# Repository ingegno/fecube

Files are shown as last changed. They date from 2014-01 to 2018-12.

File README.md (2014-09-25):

Manual sketches
===============
You can find the sketches from the manual on the [sketches overview page.](manual/sketches.md)

Ingegno Fe Cube
===============

The Ingegno Fe Cube is a RGB LED cube consisting of 9 LEDS, so like the Iron metal a [Cubic crystal system](http://en.wikipedia.org/wiki/Cubic_crystal_system)

A Fe Led Cube is driven with an Arduino. It can be used as an educational package into Arduino and making skills like lasercutting and 3D printing. This repository contains 

1. Data for a Scribus manual in English and Dutch (Italian planned)
2. Accompaning Arduino sketches to learn how the Cube can be programmed
3. The final complete sketch to load on a Fe cube and interact with it

There are many LED cubes available, and many manuals to create one exist. Nevertheless, in our view there was still a gap to be filled. A LED cube is ideal to impress visitors with, but we want to make it clear that this is a project within the grasp of beginners. The construction is not hard, and the programming can be kept simple (at least the parts the user would like to change). Hence a manual to go from no knowledge to a working Fe LED Cube.

Specific in the Arduino implementation is that it is shot based, so not a pattern table as is common. A shot that can load a pattern is present though for simple use. Next there is an event system to interact with the environment. In the Basic version this is a push button. In the Interactive version a distance sensor is added.

Prototypes
==========

The cube is a work in progress. Current protypes:

Prototype 3: Basic version
--------------------------
A lasercut frame, with plexiglass top. 3D printed optional cover. A pushbutton to interact with the cube: switch on/off and selecting an effect

Third prototype: basic version
Third prototype: basic version - no cover
Third prototype: basic version - different effect

Prototype 02
------------
A soldering board used to hold the components. In the future this must be hidden at the backside, now visible.

Second prototype

Prototype 01
------------
Based on conductive ink. Working, but pins come loose too easily

Firstprototype

The Manual
==========
The manual is aimed for use in Arduino courses. It starts with the basis: 

1. How to make a LED function with Arduino
2. Extend to handle a RGB LED
3. Create effects with the LED in a frame based manner
4. Extend to a FE Cube on a breadboard
5. Construct the FE Cube
6. Extend the code to generate effects on the FE Cube

Cool stuff the Cube can do
==========================
Some of the cool stuff you can do with the cube

1. The obvious use: use it as a light in the dark!
2. Double click to use it as dice roll. Currently 3 D6 dices are rolled
3. Show the theory of color mixing: two or more colors are blinked faster and faster. What color will result?
4. More to come ....

This course was created for use in an [Ingegno](http://ingegno.be) workshop. If you use it, send us a thumbs up if you liked it!

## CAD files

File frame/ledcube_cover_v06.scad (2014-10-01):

// Licence: Creative Commons, Attribution
// Created: 04-2014 by bmcage http://www.thingiverse.com/bmcage

// An LED lamp holder for easter

//diameter of the horizontal circle in mm
diameter = 100;  //[10:100]
//vertical scale factor to make it an egge (choose number from 1 to 2)
eggscale = 1.2;
//single shell thickness, take your nozzle diameter as minimum
th_shell = 0.4;
//base cylinder diameter in mm.
base_diam = 90; //[5:50]
//base extra height under egg
base_extra_height=2; // [0:20]
//The part to generate. Print both for rigidity, or increase shell thickness if only one!
part="both"; // [inner,outer,both]
//pattern to imprint on the egg
pattern = "circle"; //[triangle,circle,custom]
//size of the pattern as a scale, use something from 0.1 to 10
patternscale = 30; //
//if custom as pattern, the polygon to use as pattern (default here is simple square)
custom_polygon = [[[-1,1],[1,1],[1,-1],[-1,-1]],[[0,1,2,3]] ]; //[draw_polygon:100x100]
//how to put the pattern on the egg: random, a cylinder at the equator, a spiral from bottom to top, a double spiral, or onlyt at the top of the egg
repeattype = "topproject"; //[random, cylinder,spiral,doublespiral,topproject]
patternrepeat = 45;  //[1:100]
//random seed used to generate the pattern
random_seed = 10;  //[0:3200]
//rotate pattern itself around or not
rotate_pattern="true";  //[true,false]
//spiral complete circles from bottom to top
spiral_circles = 4; //[1:10]
//double helix extra offset
dh_angle=45; //[0:180]
//cuttoff below this height
h_cuttoff = 20; //[0:50]
//text to write on equator
text = "My LED Cube";
//fraction of the circumference to use for the text (value between 0.1 and 0.9)
textcircum = 0.9;
//show dxf
showdxf = "False";  //[True,False]
//scale the pattern
dxfscale  =0.06;
//dxf file to load
dxf_file= "/home/benny/Documents/kinderen/saya/toothless_v4.dxf";
dxfrepeattype = "cylinder"; //[cylinder,topproject]
dxfpatternrepeat = 6;  //[0:100]
//extra angle over the equator
dxfcilangle = 38; //[-90:90]


use <utils/build_plate.scad>;
use <MCAD/fonts.scad>;

//for display only, doesn't contribute to final object
build_plate_selector = 0; //[0:Replicator 2,1: Replicator,2:Thingomatic,3:Manual]

//when Build Plate Selector is set to "manual" this controls the build plate x dimension
build_plate_manual_x = 100; //[100:400]

//when Build Plate Selector is set to "manual" this controls the build plate y dimension
build_plate_manual_y = 100; //[100:400]

build_plate(build_plate_selector,build_plate_manual_x,build_plate_manual_y); 

//code begins, dummy module to indicate this
module test(){
  echo("test");
}

// sin(alpha) = R_C/R_S, cos(alpha) = sqrt(1- (R_C/R_S)**2)
// cutoff sphere is R_S*(1-cos(alpha)
sinalpha = base_diam/2 / (diameter/2);
cosalpha = sqrt(1-pow(sinalpha,2));
rcuttoff = diameter/2*(1-cosalpha);

module easterlamp(diam, transdist)
{
translate([0,0,transdist]) 
 	{
	 difference() 
		{
 		 scale([1,1,eggscale]) sphere(r = diam/2, $fn=60);
	 	 union(){
 		 scale([1,1,eggscale]) sphere(r = diam/2-th_shell*eggscale, $fn=60);
    	 translate([0,0,-eggscale*diam]) cylinder(r=base_diam/2, h=eggscale*diam);
		 }
		}
	}
}

module filledfoot()
{
cylinder(r=base_diam/2, h=base_extra_height+eggscale*rcuttoff+2, $fn=40);
}

module foot()
{
difference()
	{
 	 filledfoot();
 	 translate([0,0,-0.05])cylinder(r=base_diam/2-2*th_shell*eggscale, h=base_extra_height+eggscale*rcuttoff+2.1, $fn=40);
	}
}


module singlepattern()
{
//translate([0,0,eggscale*diameter/2+base_extra_height-0.1])
	{scale([patternscale,patternscale,1])
		{
		 if (pattern == "triangle")
		 { translate([0,0,1*eggscale*diameter/4]) linear_extrude(height = eggscale*diameter/4, convexity = 10)
           polygon(points=[[-1,0],[0,1],[1,0]]);
		 }
		 if (pattern == "circle")
		 { translate([0,0,1*eggscale*diameter/4]) cylinder(r=1, h=eggscale*diameter/4, $fn=10);
		 }
		 if (pattern =="custom")
		 {translate([0,0,1*eggscale*diameter/4]) linear_extrude(height = eggscale*diameter/4, convexity = 10)
			 polygon(points = custom_polygon[0], paths = custom_polygon[1]);
		 }
	   }
	}
}

module dxfpattern()
{
rotate([0,0,90])
scale([dxfscale,dxfscale,1])
translate([0,0,1*eggscale*diameter/4])
linear_extrude(height = eggscale*diameter/4)
   import (file = dxf_file);
}

module rotsinglepattern(rotangle)
{
 if (rotate_pattern=="true")
	{rotate([0,0,rotangle]) singlepattern();
	} else {
	 singlepattern();
	}
}

module manydxfpatterns()
{

if (showdxf == "True")
{
union()
 {
 if (dxfrepeattype == "cylinder")
  {
  for (i=[1:dxfpatternrepeat])
	{
	 translate([0,0,eggscale*diameter/2+base_extra_height-0.1])
		rotate([0,90-dxfcilangle,i*360/dxfpatternrepeat]) 
		{
		 dxfpattern();
	 	}
	}
  }
 if (dxfrepeattype == "topproject")
  {
	{
	 translate([0,0,eggscale*diameter/2+base_extra_height-0.1])
		{
		 dxfpattern();
	 	}
	}
  }
 }
}
}

module manypatterns()
{
random_numbers=rands(0,360,2*patternrepeat,random_seed);
union(){
 if (repeattype == "random")
  {
  for (i=[1:patternrepeat])
	{
	 translate([0,0,eggscale*diameter/2+base_extra_height-0.1])
		rotate([0,10+random_numbers[i-1]/360*160,random_numbers[i]]) 
		{
		 rotsinglepattern(random_numbers[i]);
	 	}
	}
  }
 if (repeattype == "cylinder")
  {
  for (i=[1:patternrepeat])
	{
	 translate([0,0,eggscale*diameter/2+base_extra_height-0.1])
		rotate([0,90,i*360/patternrepeat]) 
		{
		 rotsinglepattern(random_numbers[i]);
	 	}
	}
  }
 if (repeattype == "topproject")
  {
  //for (i=[1:patternrepeat])
	{
	 translate([0,0,eggscale*diameter/2+base_extra_height-0.1])
		//rotate([0,10+random_numbers[i-1]/360*160,random_numbers[i]]) 
		{
		 rotsinglepattern(random_numbers[0]);
	 	}
	}
  }
 if (repeattype == "spiral" || repeattype == "doublespiral")
  {
  for (i=[1:patternrepeat])
	{
	 translate([0,0,eggscale*diameter/2+base_extra_height-0.1])
		rotate([0,10+i*160/patternrepeat, i*360/patternrepeat*spiral_circles]) 
		{
		 rotsinglepattern(random_numbers[i]);
	 	}
	}
  if (repeattype == "doublespiral")
   {
   for (i=[1:patternrepeat])
	 {translate([0,0,eggscale*diameter/2+base_extra_height-0.1]) 
	  //difference()
     { 
		 rotate([0,10+i*160/patternrepeat, -i*360/patternrepeat*spiral_circles+dh_angle]) 
		 {
		  rotsinglepattern(random_numbers[i]);
	 	 }
	  //cube([diameter/2,diameter/2,diameter/2], center=true);
     }
	 }
   }
  }
 }
}


//process the text, we have beta_1 for the symbol, use beta_2 for border!
thisFont=8bit_polyfont();
x_shift=thisFont[0][0];
y_shift=thisFont[0][1];
theseIndicies=search(text,thisFont[2],1,1);
wordlength = (len(theseIndicies));

factorygap = 3;
scale_x = PI * diameter * textcircum/wordlength / x_shift;
scale_y = (diameter*eggscale/5) / y_shift;
//thicknessword = text_thickness * nozzlediam;

// Create the Text
module alltext() {
    for( j=[0:(len(theseIndicies)-1)] ) 
        {
			translate([0,0,eggscale*diameter/2+base_extra_height-0.1])
			rotate([90,0,j*360 * textcircum/wordlength])
        	translate([0,0,2.8*eggscale*diameter/8]) scale([scale_x,scale_y,1]){
          linear_extrude(height=1.2*eggscale*diameter/8) 
            polygon(points=thisFont[2][theseIndicies[j]][6][0],paths=thisFont[2][theseIndicies[j]][6][1]);
        }
      }
}

centeregg = eggscale*diameter/2+base_extra_height-0.1;

module fullobject()
{
if (showdxf == "True")
{
  dxfpattern();
}
if (part =="both")
	{
	 easterlamp(diameter-2*th_shell*eggscale+0.05, centeregg);
	}

if (part =="inner")
	{difference() {
   	 easterlamp(diameter-2*th_shell*eggscale-0.05, centeregg);
		 foot();
	 }
	}

if (part == "outer" || part == "both")
	{
 	 foot();
	 difference()
	 {
		color("Blue",0.5) easterlamp(diameter, centeregg);
		manypatterns();
		manydxfpatterns();
      alltext();
	 }
	}
}


//module easterlamp()
//{
if (h_cuttoff>0)
{
translate([0,0,-h_cuttoff+0.01])
 difference()
	{
	 fullobject();
	 translate([-diameter/2,-diameter/2,-0.01]) cube([diameter, diameter,h_cuttoff]);
	}
} else {
 fullobject();
}
//}
//alltext();
//easterlamp();
//manypatterns();

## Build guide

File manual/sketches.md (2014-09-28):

Arduino Sketches Manual
=======================

The basic sketches

1.  [RGB LED](../sketches/n01_RGB/n01_RGB.ino)

2.  [Mixing colors with RGB LED](../sketches/n02_RGB_mixing/n02_RGB_mixing.ino)

3.  [Multiplexing with 2 RGB LED](../sketches/n03_RGB_multiplex/n03_RGB_multiplex.ino)

4.  Extra: [Procedural effect on 2 RGB LED](../sketches/n04_RGB_procedural/n04_RGB_procedural.ino)

5.  [Pushbutton and RGB LED](../sketches/n05_RGB_pushbtn/n05_RGB_pushbtn.ino)

The Fe Cube sketches

1.  [Basic effect on the Fe Cube](../sketches/n10_cube_test/n10_cube_test.ino)
2.  [Pushbutton and Fe Cube](../sketches/n11_cube_pushbtn_test/n11_cube_pushbtn_test.ino)
3.  [Fe Cube with th fecube library](../sketches/n12_cube_library_test/n12_cube_library_test.ino)
4.  [Fe Cube final showtime sketch](../sketches/n13_cube_showtime/n13_cube_showtime.ino)

The fecube library: [fecube.h](../sketches/n12_cube_library_test/fecube.h)

List of effects for use with the library: [sketches](../effects)

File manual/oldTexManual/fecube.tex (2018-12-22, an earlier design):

\section{\engt{Introduction} \nedt{Introductie}}
\eng{In this booklet we will show how to create the Fe Cube. You will learn about LEDs, the Arduino, multiplexing, soldering, color theory, and more! You can buy a kit from Ingegno.be, or buy your components somewhere else.

The code of this manual can be found on \href{https://github.com/ingegno/linefollower1}{the Ingegno github page}.
}

\ned{In dit boekje zullen we je leren hoe je de Fe Cube kunt maken. Je zal leren over LEDs, de Arduino, multiplexing, solderen, kleurentheorie, en meer! Je kan een kit kopen met alle onderdelen van Ingegno.be, of je kan je eigen stukken gebruiken.

De code van deze handleiding kan gevonden worden op \href{https://github.com/ingegno/linefollower1}{de Ingegno github pagina}.
}

\subsection{\engt{The components} \nedt{De componenten}}
\eng{We will need the following components: 
\begin{enumerate}
 \item A breadboard
 \item 9 RGB-LED + 3 extra (we assume common cathode for the cube)
 \item 1 big RGB-LED (we assume common anode)
 \item 3 NPN + 1 extra (2N3904 normally)
 \item 1 pushbutton
 \item 9 220 $\Omega$ resistors + 3 extra
 \item 1 10k-20k $\Omega$, so 10000-20000$\Omega$, resistor
 \item many wires
 \item lasercut base for the cube
 \item iron wire pillars for the cube
 \item soldering plate for fixed components + connecter parts
\end{enumerate}
You will also need a soldering iron, and optionally you can make a cover for the cube, eg using 3D printing.

For an overview of meaning of the components, see the cheat sheet distributed seperately.
}

\ned{We zullen volgende componenten gebruiken: 
\begin{enumerate}
 \item Een schakelbord (Breadboard)
 \item 9 RGB-LED + 3 extra (we veronderstellen gemeenschappelijke kathode voor de kubus)
 \item 1 grote RGB-LED (we veronderstellen gemeenschappelijke anode)
 \item 3 NPN + 1 extra (2N3904 of gelijkaardig)
 \item 1 drukknop
 \item 9 220 $\Omega$ weerstanden + 3 extra
 \item 1 10k-20k$\Omega$ oftewel 10000-20000$\Omega$ weerstand
 \item veel draden
 \item lasercut basis voor de kubus
 \item ijzerdraad pilaren voor de kubus
 \item soldering plaat voor vaste componenten + connectiestukken
\end{enumerate}
Je zal ook een soldeerijzer nodig hebben, en optioneel kun je een afdekking maken voor de kubus, bv via 3D printen of in plexi met de lasercutter.

Voor een overzicht van de betekenis van de componenten, zie het overzicht die je apart gekregen hebt.
}

\subsection{Arduino}
\eng{We will make intensive use of Arduino, so you need to install the \href{http://Arduino.cc}{Arduino software}. Once installed, you can connect the Arduino board to your PC via de \textsc{usb} port.  In the programming environment you installed you can write programs, and load those on the Arduino board. They will be executed there as long as the Arduino has power.

}
\ned{We zullen intensief gebruik maken van Arduino, dus moet je de \href{http://Arduino.cc}{Arduino software} installeren op je laptop.
Eenmaal geinstalleerd kun je nu je Arduino bord koppelen aan je computer via de \textsc{usb} poort. In de programmeeromgeving van Arduino kun je programma's schrijven en die opladen naar de Arduino, waar ze dan uitgevoerd worden zolang er stroom is.
}

\subsection{\engt{Programming with Arduino} \nedt{Programmeren met Arduino}}
\eng{A programming language needs to be understood by a computer. Unfortunately computers are still a little bit dumb, so you are not allowed to make errors! It's like a writing contest in which you need to obtain a 10/10 every time. So take time to learn the form of the language. See the specific sheet 'Programming with Arduino' distributed with this manual.}

\ned{Een programmeertaal moet verstaan worden door een computer. Spijtig genoeg zijn computers nog altijd een beetje dom, dus mag je geen enkele fout maken! Het is zoals een dictee waar je altijd 10/10 moet halen. Neem dus de tijd om de structuur en taal van de Arduino te leren. Zie de blaadjes 'Programmeren met Arduino' die je bij deze gids kan downloaden.}

\section{\engt{Lesson 1: One LED Circuit} \nedt{Les 1: \'E\'en LED circuit}}
\eng{We will make a circuit with one LED, which we will program to blink. The Arduino outputs 5 Volt, while the LED is designed for 3 Volt. Hence we will use a resistor to reduce the voltage over the LED. You can calculate the resistor you need with \url{http://led.linear1.org/1led.wiz}.}

\ned{We maken een circuit met \'{e}\'{e}n enkele LED, welke we zullen programmeren om te pinken. De Arduino levert 5 Volt, terwijl de LED gemaakt is voor 3 Volt. We moeten dus een weerstand gebruiken om het voltage over de LED te verminderen.  Je kan de weerstand die je nodig hebt berekenen met  \url{http://led.linear1.org/1led.wiz}.}

\subsection{\engt{One pin} \nedt{\'E\'en pin}}
\eng{Make the circuit as indicated in Fig.~\ref{f:lesson1_onepin}. Use your breadboard and wires to make the connections. A wire from pin 2 to row 10 on the breadboard. Then the resistor of R=330 $\Omega$ from row 10 to row 6, the LED anode from row 6 to row 5, and finally a wire from row 5 to the GND pin on the Arduino. You can see }

\ned{Maak het circuit zoals gegeven in Fig.~\ref{f:lesson1_onepin}. Gebruik je schakelbord en draden om de connecties te maken. Dus hier, een draad van pin 2 naar rij 10 op je schakelbord. Dan de resistor met weerstand R=330 $\Omega$  van rij 10 naar rij 6, de LED anode van rij 6 naar rij 5, en uiteindelijk een draad van rij 5 naar de GND pin op de Arduino.}

\begin{figure}
  \centering
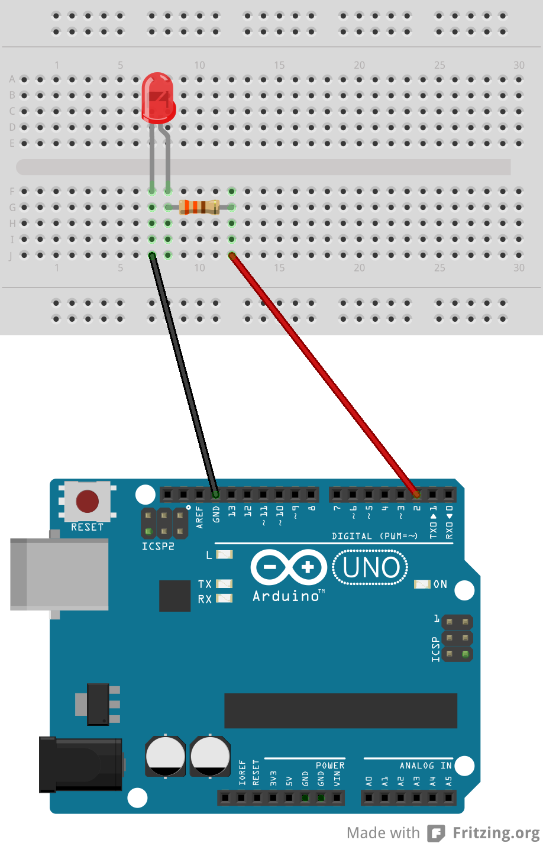
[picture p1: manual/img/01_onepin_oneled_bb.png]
  \ \ 
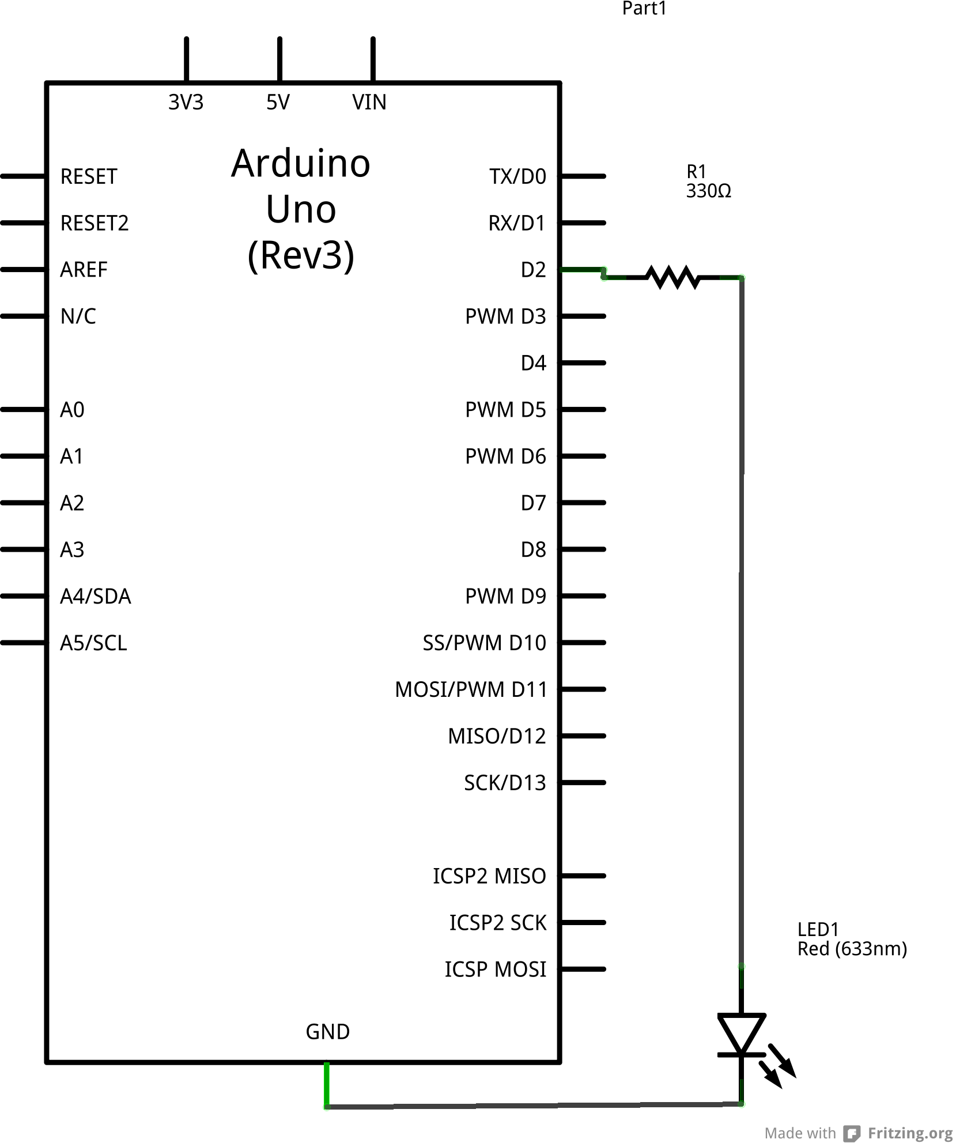
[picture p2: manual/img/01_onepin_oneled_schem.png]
    
\caption{\engt{Using one pin and the ground, we can make a LED burn. Left with breadboard, right as a schematic}
\nedt{Met een pin en de grond kunnen we een LED doen branden. Links met breadboard, rechts als schema.}}
\label{f:lesson1_onepin}       % Give a unique label
\end{figure}

\eng{We now need to write a program that sets the power to pin 2 on and off every second, so that the LED blinks. You see the code in Code \ref{c:l1_a}.}
\ned{Nu moeten we een programma schrijven dat de stroom naar pin 2 aan en af zet elke seconde, zodat de LED pinkt. Je vindt de code in Code \ref{c:l1_a}.}

\begin{code}\label{c:l1_a}
 \ \newline
\inputardfull{\string"../../sketches/old_versions/v01/Fe_cube_01_led_one_pin/Fe_cube_01_led_one_pin.ino\string"}
\end{code}
\eng{Congratulations, you made your first programmable LED.}
\engo{\begin{doE}
       Change the program so that the LED blinks every 3 seconds, with 1 second off. Next, what does it happen if you blink every 40 milliseconds and every 10 milliseconds?
     \end{doE}
}
\ned{ Proficiat, je hebt je eerste programmeerbare LED gemaakt.}
\nedo{\begin{doN}\begin{enumerate}
                  \item  Verander nu je programma (Code 1) zodat de LED elke 3 seconden pinkt, met 1 seconde af. \\
                  Vervolgens, wat gebeurt er als je elke 40 milliseconden pinkt en als het elke 10 milliseconden pinkt? 
                  \item Wat moet je doen als je twee LED's wilt doen pinken? of afwisselend pinken? 
                  Probeer het eens.
                 \end{enumerate}

          \end{doN}
}
\eng{How does it work? Well, the pins from 1 to 13 can have a HIGH state or a LOW state. HIGH means the pin has 5V of power, while LOW means the pin is in the ground state GND. We say that current flows from the positive voltage of 5V (the + side) to the GND (the - side). This is somewhat annoying as the actual quantum particles used here, called electrons, actually go the other way. So, they flow from the minus to the plus. This because they have themself a negative charge, so they are repelled by the negative GND. Theoretically you could use other quantum particles however! Anyway, the direction of the current, from + to - is just an agreement between scientists. 

The power source here is 5V, which is an indication of how much work you can do. A lot of power means you can do a lot of work! To burn a LED we don't need a lot of power however, so we reduce the power used to burn the LED by adding a resistor. This increases the lifetime of the LED.

The resistor is just that, it resists the flow of the current, and hence the quantum particles loose some of their power going through the resistor. Not only will the particles have less power however, there will also be less particles that can pass the resistor every second, or in other words, the current is also lower. So a resistor will decrease the current, and after passing it there is also less power left to do the rest of the circuit. 

Next comes the LED for the current. All the remaining power will be used to go through the LED and generate light. A LED only produces light if the anode (long leg, +) is connected to the voltage (positive side), and the cathode (short leg) towards the GND side. If you put the LED around (try it!) there will be no light. There will also be very little current going through the LED in this way because not only does it produce no light, it will also resist the current a lot if the anode is connected to the GND. An exploded view of a LED is shown in Figure \ref{f:LED}.}

\ned{Hoe werkt ons circuit? Wel, de pinnen van 1 tot 13 kunnen een HIGH staat en een LOW staat hebben. HIGH betekent dat de pin 5V krachtbron heeft, terwijl LOW betekent dat de pin zich in de grond staat bevindt. We zeggen dat stroom sroomt van de positieve voltage van 5V (de + zijde) naar de GND (de - zijde). dat is een beetje vervelend gezien de echte kwantumdeeltjes die hier gebruikt worden, electronen genoemd, eigenlijk de andere kant op stromen, dus van de min naar de plus. Dit omdat elektronen zelf negatief zijn, en dus afgestoten worden door de negatieve lading van de GND. Theoretisch zou je evenwel andere kwantumdeeltjes kunnen gebruiken! Hoe dan ook, de richting van de stroom, van + naar -, is gewoon een afspraak tussen wetenschappers om geen verwarring te doen ontstaan. 

De krachtbron is hier 5 Volt (5V), wat een indicatie is van hoeveel werk je kan doen. Veel kracht betekent dat je veel werk kan doen! Om een LED te doen branden hebben we evenwel niet veel kracht nodig, dus beperken we die door een resistor toe te voegen die de kracht over de LED zal beperken. Dit verhoogt de levensduur van de LED.

De resistor of weerstand doet wat de naam zegt: het resisteert of weerstaat de stroom. Bijgevolg verliezen de kwantumdeeltjes een deel van hun kracht als ze door een weerstand stromen. Niet alleen zullen de deeltjes minder kracht hebben erna, er zullen ook minder deeltjes passeren elke seconde. De stroom is dus verminderd. Een weerstand of resistor zal dus de stroom verminderen en na het passeren zal er ook nog eens minder kracht over zijn om door de rest van het circuit te stromen.

Daarna komt de LED voor de stroom. Alle overblijvende kracht zal gebruikt worden om door de LED te gaan en licht te genereren. Een LED maakt alleen licht als de anode (lange been, +) is geconnecteerd naar het voltage (de positieve zijde), en de kathode (korte been, -) naar de GND zijde.
Als je de LED ronddraait (probeer het!) zal er geen licht schijnen. Er zal ook maar heel weinig stroom vloeien dan, gezien de LED niet enkel geen licht maakt dan maar ook de stroom sterk zal weerstaan. Een LED in het groot zie je in Figuur \ref{f:LED}.
} 

\begin{figure}
  \centering
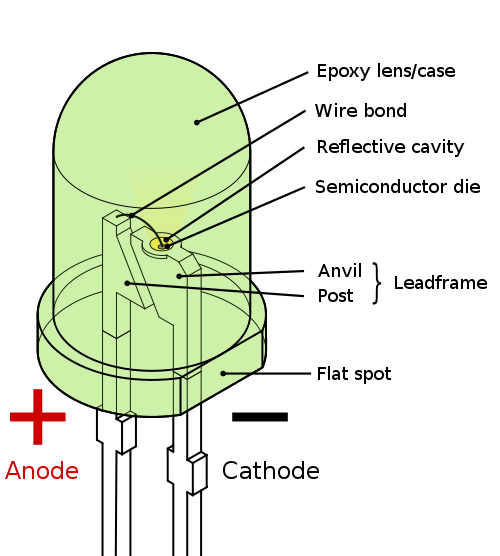
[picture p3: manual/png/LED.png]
  
\caption{\engt{Blow up view of a LED}
\nedt{Een LED in het groot}}
\label{f:LED}       % Give a unique label
\end{figure}

\engo{\begin{doE}
      Study the schematic to the right of Figure \ref{f:lesson1_onepin}. A schematic is often more clear to work with than the wires drawn to the left. Every component has its own symbol. For example, the LED is a triangle ending on a short vertical line, and two small arrows indicating the light that is emitted. The triangle in this symbol can be interpreted as an arrow indicating the direction of the current: from + to -. The light leaves the LED in the same direction.
     \end{doE}
}
\nedo{\begin{doN}
      Bestudeer het schema aan de rechterkant van Figuur  \ref{f:lesson1_onepin}. Een schema is vaak duidelijker om mee te werken dan de draden die je aan de linkerkant ziet. Elke component heeft zijn eigen symbool. Een LED is een driehoek die eindigt op een korte vertikale lijn, en twee kleine pijlen die het licht voorstellen die de LED uitzendt. De driehoek in dit symbool kun je interpreteren als een grote pijl die de richting van de stroom aanduidt: van + naar -. Het licht verlaat de LED in dezelfde richting in het symbool.
     \end{doN}
}

\eng{Do you want to know how the LED produces light? Well, that is quantum physics, something most people never learn. Let's explain a bit. To understand quantum physics, you need to work with the quantum particles, which here are electrons. Remember, the electrons go from GND to the pin 2, so from the cathode (-) to the anode (+) of the LED. 

At the cathode side, the LED has what is called an n-type material. This is a material that has an excess in negative electrons, hence n. At the anode side there is a p-type material. This material has a shortage of electrons, which we call holes: it is the absense of an electron within the material. The p-type material passes current by moving holes around. The n-type material by moving electrons around. 

So, if electrons arrive at the cathode, they create a surplus of electrons, and the electrons are pushed towards the p-type material. There, they fall into a hole, and this is a quantum effect that creates a small quantum of energy, which is a photon, and which we see here as the light of the LED. This effect is called \textit{Electroluminescence}, and only happens from an n-type material to a p-type material. Between other materials that transport electrons, the electrons can loose energy gradually, instead of in quanta. 

Now, after this drop, there are less holes in the p-type material in the direction of the n-type material, so the holes in the p-type material move towards this place so as to rebalance the amount of holes. The resulting shortage of holes at the cathode side then causes an electron to leave the p-type material entirely (the material likes it's amount of holes and wants to keep it like that), creating a new hole there.

If you plug out the LED, rotate it, and plug the LED back in the breadbroard, you connect the n-type material to the positive voltage. The electrons of the n-type material then just flow towards this voltage creating too little electrons in the material. This can only be corrected by an electron leaving the p-type material and like that creating a new hole there and a new electron in the n-type material. However, this clearly does not produce light (as the electron does not fall into a hole), but the electrons also resist a lot against moving from the p-type material to the n-type material (they are comfortable where they are and resist jumping, or seen differently, the material likes it's amount of holes and tries to keep it like that.). 
}
\ned{Je wilt weten hoe de LED licht produceert? Wel, dat is kwantumfysica, en de meeste mensen leren daar nooit over. Laat ons het een beetje uitleggen. Om kwantumfysica te verstaan moet je met kwantumdeeltjes werken, dus hier de elektronen. Weet je nog dat de elektronen stromen van de GND naar de pin 2, dus van de kathode (-) naar de anode (+) van de LED? 

Aan de kathode zijde zit wat we een n-type materiaal noemen. Dit is een ma\-te\-riaal die een overschot aan negatieve electronen heeft, daarom n. Aan de anode zijde zit een p-type materiaal. Dat is een materiaal die een tekort aan elektronen heeft, wat we gaten noemen: het is de afwezigheid van een elektron in het materiaal. Het p-type materiaal laat stroom door door gaten rond te bewegen. Het n-type materiaal laat stroom door elektronen rond te bewegen.

Dus, als elektronen toekomen aan de kathode cre\"eren ze daar een surplus aan elektronen, en de elektronen worden geduwd in de richting van het p-materiaal. Daar aangekomen vallen ze in een van de gaten, en het is dit kwantumeffect dat een klein kwantum aan energie cre\"eert, welke een foton is wat we waarnemen als het licht van de LED. Dit effect noemen we  \textit{Electroluminescentie}, en het gebeurt enkel bij overgang van een elekrton van een  n-type materiaal naar een p-type materiaal. Tussen andere materialen die elektronen doorlaten kunnen de elektronen altijd gradueel hun energie verliezen, in plaats van via een kwantum. 

Nu, na het vallen in het gat zijn er minder gaten in het p-type materiaal aan de kant van het n-type materiaal, dus zullen de gaten bewegen in die richting om terug een gelijke balans in het materiaal te hebben. Hierdoor eindigen we met een tekort aan gaten aan de kathode zijde, welke op zijn beurt ervoor zal zorgen dat een elektron het materiaal zal verlaten (het materiaal houdt van zijn aantal gaten en wil het zo houden), waardoor een nieuw gat ontstaat daar.

Als je de LED omdraait, connecteer je het n-type materiaal aan de positieve krachtbron. De elektronen van het n-type materiaal stromen dan gewoon naar deze krachtbron, zo een tekort aan elektronen veroorzakend daar. Dit kan enkel gecorrigeerd worden door een elektron dat het p-type materiaal verlaat, en zo een nieuw gat cre\"eert, en een nieuw elektron in het n-type materiaal. Dit evenwel zal duidelijk geen licht produceren (gezien het elektron niet in een gat valt), maar de elektronen bieden ook heel veel weerstand in het bewegen van het p-type materiaal naar het n-type materiaal (ze zijn bij wijze van spreken comfortabel waar ze zijn, het materiaal houdt van zijn aantal gaten en wil het zo houden).
}
\begin{figure}
  \centering
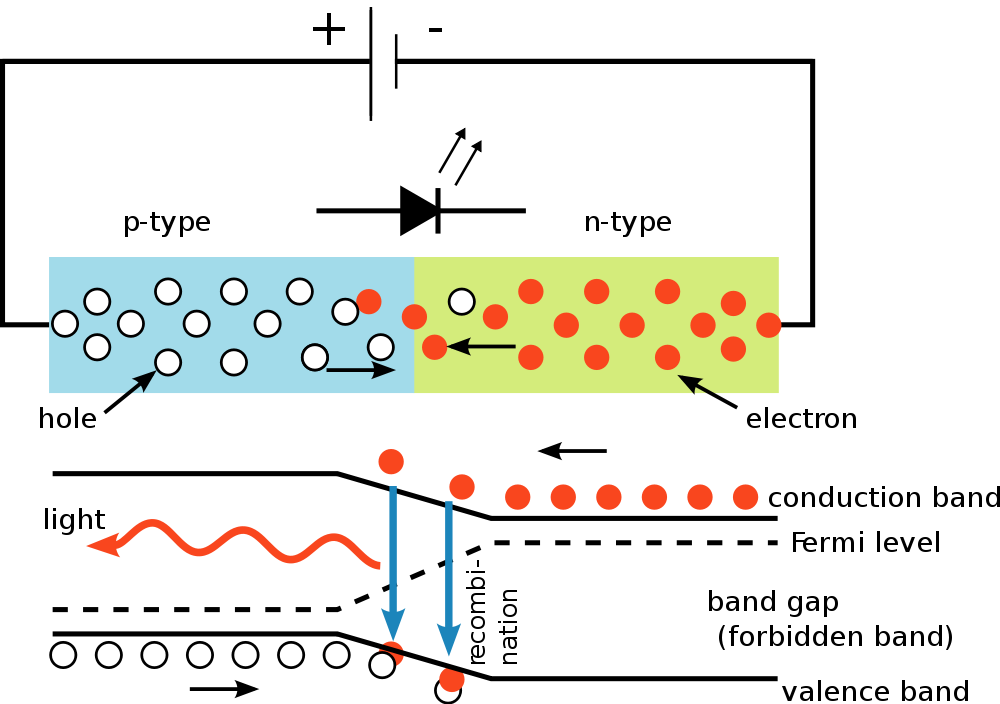
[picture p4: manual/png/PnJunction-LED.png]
  
\caption{\engt{A PN junction as used in a LED}
\nedt{Een PN overgang zoals gebruikt in een LED} (\textcopyright Wikimedia Commons S-kei)}
\label{f:NPJunction}       % Give a unique label
\end{figure}

\subsection{\engt{LED with NPN, two pins} \nedt{LED met NPN, twee pinnen}}
\eng{Controlling the LED worked great, but we will later need the ability to cut off the power on the Cathode (-) side too, so towards the ground (GND). In this section we will learn how to do that. One possibility is to use a switch: a component that is on and off depending on a signal. Just like the light switches you use every day and where the input is the pressure of your hand touching it. We will use the smallest switch possible: an NPN gate. This piece is the half cilindrical black piece with 3 legs in your box, see Fig.~\ref{f:Tr_Pinouts}. 
}

\ned{De LED controleren werkte perfect, maar later zullen we de mogelijkheid willen om de stroom af te sluiten aan de Kathode zijde (-), dus aan de grond (GND). In deze sectie zullen we dat leren. Een mogelijkheid is om een schakelaar te gebruiken: een component die aan of af is afhankelijk van een signaal. Net zoals de lichtschakelaars die je dagelijks gebruikt, en waar de input de druk van je hand is. We zullen de kleinst mogelijke schakelaar gebruiken: een NPN brug. Dit componentje is de halve zwarte cilinder met 3 poten in je doos, zie Fig.~\ref{f:Tr_Pinouts}. 
}

\begin{figure}
  \centering
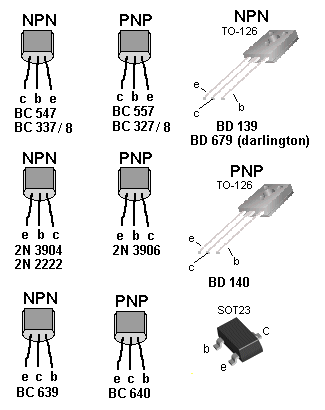
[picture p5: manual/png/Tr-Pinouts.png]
   
\caption{\engt{Different NPN and PNP transistors. There is no standard for the pinouts, so use a datasheet, or try it with a LED like we do. If it does not work, use other legs as in this Picture!}
\nedt{Verschillende NPN en PNP transistoren. Er is geen standaard voor de beentjes, refereer naar een datasheet, of probeer het met een LED zoals wij hier doen. Als het niet werkt, gebruik andere beentjes zoals in deze Figuur!}}
\label{f:Tr_Pinouts}       % Give a unique label
\end{figure}

\eng{As you can see in that figure, there is no standard for identifying the legs of the transistor. Normally, the one you have will have, looking at the flat side of NPN, the left leg as the in-side for the current (C, from collector), the right leg is the out-side (E, from extruder/emitter) that goes to the GND, and the middle leg is the P or positive control (B, from the word base). If there is positive power on the P, the NPN gate is open and current can flow to the ground state. If there is no power on the P, the NPN gate is closed. Our complete circuit is then given in Fig.~\ref{f:lesson1_twopin}}

\ned{Zoals je in die figuur ziet is er geen standaard om de beentjes van een transistor te identifici\"eren. Normaal zal het als volgt zijn voor degene die jij zult gebruiken: hou je het rechtop en kijk je naar het vlakke stuk van de NPN, dan is de linkerpoot de in-zijde voor de stroom (C, van collector, waar er gecollecteerd wordt), de rechterpoot de uitgangzijde (E, van emittor of extruder) die naar de GND gaat, en het middelste been is de P of positieve controle (B, van basis). Als er een positieve stroom is op P, laat de NPN brug stroom door. Is er geen stroom op de P, dan kan er geen stroom door en is het circuit dus onderbroken. Het complete circuit is gegeven in Fig.~\ref{f:lesson1_twopin}.
}

\begin{figure}
  \centering
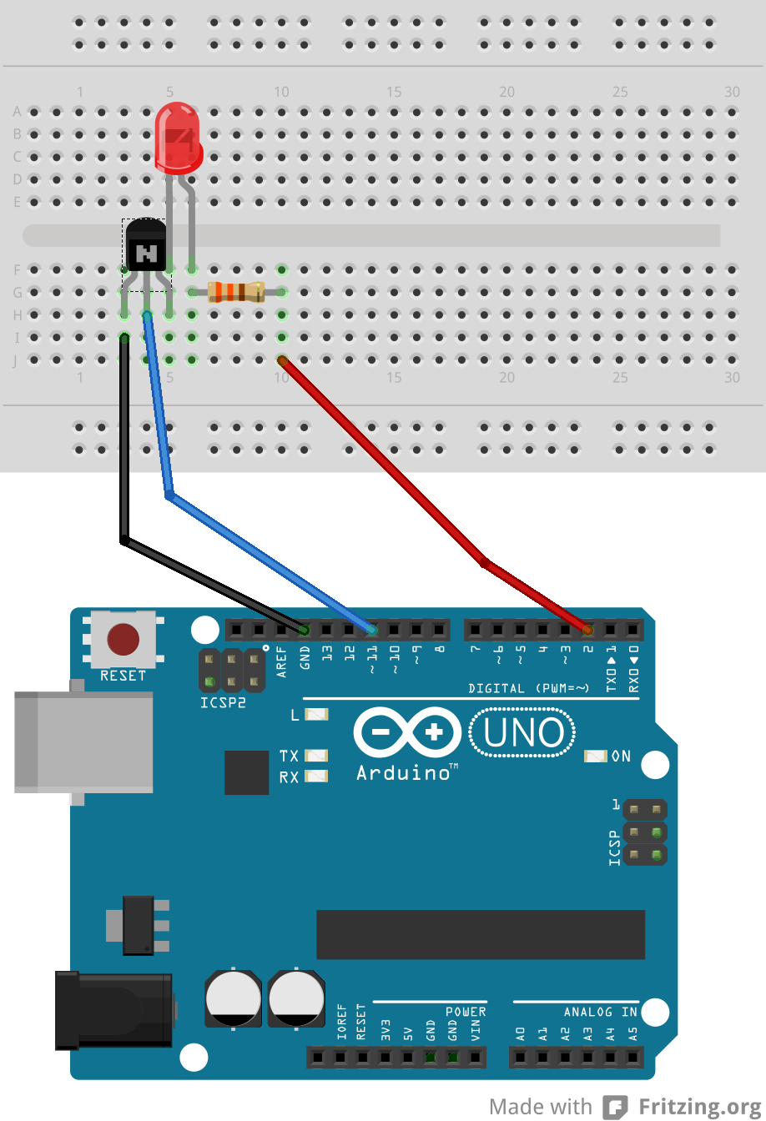
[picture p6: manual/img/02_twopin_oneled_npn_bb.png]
   \ \ 
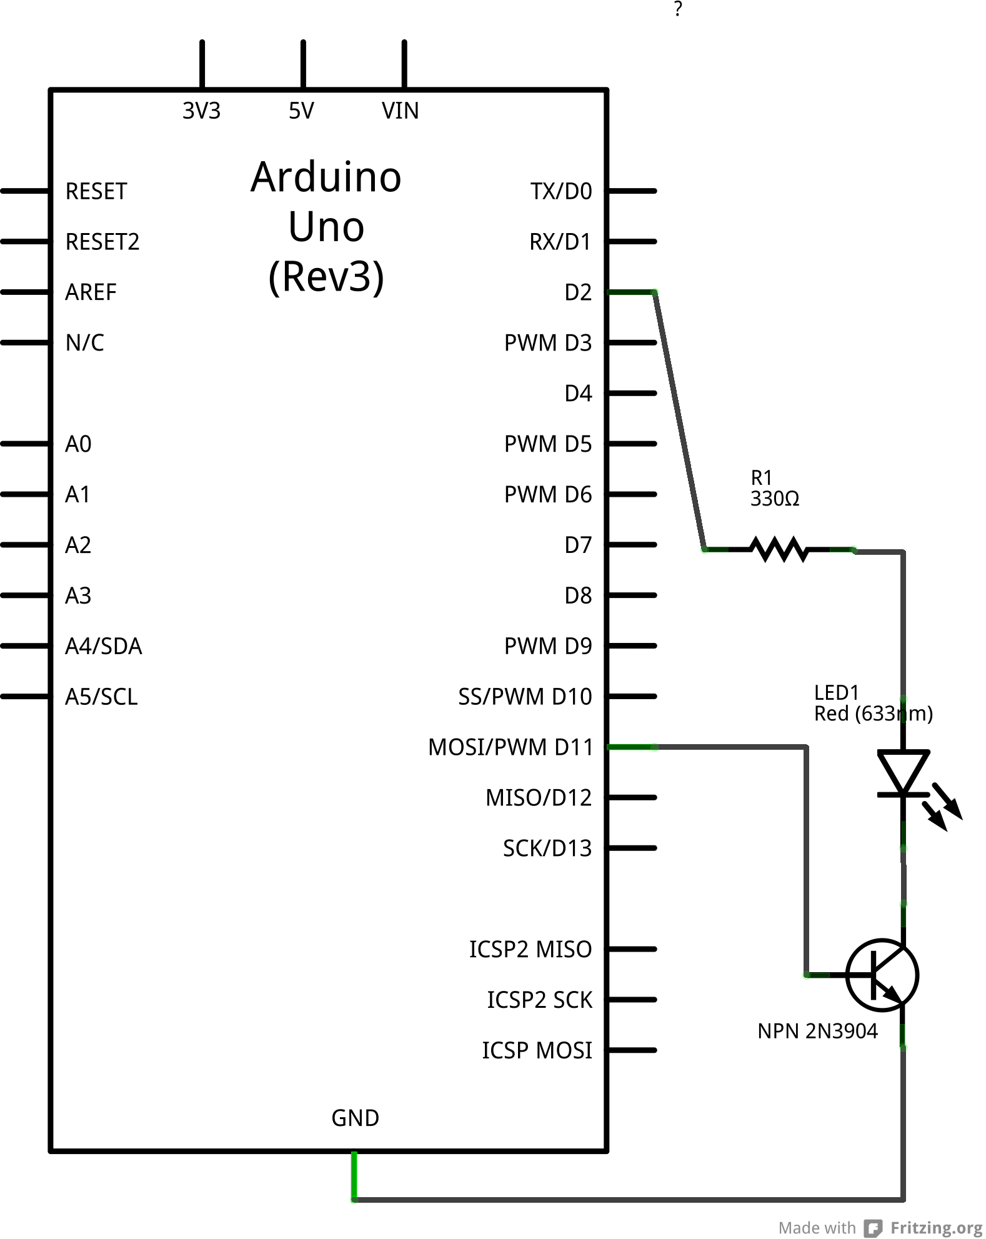
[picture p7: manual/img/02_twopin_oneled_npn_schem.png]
  
\caption{\engt{Using two pins and an NPN gate, we can switch off the LED on both sides}
\nedt{Met twee pinnen en een NPN brug kunnen we de LED afzetten aan beide kanten.}}
\label{f:lesson1_twopin}       % Give a unique label
\end{figure}

\eng{We now adapt our program so that the pin to the NPN is used to control the LED and make it blink. To see that the NPN works as expected, we cycle the LED through three states each for a second: 
\begin{enumerate}
 \item Both Arduino pins on;
 \item Only anode pin on
 \item only pin to NPN on. 
\end{enumerate}
Correct behavior means this will result in a LED on for a second, and off for two seconds.}

\ned{Nu moeten we ons programma aanpassen zodat ook de pin naar de NPN gebruikt wordt om de LED te doen blinken. Om vast te stellen dat de NPN werkt zoals verwacht laten we de LED door drie standen gaan, elk voor een seconde:
\begin{enumerate}
 \item Beide Arduino pinnen aan
 \item Enkel de anode pin aan
 \item Enkel de pin naar de NPN aan.
\end{enumerate}
Correct gedrag zou dan moeten zijn dat de LED aan is voor een seconde en uit voor twee seconden.}

\begin{code}\label{c:l1_b}
 \ \newline
\inputardfull{\string"../../sketches/old_versions/v01/Fe_cube_01_led_npn/Fe_cube_01_led_npn.ino\string"}
\end{code}

\eng{You would like to know how the NPN works? Well, this is a transistor, we refer to it as a bipolar junction transistor. The LED we explained before is a PN junction. Our NPN indeed consists now of 3 materials that have been connected: A n-type material, a p-type material, and then again an n-type material. This time, the p-type material has only little holes. If we connect it to GND (-), there will even be less holes. As we explained before, a p-type material conducts current with holes, so no current can flow then, and the junction is closed.

If we put a voltage over the p-type material, the material loses its electrons, and obtains more holes. This means we can have now current from the p-material which is the base, to the emitter n-material, which is just the same as in our PN junction in the LED. So, the emitter 'emits' our electrons into the base.

So, how do we obtain current from the n-type material, to the n-type material? This should not be possible! The trick is that the p-type material when connected to voltage (+) obtains extra holes, and it can form a line of holes from the emitter n-type material to the collector n-type material. Now something extraordinary happens: the electrons can jump from hole to hole via this line from the emittor to the collector. Moreover, they can do that much, much faster than the holes themself move. In other words, we have an amplification of the current at the base, see Fig.~\ref{f:NPNactive}. If we increase the current in the base, more holes flow in the p-type material, and hence more lines start to connect the emittor with the collector. We can hence convert a small signal at the base into a large signal over the NPN.

Note that we put in our test circuit a 5V signal over the base, which in itself is sufficient to power the LED. Because of this, our base current is actually sufficient to power the LED. This is not a problem, just something to be aware of.
}

\ned{Je zou graag weten hoe de NPN werkt? Wel, dit is een transistor, specifiek een Bipolaire transistor. De LED die we hiervoor gezien hebben is een PN overgang. Onze NPN nu is inderdaad een combinatie van 3 materialen die geconnecteerd worden: een n-type materiaal, een p-type materiaal, en dan opnieuw een n-type materiaal. Deze keer heeft het p-type materiaal maar weinig gaten. Als we het verbinden met de GND (-) zullen er nog minder gaten zijn. Zoals we uitgelegd hebben, een p-type materiaal geleidt stroom via de gaten, dus kan er geen stroom vloeien, en is de overgang gesloten.

Als we een voltage over het p-type ma\-te\-riaal plaatsen, verliest het materiaal zijn elektronen, en krijgt dus meer gaten. Dit betekent dat we nu stroom kunnen hebben van het p-materiaal welke we de basis noemen, naar de emitter, welke een van de twee n-materialen is. Dit is hetzelfde als de PN overgang in de LED. De emitter zendt elektronen in de basis (\textit{emit} is Engels voor uitzenden).

Goed, hoe krijgen we dan stroom van het n-type materiaal naar het andere n-type materiaal? Dat zou niet mogelijk mogen zijn! De truck is dat het p-type materiaal eenmaal verbonden met een voltage (+) extra gaten krijgt, en het kan een lijn van gaten vormen van het emittor n-type materiaal naar het collector n-type materiaal. Nu gebeurt iets speciaals: de elektronen kunnen springen van gat naar gat via deze lijn van de emittor naar de collector. En wat meer is, ze kunnen dat veel, veel, vlugger doen dan dat de gaten zelf kunnen bewegen. In andere woorden, we krijgen een versterking van de stroom aan de basis, zie Fig.~\ref{f:NPNactive}. Als we de stroom aan de basis verhogen, stromen er nog meer gaten in het p-type materiaal, en kunnen er meer 'verbindingslijnen' tussen emittor en collector. We kunnen dus een klein signaal aan de basis omvormen tot een groot signaal over de NPN.

Merk op dat we in ons circuit een 5V signaal over de basis plaatsen, welke op zijn eentje al genoeg is om de LED te doen branden. Hierdoor is onze stroom aan de basis al genoeg om de LED aan te sturen. Dit is geen probleem, gewoon iets waar je je bewust van moet zijn.
}

\begin{figure}
  \centering
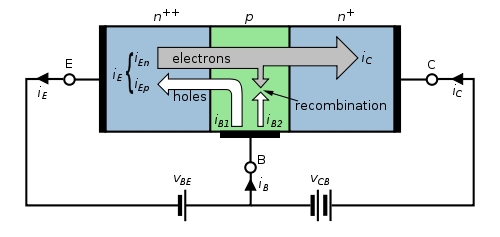
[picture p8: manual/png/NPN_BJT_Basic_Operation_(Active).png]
   
\caption{\engt{An NPN transistor when the junction is active}
\nedt{Een NPN transistor als de overgang open staat.}}
\label{f:NPNactive}       % Give a unique label
\end{figure}

\engo{\begin{doE}
      We can switch on and off a LED using a NPN transistor. We should be able to reduce the current over the Base of the NPN and still obtain a functioning circuit. So, add a resistor between pin 11 and the base of the NPN. How high can you go with the resistor? Could this be a way to test the strength of the resistor?
     \end{doE}
}
\nedo{\begin{doN}
      We kunnen een LED aan en af schakelen met een NPN transisor. We zouden in staat moeten zijn om de stroom over de Basis van de NPN te verminderen en toch een werkend circuit overhouden. Probeer dit, voeg een weerstand toe tussen pin 11 en de basis van de NPN. Hoe hoog kan je gaan met de resistor? Zou dit een manier kunnen zijn om de sterkte van de resistor te testen?
     \end{doN}
}

\subsection{\engt{Fade: Analog pulse width modulation} \nedt{Fade: Analoog puls breedte moduleren}}
\eng{If you did the Task in the first section, you know that by blinking fast you can create the impression of a LED that is always on. However, as the LED was not on all the time, the LED was less bright! So, we can influence how bright a LED will be by not having it switched on all the time. The trick is to avoid seeing the LED blinking. Fortunately, humans have \href{http://en.wikipedia.org/wiki/Persistence_of_vision}{Persistence of vision}. Persistence of vision is the phenomenon where an image that is seen for only a fraction of a second will continue to be "seen" by your brain even after the original image has vanished or moved. This is the same principle behind film and television, where a rapidly changing image tricks your brain into seeing continuous motion. By turning our LED on and off rapidly, we can trick the brain into seeing an "average" value of brightness. Humans see 24 images per second, so if we switch on and off in roughly 40 milliseconds, we will not discern that the LED is blinking, but will instead see it less bright! 

We can use the \ardo{delay} function of Arduino to achieve this: blinking the LED for the required amount of time. Fortunately, there is an easier way: Pulse Width Modulation (PWM). In this, a block wave is generated over a digital pin of the Arduino. A block wave is a wave between 0 (off) and 1 (on). In Arduino, you use the \ardo{analogWrite} function on a digital pin to achieve this. See it schematically in Fig.~\ref{f:PWM}. Note that older Arduinos only allow this on pin 9, 10 and 11! So check where your version of Arduino allows this function, You recognize these pins on the board with the sign \~.

The function is called \ardo{analogWrite} because it is a wave over a digital pin. Analog always refers to waves, whereas digital refers to 0s and 1s. So if you make a wave with 0 and 1 (see the figure to see it is a wave), we call it again analog. The function analogWrite allows a value from 0 (=always off) to 255 (=always on). 
}

\ned{Als je de opdracht uit de eerste sectie gedaan hebt, weet je dat door vlug te blinken, je de illusie kunt cre\"eren dat de LED altijd aan is. Evenwel, de LED is niet de hele tijd aan, bijgevolg was de LED wel minder helder! Dus, we kunnen be\"{\i}nvloeden hoe helder een LED is door deze te doen blinken. De truck is te verhinderen dat de mensen hem effectief zien blinken. Gelukkig hebben mensen persistentie van beelden, denk aan de \href{http://nl.wikipedia.org/wiki/Phenakistiscoop}{Phenakistiscoop}, uitgevonden door de Belg Plateau in Gent. Persistentie van beelden is het fenomeen waarbij een beeld dat maar een fractie van een seconde gezien is, door je brein zal blijven gezien worden, zelfs nadat het originele beeld verdwenen is of bewogen heeft. Dit is het principie achter film en televisie. Door de LED vlug aan en uit te schakelen, kunnen we onze brein bedotten in het zien van een ``gemiddelde'' waarde van helderheid. Mensen zien 24 beelden per seconde, als we dus aan en uit schakelen in ongeveer 40 milliseconden, zullen we niet in staat zijn te zien dat de LED aan het blinken is, maar zullen we in plaats daarvan een gedimd licht zien!

We zouden de \ardo{delay} functie van Arduino kunnen gebruiken om dit te programmeren: de LED aan en uit zetten voor een bepaalde tijd. Maar het kan eenvoudiger: Puls Breedte modulatie (PWM). In deze wordt een blokgolf gegenereerd over een digitale pin van de Arduino. Een blokgolf is een golf tussen 0 (uit) en 1 (aan). In Arduino doe je dit met de \ardo{analogWrite} functie op een digitale pin. Zie het schematisch in Fig.~\ref{f:PWM}. Merk op dat oudere Arduino's dit enkel toelaten op pin 9,10, en 11! Controleer waar jouw versie van Arduino dit toelaat, je herkent de pins op het bord met het teken \~.

De functie wordt analogWrite genoemd omdat het een golf is over een digitale pin. Analoog refereeert altijd aan golven, terwijl digitaal refereert naar nullen en eenen. Als je dus een golf maakt met 0 en 1 (zie de figuur dat het inderdaad op een golf lijkt), noemen we het opnieuw analoog. De functie analogWrite laat waarden toe van 0 (=altijd af) tot 255 (=altijd aan).
}

\begin{figure}
  \centering
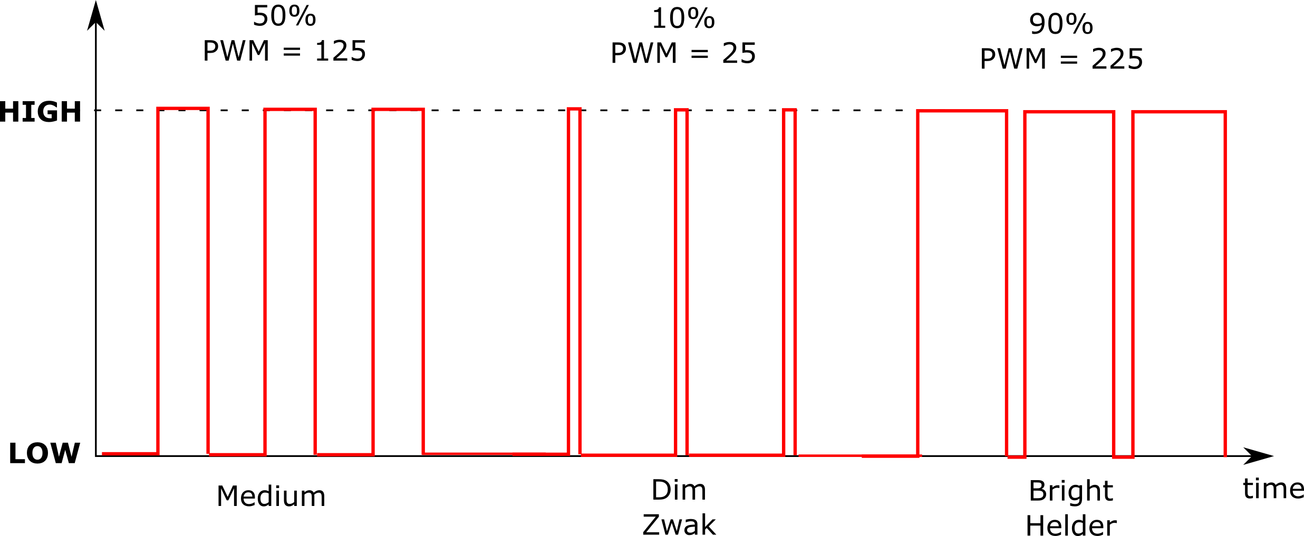
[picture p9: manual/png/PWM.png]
   
\caption{\engt{How PWM works in practice: over the pin a block wave is generated.} \nedt{Hoe PWM in de praktijk werkt: over de pin wordt een blokgolf gegenereerd.}}
\label{f:PWM}
\end{figure}

\begin{figure}
  \centering
   \ \ 
  
\caption{\engt{The circuit to use PWM to change the brightness. Yes, it is identical to the previous one, all changes are in code}
\nedt{Het circuit om PWM te gebruiken om de helderheid te wijzigen. Ja, het is identiek aan het eerdere circuit, alle wijzigingen zijn in software.}}
\label{f:lesson1_twopin_PWM}       % Give a unique label
\end{figure}

\eng{The next question is then where to apply the \ardo{analogWrite}, to the NPN pin or to the LED anode pin? As we learned in the previous part, it does not matter, both will interrupt the light!. We will apply it to the NPN because that is what we will use in the Fe cube. The circuit is given in Fig.~\ref{f:lesson1_twopin_PWM}. If you compare with Fig.~\ref{f:lesson1_twopin}, you see the circuit is the same. To find out how to use PWM (\ardo{analogWrite}), see the code below.

In this code we do one more trick. We use a random number to decide how bright the LED should be, and change this brightness every second. For this we introduce 2 new concepts:
\newline
 \textbullet\ \ardo{randomSeed(analogRead(0));} A random number is only really fully random if we cannot guess where it starts. For this we need to ``seed'' the random number generator. We do this here by reading the value on the not used analog pin 0. As analog pin is connected to nothing, there will be random noise which we cannot guess, allowing us to set our random seed to an unknown beginning. Like this we are sure the sequence of brightness we see is every time different when we switch on the Arduino.
\newline
  \textbullet\ \ardo{random} This function of Arduino returns a random number; \ardo{random(256)} returns a random number between 0 and 255, see {\url{http://Arduino.cc/en/Reference/random}}.
}

\ned{De volgende vraag is op welke pin we de \ardo{analogWrite} moeten toepassen. Zoals we geleerd hebben in het vorige stuk: het doet er niet toe, beide pin 2 en pin 11 zullen de LED onderbreken. Wij zullen het toepassen op de NPN pin, gezien dat degene is die we bij de Fe cube zullen gebruiken. Het circuit is gegeven in Fig.~\ref{f:lesson1_twopin_PWM}. Als je vergelijkt met Fig.~\ref{f:lesson1_twopin}, zie je dat het circuit hetzelfde is. Zie dan de code hieronder om te zien hoe PWM gebruikt wordt .

Merk op dat we in de code enkele nieuwe trucks gebruiken. We gebruiken een willekeurig (=random) getal om te bepalen hoe helder de LED moet zijn, en we wijzigen de helderheid elke seconde. Hiertoe hebben we 2 nieuwe begrippen nodig:
\newline
 \textbullet\ \ardo{randomSeed(analogRead(0))}. Een random getal is enkel volledige willekeurig indien we niet kunnen raden waar het start. Hiertoe moeten we de random getallen generator zaai\-en (seed in het Engels) met een begingetal. We doen dit hier door het lezen van de waarde op de niet gebruikte analoge pin 0. Gezien deze analoge pin bij ons met niets geconnecteerd is, zal er enkel willekeurige storing erop zitten, welke we niet vooraf kunnen raden. Dit zal ons ongekend begin zijn, zodat we zeker zijn dat de serie helderheid die we zien telkens anders is als we de Arduino heropstarten.
\newline
 \textbullet\ \ardo{random}. Deze Arduino functie genereert een willekeurig getal. Door te schrijven  \ardo{ramdom(256)} bekomen we een willekeurig getal tussen 0 en 255, zie \url{http://Arduino.cc/en/Reference/random}.
\
}

\begin{code}\label{c:l1_c}
 \ \newline
\inputardfull{\string"../../sketches/old_versions/v01/Fe_cube_01_led_npn_pwm/Fe_cube_01_led_npn_pwm.ino\string"}
\end{code}

\subsection{\engt{Turn it around!} \nedt{Draai het om! Hoe een digitale pin gebruiken als grond.}}
\eng{We have used a digital pin for the plus, and the ground for the minus. In fact the pin was on 5 Volt above the ground, so we can interpret is as the ground being 0 Volt. You might think that this means pins are always positive, but that is not true. Pins can be sinks (provide negative current) or sources (provide positive current), depending on their place in the circuit. It is however important to keep in mind they can only carry a limited amount of current: 40 mA (milliamps) can be delivered to other devices/circuits. This is enough current to brightly light up a LED (don't forget the series resistor), or run many sensors, but not enough current to run most relays, solenoids, or motors. Drawing more current through a pin will destroy the pin, and possibly even the entire Arduino board! So be careful in how to use them. 

If you need more current, use provided voltages on the board. You see a 3.3V (max 50 mA power draw) and a 5V (draw depending on how the Arduino is powered, USB or battery) pin. Test this. Make the circuit, and load the code from Code \ref{c:l1_b}. Instead of connecting the positive side to pin 1, connect it to 3.3V, and then to 5V. You will see the LED works without problems, however, you can no longer interrupt the LED by sending signals to pin 1.

The lesson to remember is that for big projects you should use the voltage pins on the Arduino: 3.3V, 5V and GND to deliver the current, while you use the numbered pins for small things: a sensor, a LED, or an NPN gate to block current. 

To experiment with the possibilities, let's completely reverse the example, and remove the ground from the circuit, using a digital pin to provide the ground. Your circuit should look like the left one in Fig~\ref{f:lesson1_twopin_PWM_reversed}. The important change is that we must set the pin 1 on 0V. This is done with a 
\ardo{digitalWrite(1, LOW);}. That is the only change in the code, but the circuit has been completely reversed.

As this is a LED, we use less than 40mA of current, so we can remove also the input voltage and only use pins, as in the right part of Fig~\ref{f:lesson1_twopin_PWM_reversed}.

It should be clear we can use the digital pins in different ways. Nevertheless, be well aware of the limitation to only draw 40mA from a digital pin! If you need more, use the voltage pins and the GND pin.
}

\ned{We hebben een digitale pin gebruikt voor de plus, en de grond voor de min. In realiteit was de pin op 5 Volt boven de grond. De grond kunnen we dus interpreteren als 0 Volt. Je zou kunnen denken dat dit betekent dat de pinnen altijd positief moeten zijn, maar dat is niet waar. Een pin kan zowel positieve stroom leveren als negatieve stroom, afhankelijk van de plaats in het circuit. Het is evenwel belangrijk om er rekening mee te houden dat een digitale pin maar een beperkte hoeveelheid stroom kan leveren: 40 mA (milliamps) is beschikbaar voor gebruik in het circuit. Dit is genoeg stroom om een LED helder te doen oplichten (vergeet evenwel geen weerstand in serie te plaatsen), of om verschillende sensoren aan te drijven, maar niet genoeg om een relay of motor aan te drijven. Meer stroom trekken uit een digitale pin zal de pin kapot maken, en misschien wel je volledige Arduino bord! Wees dus voorzichtig in hoe je ze gebruikt.

Als je meer stroom nodig hebt, gebruik de beschikbare volt pinnen op het bord. Je ziet een 3.3V (tot 50mA stroom beschikbaar) en 5V pin (stroom afhankelijk van hoe je Arduino stroom krijgt, via USB of batterij). \\
{\textbf{Test dit.}} 
\begin{enumerate}
 \item Maak het circuit en laad de code van Code \ref{c:l1_b}. In plaats van de positieve zijde te verbinden met pin 2, connecteer ze met 3.3V en dan met 5V. Je zal zien dat de LED zonder probleem werkt, maar je kan natuurlijk niet langer de LED afzetten door signalen te sturen naar pin 2.

Wat je moet onthouden is dat je voor grote projecten de voltage pinnen op de Arduino moet gebruiken om stroom te leveren: 3.3V, 5V en GND; terwijl je de genummerde pinnen gebruikt voor kleine dingen: een sensor, een LED, of een NPN transistor om stroom te onderbreken.
\item Om te experimenteren met de mogelijkheden, laat ons het vorige voorbeeld helemaal omdraaien, en de grond verwijderen uit het circuit door een digitale pin te gebruiken als grond. Jou circuit zou eruit moeten zien als de linkse uit Fig~\ref{f:lesson1_twopin_PWM_reversed}. Belangrijk hier is dat we pin 2 moeten plaatsen op 0V. Dit doen we met
\ardo{digitalWrite(2, LOW);}.  Dat is de enige wijziging in de code, maar het circuit is wel omgedraaid!
\item Gezien dit een LED is gebruiken we minder dan 40mA stroom, en kunnen we dus ook het input voltage vervangen door een pin, zoals gedaan in de rechterfiguur van Fig~\ref{f:lesson1_twopin_PWM_reversed}.
\end{enumerate}

Het zou duidelijk moeten zijn dat we de digitale pinnen op verschillende manieren kunnen gebruiken. Wees je evenwel goed bewust van de limitatie van de pinnen: je kan enkel 40mA uit een digitale pin krijgen. Als je meer nodig hebt, gebruik de voltage pinnen en de GND pin.
}

\begin{figure}
  \centering
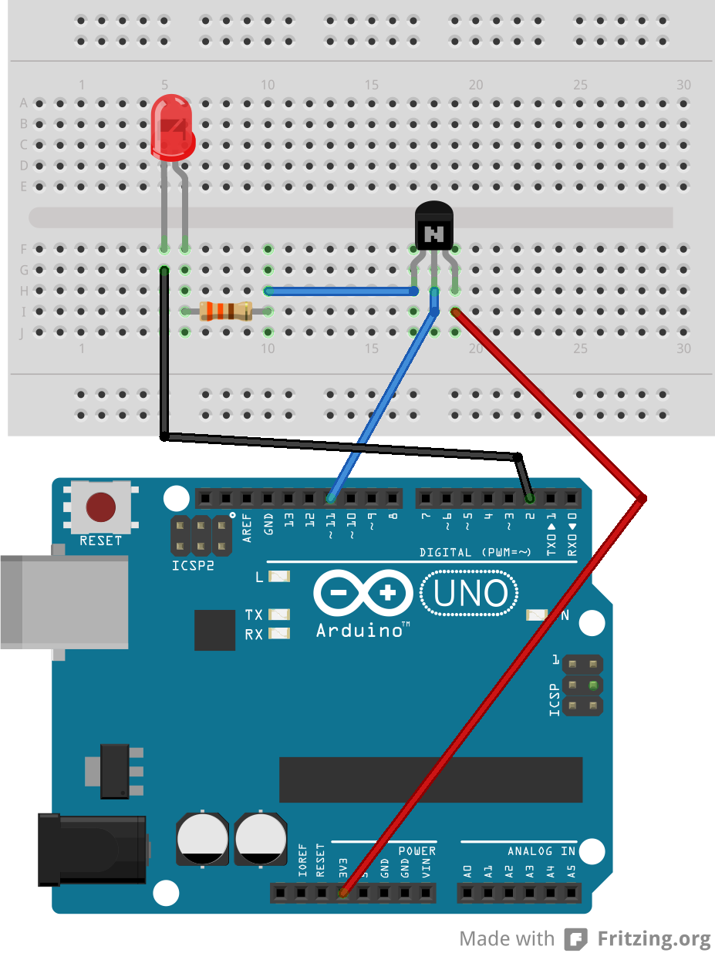
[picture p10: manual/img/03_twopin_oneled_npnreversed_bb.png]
  
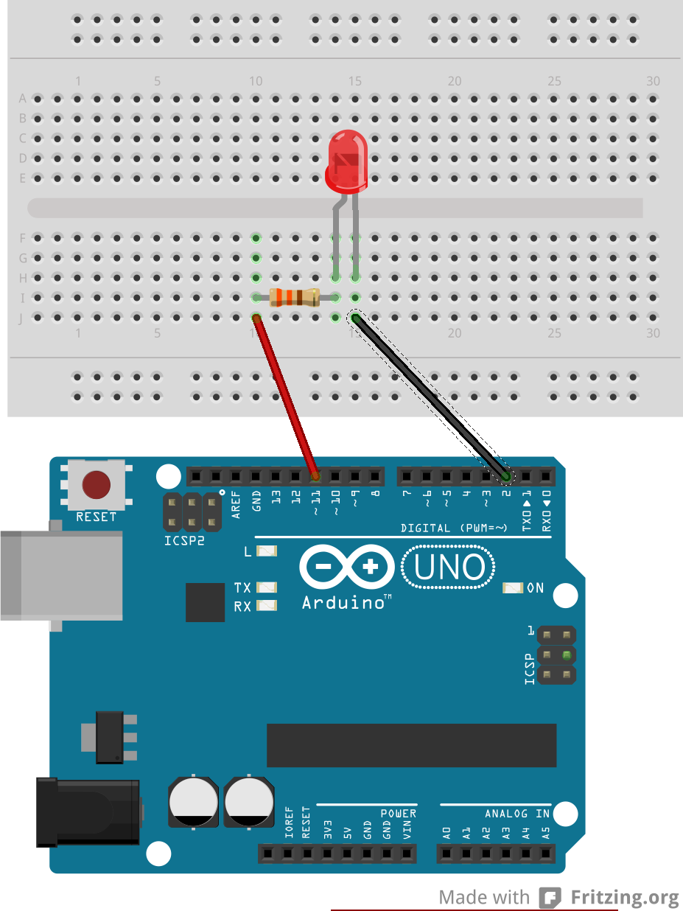
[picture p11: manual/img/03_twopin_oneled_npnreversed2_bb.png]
  
\caption{\engt{Using two pins and an NPN gate, we can switch off the LED on both sides. Now we use pin 2 to allow a sink at the pin. Right: Removing the NPN makes for a simpler circuit}
\nedt{Met twee pinnen en een NPN brug kunnen we de LED afzetten aan beide kanten. We gebruiken nu pin 2 zodat we de pin als grond kunnen gebruiken. Rechts: De NPN verwijderen zorgt voor een eenvoudiger circuit.}}
\label{f:lesson1_twopin_PWM_reversed}
\end{figure}

\eng{Note following thing in the code: As pin 2 needs to act as ground, we need to do \ardo{digitalWrite(LOW)} on this pin. }
\ned{Merk het volgende op in Code \ref{c:l1_d}: gezien pin 2 zich als grond moet gedragen dienen we \ardo{digitalWrite(2, LOW)} op de pin uitvoeren.}

\begin{code}\label{c:l1_d}
 \ \newline
\inputardfull{\string"../../sketches/old_versions/v01/Fe_cube_01_led_npn_pwm_reverse/Fe_cube_01_led_npn_pwm_reverse.ino\string"}
\end{code}

\section{\engt{Lesson 2: A RGB LED Circuit} \nedt{Les 2: Een RGB LED circuit}}

\subsection{\engt{The RGB circuit} \nedt{Het RGB circuit}}
\begin{figure}[ht]
  \centering
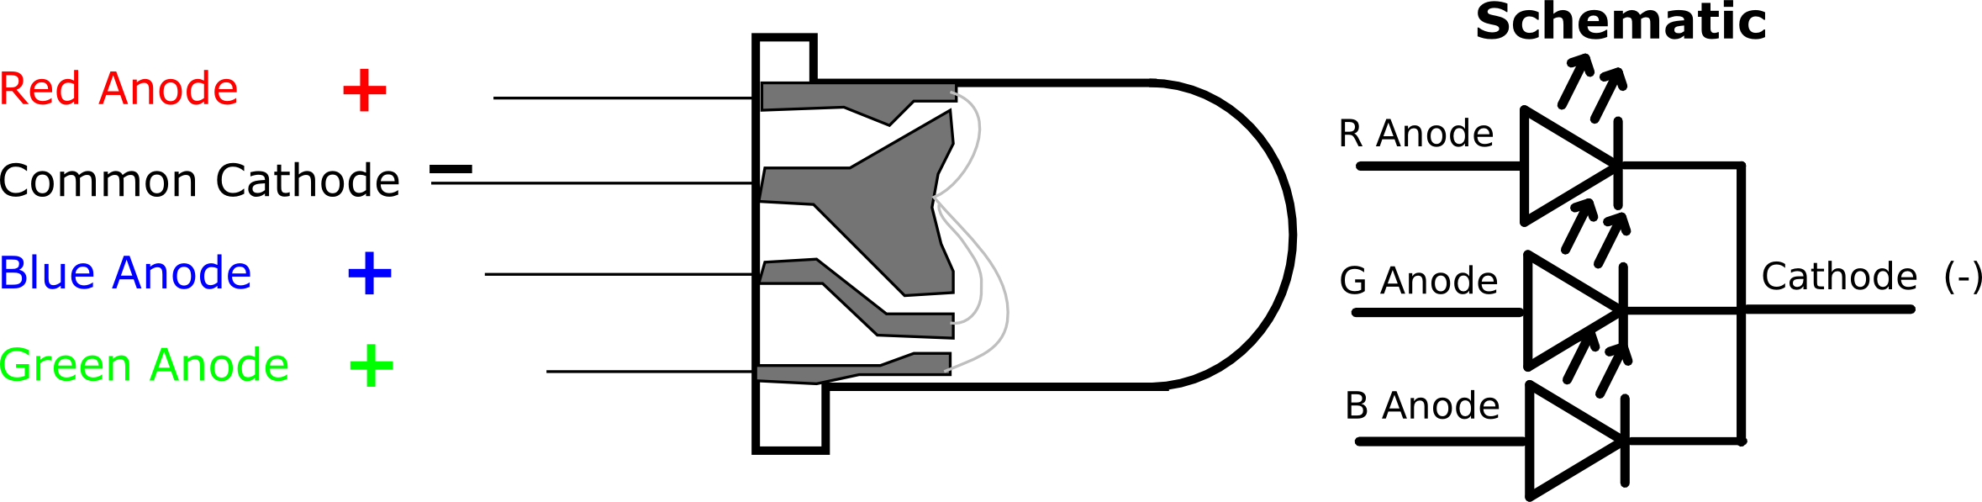
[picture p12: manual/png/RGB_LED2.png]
  
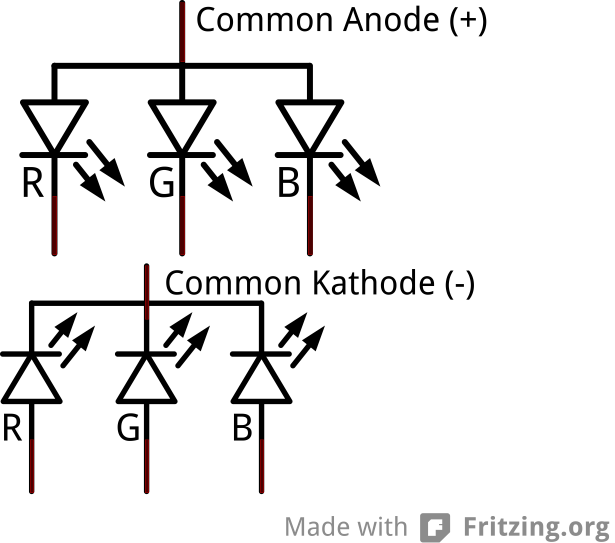
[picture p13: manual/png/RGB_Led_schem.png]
   
\caption{\engt{Left an exploded view of an RGB LED with common anode, Right a schematic version used in circuits} \nedt{Links een vergroting van een RGB LED met gedeelde anode, Rechts een schema zoals je in circuits kan vinden.}}
\label{f:RGB_LED}
\end{figure}

\eng{LED exist in different colors. Some LEDs can produce a color range. These are RGB LEDs, see a depiction in Fig.~\ref{f:RGB_LED}. They are essentially a red, green and blue LED rolled in a single package, and with a common anode or a common cathode. To drive this LED, we extend the single LED circuit with NPN. We assume you have an RGB LED with 3 cathodes and one anode, so we need 3 NPN gates, but only one resistor. 

\textbf{Note:} If you use a LED with a common cathode, you will need to reverse the circuit as given in the previous lesson. See the cube later on where this is the case.
}

\ned{LED bestaan in verschillende kleuren. Sommige LED kunnen een kleurenbereik produceren. Dit zijn RGB LEDs, zie een afbeelding in Fig.~\ref{f:RGB_LED}. Ze zijn in essentie een rode, groene en blauwe LED in een enkel pakket, met een gedeelde anode of een gedeelde ka\-thode. Om deze LED aan te drijven breiden we ons 1 LED met NPN circuit (Code 2) uit. We veronderstellen dat je een RGB LED hebt met 3 kathoden en 1 anode, dus zullen we 3 NPN bruggen nodig hebben, en 1 resistor. 

{\textbf{Merk Op:}} Indien je een LED gebruikt met een gedeelde kathode dien je het circuit te inverteren zoals gezien in de vorige les. Zie ook de kubus later waar dit het geval is.
}

\engo{\begin{doE}
      \textbf{Test your RGB LED}. So, there are 4 legs to the RGB LED. The longest one is or the common cathode (-, connect to GND) or the common anode (+, connect to a voltage). You will need to test your LED to know which is the case, and you will need to test what leg is which color. Do this now: put the RGB LED on your breadboard, connect a 330$\Omega$ resistor from the row with the longest leg to another row on the breadboard. Now take two wires, and plug one in the GND, and the other in the 3.3V output. Your Arduino should be powered, so connect it via \textsc{usb} to your PC. Assume first it is a common cathode LED, so connect the GND to the resistor. With the 3.3V wire, test the legs of the LED. Not working? Remove the wires from the breadboard and test if it is a common anode LED. So connect 3.3V wire now to the resitor, and test the other legs with the GND wire.
      
      Tip: Make a scetch of your LED, writing down what is Red, Green, Blue and the cathode/anode!
     \end{doE}
}
\nedo{\begin{doN}
      \textbf{Test je RGB LED}. Er zijn dus 4 beentjes aan de RGB LED. Het langste been is normaal de gemeenschappelijke kathode (-, verbindt met GND) of de gemeenschappelijke anode (+, verbindt met een voltage). Je zal je LED moeten testen om te weten wat wat is. Doe dit nu: plaats de RGB LED op je breadboard, connecteer een 330$\Omega$ weerstand van de rij met het langste been naar een andere vrije rij op je bord. Neem nu twee draden, en plaats een in de GND, en de andere in de 3.3V output. Je Arduino zet je aan, verbindt dus de \textsc{usb} kabel met je PC. Onderstel eerst dat het een gemeenschappelijke kathode LED is, dus verbindt de GND draad met de weerstand. Met de 3.3V draad test je de beentjes van de LED. Het werkt niet? Verwijder de draden van het schakelbord en test of het een gemeenschappelijke anode LED is. Dus, verbindt de 3.3V draad met de weerstand, en test de andere LED beentjes met de GND draad.
      
      Tip: Maak een schets op papier van je LED, waarbij je noteert welk been Rood, Groen en Blauw is, alsook de kathode/anode.
     \end{doN}
}

\begin{figure}
  \centering
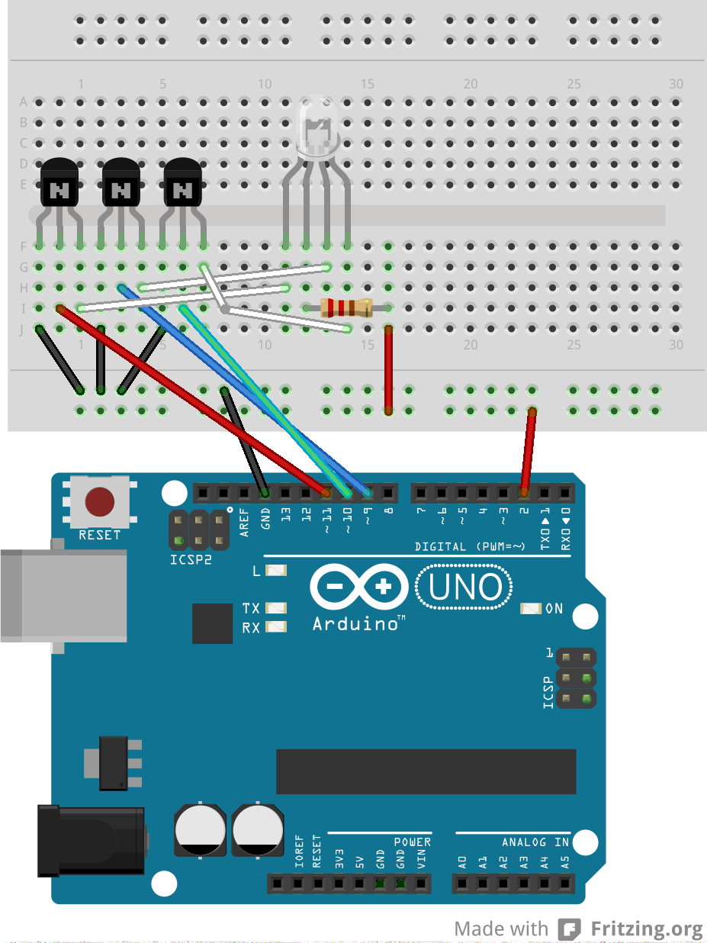
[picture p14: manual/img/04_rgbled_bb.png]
   \ \ 
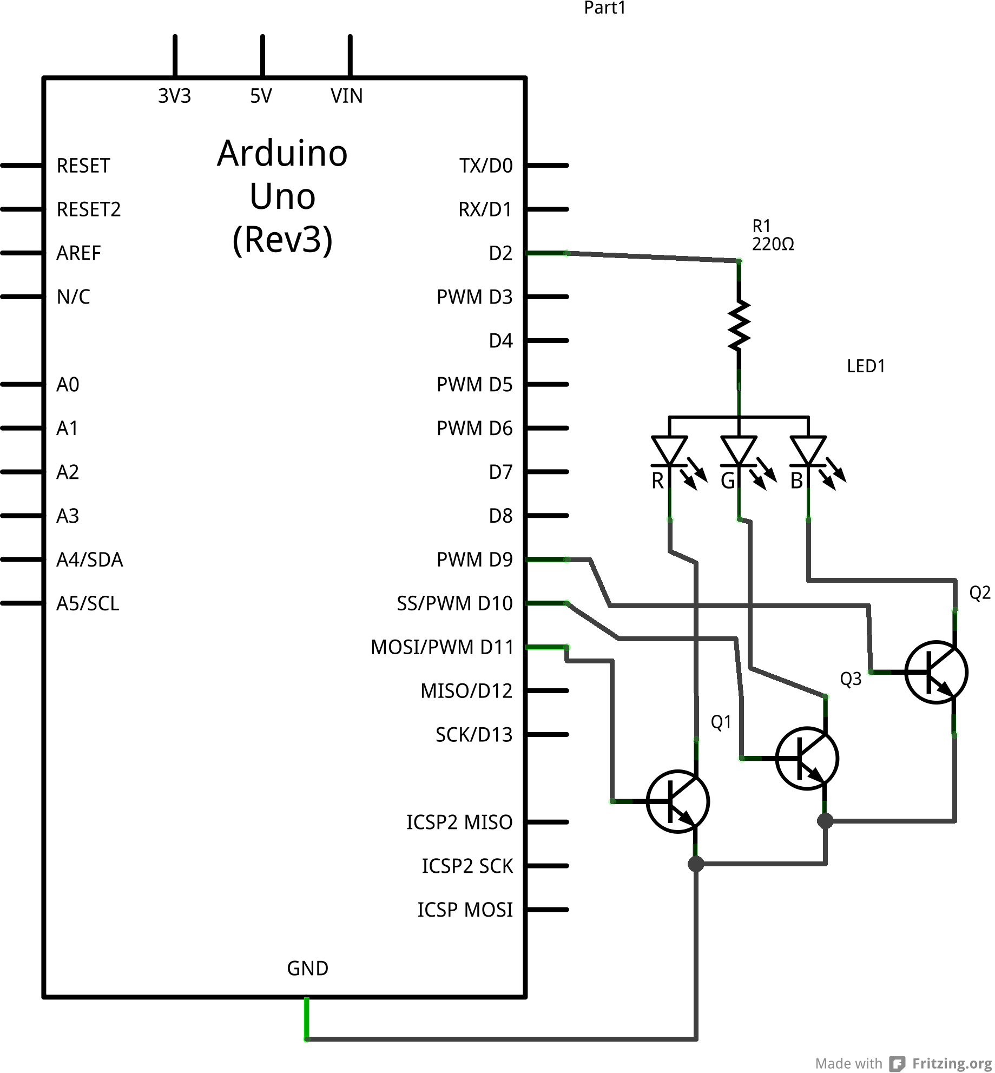
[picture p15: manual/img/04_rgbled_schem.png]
  
\caption{\engt{Circuit for a common anode RGB LED} \nedt{Circuit voor een gedeelde anode RGB LED.}}
\label{f:lesson2_RGB}
\end{figure}

\eng{The circuit is given in Fig.~\ref{f:lesson2_RGB}. Some things to note: all the NPN outputs (E) are connected to the ground, so connect them to a single row on your breadboard. For the other connections, different wires are needed: 4 control pins and the ground, so 5 wires. 

Once you have the circuit made, the rest of the lesson will be programming the LED. Start with a simple program to have the LED cycle through Red, Green and Blue. When finished, make sure this is indeed the order, if not, you made an error wiring the cathodes. If you power two cathodes at the same time, you will obtain sometimes a nice mixed color, and sometimes not. This is because the resistance for one color is not equal to another, so the current can have a preferential path. So, cheap RGB LED are not good to combine colors by powering two or more cathodes at the same time. We will need to use tricks to nicely mix colors. That is for the next section, for this section our first Arduino sketch was:}

\ned{Het circuit is gegeven in Fig.~\ref{f:lesson2_RGB}. Enkele dingen om rekening mee te houden: De NPN uit (E) gaan allemaal naar de grond (GND), plaats ze dus op een enkele rij op je schakelbord. Voor de andere connecties heb je verschillende draden nodig: 4 controle pinnen en de grond, dus 5 draden.

Eenmaal je circuit gemaakt is, is het vervolg van deze les het programmeren van de LED. Start met een simpel programma om de LED te laten lopen door Rood, Groen en Blauw. Als je klaar bent, verifieer dat je inderdaad deze orde ziet, indien niet heb je een fout gemaakt met het bedraden van de kathoden. Als je twee kathoden terzelfdertijd onder stroom plaats, zul je soms een mooie gemengde kleur krijgen, en soms niet. Dit is omdat de weerstand via een kleur niet identiek is aan die van een andere kleur, waardoor de stroom via een preferentieel pad zal lopen. Goedkope RGB LED zijn niet zo goed om kleuren correct te mengen door twee of meer kathoden terzelfdertijd aan te sturen. We zullen later enkele trukjes moeten gebruiken om kleuren mooi te mengen. Hier onze Arduino sketch voor RGB:}

\begin{code}\label{c:l2_a}
 \ \newline
\inputardfull{\string"../../sketches/old_versions/v01/Fe_cube_02_RGB_npn/Fe_cube_02_RGB_npn.ino\string"}
\end{code}

\subsection{\engt{Mixing colors} \nedt{Kleuren mengen}}
\eng{In Code \ref{c:l1_c} we have shown how a LED light can be dimmed. We are going to use this now to mix colors. If we succeed in showing first red, then green, and then blue, with the colors correctly dimmed, we can mix colors. For example, if we turn off blue, we will obtain red+green=yellow. The trick will again be to do this all so fast that due to persistence of vision we trick the eye into seeing a non-blinking mixed color.

So, create an Arduino sketch to show a random mixed color for a second, then switch to a next random color. To dim a color we use \ardo{analogWrite}. We have seen that \ardo{analogWrite} creates a block wave, and that we can create 256 different block waves. The number 256 is not arbitrary. We have that 256=2*2*2*2*2*2*2*2, so 2 is multipled 8 times with itself. This is the largest number you can create with a single byte in the Arduino memory. The so called 8 bit byte is the unit used in the first computers to store information. 

Fortunately, 256 is also the range used in analogWrite, as the original computer \href{http://en.wikipedia.org/wiki/RGB_color_model\#Numeric_representations}{RGB color model} is based on this number. The colors we will make with our multicolor LED should hence corresponds to those of the RGB color model, see Fig.~\ref{f:RGB_color}. 
}

\ned{In Code \ref{c:l1_c} hebben we getoond hoe we een LED licht kunnen dimmen. We gebruiken dit nu om kleuren te mengen. Als we erin slagen om eerst rood, dan groen, en dan blauw te tonen, met de kleuren correct gedimd, dan kunnen we kleuren mengen. Bevoorbeeld, als we blauw afzetten zullen we rood+groen=geel krijgen. De truck om dit te doen werken zal weer zijn dat we dit allemaal zo snel moeten doen dat door persistentie van visie we ons ook kunnen doen geloven dat we op een niet pinkende manier kleuren mengen

Maak dus een Arduino sketch om een willekeurige gemengde kleur te tonen voor een enkele seconde, om daarna een andere willekeurige kleur te tonen. Om een kleur te dimmen gebruiken we weer \ardo{analogWrite.} We hebben gezien dat \ardo{analogWrite} een blokgolf maakt en dat we 256 verschillende blokgolven kunnen verkrijgen, van 0 tot 255. Het nummer 256 komt niet zomaar uit de lucht vallen. We hebben dat 256==2*2*2*2*2*2*2*2, het is dus 2 die 8 keer met zichzelf vermenigvuldigd wordt. Dat is het grootste nummer die je kunt maken met een enkele byte (=8 bits) van het Arduino geheugen. De zo genaamde 8 bit byte is de eenheid gebruikt in de allereerste computers om informatie mee op te slaan.

Het is erg handig dat 256 het verloop is dat gebruikt wordt in \ardo{analogWrite}, gezien het originele \href{http://en.wikipedia.org/wiki/RGB_color_model\#Numeric_representations}{RGB kleurenmodel} gebasseerd is op dit getal. De kleuren die wij zullen maken met onze RGB LED zullen dus overeenkomen met die van het RGB kleurenmodel, zie Fig.~\ref{f:RGB_color}. 
}

\begin{figure}
  \centering
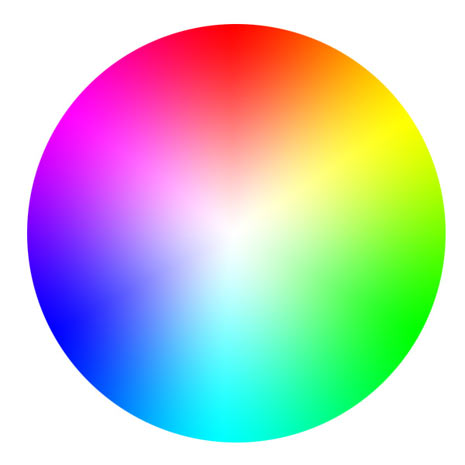
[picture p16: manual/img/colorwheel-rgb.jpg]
  
\caption{\engt{Part of the RGB colors possible} \nedt{Een deel van de mogelijke kleuren met RGB LEDs}}
\label{f:RGB_color}
\end{figure}

\eng{The actual code is given in Code \ref{c:l2_b}. Several new concepts are present.
\newline 
\textbullet\ \ardo{Serial.begin} and debugging: \ardo{Serial} allows to inspect your Arduino from your PC. It opens a slow connection to which you can print. We do this with a flag: \ardo{bool test} is a variable we call a flag: it can have two values: true or false. If the variable is true, we print on the serial connection the values of the randomly determined Red, Green and Blue value.  We do this with the command \ardo{Serial.print}. To make sure the next value of RGB is printed on a new line, we finish with \ardo{Serial.println}
\newline
\textbullet\ \ardo{millis()}: this is a function that returns the number of milliseconds since the Arduino was switched on. You can find functions in the \href{http://Arduino.cc/en/Reference/millis}{Reference guide}. The maximum amount will correspond to 50 days. After that it restarts from 0.
\newline
\textbullet\ An \ardo{if} test. This is a condition, if the part after the \ardo{if} in normal brackets is true, we will execute the part following in curly brackets, otherwise not. The syntax is:\newline
 \ardo{if (condition)\{ ... commands ...\}}
\newline
so 'commands' are only executed if the condition is true.
\newline 
\textbullet\ A \ardo{while} loop: This is a repetition based on a condition. As long as the condition in normal brackets is true the piece following in curly brackets will be executed. The syntax is:\newline
 \ardo{while (condition)\{ ... commands ...\}}
\newline
so 'commands' will be executed as long as condition is true. Be careful here, it's easy to create while loops that never end. It's important that the condition is something that is updated regularly. In our code, the condition is:\newline
\ardo{currentTime - prevTime < 1000} \newline
so as soon as this is 1000 milliseconds the loop will stop. This will happen because in the curly brackets with the commands you see as last command:\newline
\ardo{currentTime = millis();}
\newline
so the variable currentTime is ever increasing, and the while loop will indeed stop. 
}

\ned{De gebruikte code vind je in Code \ref{c:l2_b}. Verschillende nieuwe concepten zijn aanwezig.
\newline 
\textbullet\ \ardo{Serial.begin} and \ardo{print}: \ardo{Serial} laat toe om je Arduino te observeren vanuit je PC. Het opent een trage connectie naar waar je prints kunt sturen. In de sketch doen we dat via een vlag: \ardo{bool test}, dit is een variabele die we een vlag noemen: het kan twee waarden hebben: waar of vals, welke in het Engels zijn \textit{true} of \textit{false}. Als de variabele true is, dan printen we op de seri\"ele connectie de waarden van de willekeurig bepaalde Rood, Groen, en Blauw. We doen dit met het commando \ardo{Serial.print}. Om ervoor te zorgen dat de volgende waarde van RGB op een nieuwe lijn komt, eindigen we met \ardo{Serial.println}, die laaste \textit{ln} staat voor 'lijn'
\newline
\textbullet\ \ardo{millis()}: Dit is een fuctie die het aantal milliseconden sinds de opstart van de Arduino teruggeeft. Je kan functies opzoeken in de \href{http://Arduino.cc/en/Reference/millis}{Reference guide}. Het maximum getal die je kunt terugkrijgen komt overeen met 50 dagen. Daarna herstart het van 0.
\newline
\textbullet\ Een \ardo{if} test. Dit is een conditie. Als het stuk achter de \ardo{if} in normale haakjes waar (true) is, dan wordt het stuk in gekrulde haakjes uitgevoerd, anders niet. De syntax is:\newline
 \ardo{if (conditie)\{ ... commando's ...\}}
\newline
dus 'commando's' worden enkel uitgevoerd als conditie waar is.
\newline 
\textbullet\ Een \ardo{while} lus: Dit is een repetitie gebaseerd op een conditie. Zolang de conditie waar is zal het stuk in de gekrulde haakjes uitgevoerd worden. De syntax is:\newline
 \ardo{while (conditie)\{ ... commando's ...\}}
\newline
dus 'commando's' zullen uitgevoerd worden zolang conditie waar is. Opgelet hier, het is gemakkelijk om een while loop te maken die nooit stopt. Het is belangrijk dat de conditie iets is dat regelmatig aangepast wordt. In onze code is de conditie:\newline
\ardo{currentTime - prevTime < 1000} \newline
dus zolang de huidige tijd (\textit{currentTime}) min the vorige tijd (\textit{prevTime}) minder dan een seconde is, herhalen we de commando's. Er zal een moment komen waarop de conditie vals is en de lus stopt. Dit omdat je als laatste lijn in de gekrulde haken van de while ziet:\newline
\ardo{currentTime = millis();}
\newline
dus de variabele currentTime neemt constant toe, en de while loop zal inderdaad stoppen. 
}

\begin{code}\label{c:l2_b}
 \ \newline
\inputardfull{\string"../../sketches/old_versions/v01/Fe_cube_02_RGB_npn_random_color_PWM/Fe_cube_02_RGB_npn_random_color_PWM.ino\string"}
\end{code}

\eng{
The LED should burn nicely, switching colors every second. However, if you play around with the \ardo{delayDuration} variable, you should quickly see that for several values the LED starts to flicker, which is highly annoying.

So, to test the colors are a little bit accurate, do the following:
\begin{enumerate}
 \item change the time of a single color to 60 seconds, so 60000 milliseconds
 \item verify you have in the sketch: \ardo{bool test=true;}
 \item upload the sketch, a color will now last one minute
 \item Open the serial monitor, this is the icon with the lens in the top
right of the Arduino Editor. Every minute you will see the color values that are shown on the LED.
 \item To see if this is somewhat correct, use a color picker tool. For example \href{http://www.colorpicker.com/}{www.colorpicker.com} has fields for R, G and B to see what color corresponds with those values.
 \item Don't expect too much accuracy in these colors! First, if you don't use a dark room, the LED will always have color, so blacks are not possible. If you do use a black room, the red, green and blue are generated in different regions of the LED, so when they all burn, the mixing is not perfect. Next, the pure red, green and blue do not exactly match those of the RGB color model, so mixing is different. Lastly, the LED produces little light, the LED actually contains or lens to focus the light in only one direction, or a dimmed packaging to diffuse the light in all directions. In both cases this creates artifacts.
\end{enumerate}
}

\ned{De LED zou moeten mooi branden, en van kleur wisselen elke seconde. Als je speelt met de variabele \ardo{delayDuration}, zul je evenwel opmerken dat de LED gemakkelijk begint te flikkeren als je niet vlug kleur wisselt.

Om te testen hoe accuraat de kleuren zijn, doe het volgende:
\begin{enumerate}
 \item wijzig de tijd van een enkele kleur in 60 seconden, dus 60000 milliseconden
 \item verifieer dat je hebt in je sketch: \ardo{bool test=true;}
 \item upload de sketch, een kleur zal nu een minuut duren
 \item Open de seri\"ele monitor, dit is het icoon met het vergrootglas in de rechterbovenhoek van de Arduino Editor. Een nieuw venster gaat open. Elke minuut zul je de kleur waarden zien verschijnen van de kleur die getoond wordt.
 \item Om te zien dat dit plus-minus correct is kun je een kleurenkiezer programma gebruiken. Bijvoorbeeld \href{http://www.colorpicker.com/}{www.colorpicker.com} heeft velden voor  R, G and B die je kunt ingeven om te zien welke kleur ermee overeenkomt.
 \item Verwacht niet teveel accuraatheid in de kleuren! Vooreerst, als je geen donkere kamer gebruikt zal de LED altijd zijn eigen kleur hebben. Zwarte kleuren zijn dan niet mogelijk, gezien donker gewoon afwezigheid van licht is. Verder worden rood, groen en blauw in verschillende regio's van de LED opgewekt waardoor het mixen niet perfect kan zijn. Dan komen ook het pure rood, groen en blauw niet precies overeen met die van het RGB kleurenmodel, dus is mixen wat anders. Als laatste, de LED maakt maar weinig licht. De LED bevat of een lense om het licht te focussen in \'e\'en richting, of een wazige rand om het licht diffuus te verspreiden. In beide gevallen krijg je artefacten bij het mengen.
\end{enumerate}
}

\engo{\begin{doE}
       Reverse the test. Select a color via the color picker. Edit the sketch so as to only show this color!
      \end{doE}
}
\nedo{\begin{doN}
       Draai de test rond. Selecteer een kleur via de kleuren kiezer. Wijzig de sketch zodat je de kleur krijgt die je gekozen hebt.
      \end{doN}
}

\subsection{\engt{Advanced: Mixing colors the hard way} \nedt{Moeilijk: Kleuren mengen op de expliciete manier}}

\eng{For the cube we will have 9 LEDs with 3 colors. If we want to use PWM, we would need 9x3=21 analog pins to give the 9 LEDs each a different color. This is not possible with the Arduino, there are not that many pins! We could make the cube behave as one single lamp showing always the same color. Then we need only 3 pins with PWM. 

Next, by showing one LED after the other, we can then still do all the LEDs in a different color! It would take a long time though between one burn and the next. Suppose we show 0.5 milliseconds a color of one LED with PWM. Then one LED needs 1.5 ms. Then we can do the next LED. So 13 ms are needed before the first LED can start again. In other words, a color is shown 0.5 ms of 13.5 ms or only 5/135=1/27 of the time a color of a LED is shown. It would be best if we can achieve instead 1/3 of the time a color, as that will result in a 9 times brighter image. 
This is the reason we will mix colors the hard way: without PWM.

Before we do that, we need to design a way to show animations, so as to have a robust base for the effects you might want to implement.}

\ned{Voor onze kubus zullen we 9 LEDs hebben met 3 kleuren. Als we PWM willen gebruiken, zouden we 9x3=21 analogen pinnen nodig hebben om de 9 LEDs elk een andere kleur te geven. Dit is niet mogelijk met de Arduino, er zijn niet zoveel pinnen. We zouden in plaats daarvan de kubus kunnen zien als een enkele lamp die altijd dezelfde kleur zal tonen. Dan hebben we maar 3 pinnen met PWM nodig.

Vervolgens, door een LED na de andere aan te schakelen, zouden we toch nog in staat zijn om elke LED een andere kleur te geven! Het zou evenwel lang duren tussen branden voor een LED. Veronderstel dat we 0.5 milliseconden een kleur van een LED tonen via PWM. Een enkele LED heeft dan 1.5 ms nodig voor een kleur. Daarna pas kan de volgende LED. Dus zijn er 13 ms nodig voor de eerste LED opnieuw kan branden. In andere woorden, een kleur wordt 0.5 ms van een cyclus van 13.5 ms getoond, of 5/135=1/27 van de tijd. Het zou beter zijn als we 1/3 van de tijd kunnen gebruiken, gezien onze kubus dan 9 keer helderder zal zijn. Dat is de reden dat we kleuren zullen mengen op een moeilijke manier: zonder PWM.

Voor we hieraan beginnen, moeten we begrijpen hoe we animaties zullen tonen, zodat we een robuuste basis hebben voor de effecten die je wilt tonen.
}

\eng{We consider again our single RGB-LED. What effects can we show with one RGB? Some examples:
\begin{itemize}
 \item Cycle red, green, blue, always faster up to the point we see white
 \item Go from one color to another in smooth gradual way
 \item Do morse code of a sentence.
 \item ....
\end{itemize}
So, how to program this? We will do like in the movies: a specific effect consists of different shots or actions. An action has a certain duration: $t_a$. The action is divided in frames $F$, which is a single image, like a picture taken at a specific instance, see Figure  \ref{f:horse_movie}. So, an action is a function, which for a specific time needs to tell us what frame to show: $F=\mbox{action(t)}$

To trigger persistence of vision, a frame is shown 40 ms, then the next frame is shown. For a single LED, a frame will be a single color to show. To show this color, we need to cycle over the 3 base colors: red, green, blue. Therefore, we will divide a frame $F$ into subframes $S$. A subframe is an image the LED can produce, so a brightness in red, or a brightness in green, or a brightness in blue. So, a frame will be some subframes shown in serial:
$$F=S_B \circ S_G \circ S_R.$$
We need a final trick to make it work. If we would divide a frame in 3 pieces, then a subframe would be $40/3\approx 13.3$ms. That is not optimal, as it can already be perceived as flicker, certainly if only a single base color like red needs to be shown. Instead, we will consider an optimal time to show a subframe. Then, for as long as the frame must be shown, we repeat the cycle of subframe, so: 
$$F=S_B \circ S_G \circ S_R \circ \ldots \circ S_B \circ S_G \circ S_R \circ S_B \circ S_G \circ S_R.$$

What is the best duration of a subframe? For a single LED, a third of a millisecond is not bad. We express this as microseconds ($\mu$s). A $\mu$s is a one thousanth of a millisecond, while a ms is a one thousanth of a second. 
}

\ned{We beschouwen opnieuw onze RGB-LED. Welke effecten kunnen we tonen met \'e\'en enkele RGB? Enkele voorbeelden:
\begin{itemize}
 \item Cycle: rood, groen, blauw altijd sneller tot op het punt dat we wit zien.
 \item Ga van een kleur naar een andere kleur op een mooie gladde manier.
 \item Doe morse code van een zin
 \item ....
\end{itemize}
Dus, hoe zullen we dat programmeren? We zullen doen zoals in de filmen: een specifiek effect bestaat uit verschillende shots of acties. Een actie heeft een zekere duur: $t_a$. De actie verdelen we in frames $F$, welke een enkel beeld zijn, zoals een foto genomen op een specifiek moment, zie Figuur \ref{f:horse_movie}. Een actie is dus een functie, welke voor een specifieke tijd ons dient te vertellen welk frame te tonen: $F=\mbox{actie(t)}$

Om persistentie van beeld te krijgen, tonen we een frame 40 ms, waarna de volgende frame getoond wordt. Voor een enkele LED zal een frame een specifieke kleur zijn. Om deze kleur te tonen, dienen we te itereren over de 3 basiskleuren: rood, groen, blauw. Bijgevolg zullen we een frame $F$ onderverdelen in subframes $S$. Een subframe is een beeld die onze LED echt kan maken, dus een helderheid in rood, een helderheid in groen, of een helderheid in blauw. Dus, een frame is dan een aantal subframes die we in serie tonen:
$$F=S_B \circ S_G \circ S_R.$$
We hebben nog een laatste truck nodig. Als we een frame in 3 ge\-lij\-ke subframes zouden delen , dan duren die elk $40/3\approx 13.3$ms. Dat is niet optimaal, gezien het vlug kan overkomen als geflikker, zeker als we maar een enkele basis kleur, bv rood, moeten tonen. Daarom zullen we een optimale tijd opnemen om een subframe te tonen. Dan, voor zo lang als een frame moet getoond worden, herhalen we de cyclus van subframes, we krijgen dus:
$$F=S_B \circ S_G \circ S_R \circ \ldots \circ S_B \circ S_G \circ S_R \circ S_B \circ S_G \circ S_R.$$

Wat is de beste duur van een subframe? Voor een enkele LED zal een derde van een ms niet slecht zijn. We drukken dit uit in microseconden ($\mu$s). A $\mu$s is een duizendste van een milliseconde, terwijl een ms een duizendste van een seconde is.
}

\begin{figure}
  \centering
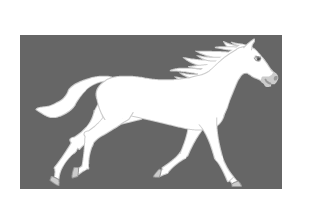
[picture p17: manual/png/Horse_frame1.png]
  
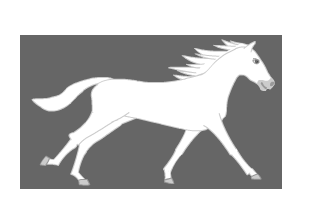
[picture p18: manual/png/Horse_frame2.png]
  
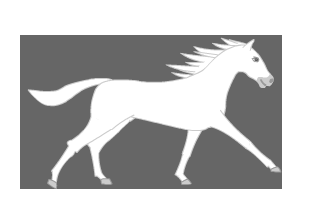
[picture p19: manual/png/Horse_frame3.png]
  
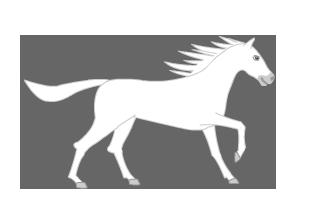
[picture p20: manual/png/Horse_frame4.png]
  
\caption{\engt{4 frames to make a moving horse. The full animation: \href{http://en.wikipedia.org/wiki/File:Horse\_gif.gif}{Wikipedia Horse\_gif}} \nedt{4 frames om een bewegend paard te maken. De volledige animatie: \href{http://en.wikipedia.org/wiki/File:Horse\_gif.gif}{Wikipedia Horse\_gif}}}
\label{f:horse_movie}
\end{figure}

\eng{Let's put our idea in practice for the same effect we did with PWM: show a random color for a single second. As our LED cannot show as many colors as the full RGB range, we will limit the range from 256 gradations to 256/4=64 gradations. We express the scene in the Red, Green, Blue component in 64 gradations, and a duration to show a color:\newline
\textbf{scene = (red base 64, green base 64, blue base 64, duration)}.\newline
The action of this scene is to show a single red, green, blue color, so 
every frame is identical:
$$F= (\mbox{red, green, blue})$$
A subframe consists in showing this red, green or blue. Let's take red. If we show red, we will have a number from 0 to 64 to show. Let's call the number $R$, for example $R=35$. We said a subframe should be around 333$\mu$s. Let's take 64*5 = 320 $\mu$s. 

If the value of red is 64, we show red for 320$\mu$s, if the value is 0 we show red  0 $\mu$s in this subframe. So, for $R=35$, we show it 35*5=175$\mu$s.

The code to implement this is in Code \ref{c:l2_c}.
}

\ned{Laat ons dit in de praktijk brengen met hetzelfde effect dat we eerder via PWM deden: toon een willekeurige kleur voor een seconde. Gezien de LED niet evenveel kleuren kan tonen als het volledige RGB spectrum, limiteren we de 256 gradaties in 256/4=64 gradaties. We drukken de scene uit in de Rood, Groen en Blauw component in 64 gradaties, en een duur om de kleur te tonen:\newline
\textbf{scene = (red base 64, green base 64, blue base 64, duration)}.\newline
De actie van deze scene is het tonen van een enkele rood, groen, blauw kleur, dus elke frame is identiek:
$$F= (\mbox{rood, groen, blauw}).$$
Een subframe bestaat in het tonen van rood, groen, of blauw. Laat ons rood nemen. We zullen een number van 0 tot 64 hebben voor rood. Laat ons dit nummer $R$ noemen, bevoorbeeld $R=35$. We hebben reeds gezegd dat de duur van het subframe rond de 333$\mu$s moet zijn. Laat ons 64*5=320 nemen als duur van het subframe. 

Als de waarde van rood 64 is, tonen we rood voor 320$\mu$s, als de waarde 0 is tonen we rood 0$\mu$s in dit subframe. Dus, voor $R=35$, tonen we het 35*5=175$\mu$s.

The code om dit te implementeren is in Code \ref{c:l2_c}.
}

\begin{code}\label{c:l2_c}
 \ \newline
\inputardfull{\string"../../sketches/old_versions/v01/Fe_cube_02_RGB_frames/Fe_cube_02_RGB_frames.ino\string"}
\end{code}

\eng{The code seems quite complex, but is actually divided in two parts: shots or actions you create, and a generic part that decides when a new frame is needed, requests the new frame from the shot, and then starts up subframe cycles to show this specific frame for 40 ms. This last part will remain the same, if you feel up to it, you can try to understand it, but if not, no problem, it suffices to be able to write new shots.

So, let's go over the code. As always, we define first the pins we will use. Then the \ardo{setup()} function comes, that prepares the Arduino. Nothing new there. 

Next, we have a function for our shot: a random color. This function has a specific signature that all our shots need to have:\newline
\textbf{ void random\_color(unsigned long framenr, int frame{$\lbrack$}3{$\rbrack$})}.\newline
So, a shot returns nothing. That is indicated with \ardo{void}. It needs two parameters:
the framenr of the shot, and a list of 3 integers: {int frame{$\lbrack$}3{$\rbrack$}}. The function will fill up this list with the frame to show. That is it! As our colors are values from 0 to 64, we use \ardo{random(65)}. To test you can indeed show all colors, instead of using random, change the code to see red, green, or blue. 

The following function defines our movie. The movie function definition seems very complicated. In reality it just indicates the movie function will return a shot function, like our random\_color above. Apart from this, the movie function is passed a variable \ardo{shotduration}, which must be set with how many milliseconds the shot must take. Internally, every time a shot is finished, this function \ardo{movie} will be called to obtain the next shot.

Below those two functions comes the internal loop to show a shot. This loop will call \ardo{movie} to obtain new shots, and will call the shot to obtain the frame to show. It will then take care of showing this frame for the frame duration (40ms). That's it.
}

\ned{De code ziet er complex uit, maar is eigenlijk verdeelt in twee delen: shots of acties die jij maakt, en een algemeen deel welke beslist wanneer een nieuw frame nodig is, dit frame opvraagt de shot, en dan subframe cyclussen start om dit specifieke frame 40ms te tonen. Dit laatste deel zal niet meer wijzigen, als je wil kun je proberen het te verstaan, als niet, geen probleem, het volstaat in staat te zijn je eigen shots te schrijven.

Laat ons over de code gaan. Zoals steeds beginnen we met de pinnen aanduiden die we zullen gebruiken. Dan komt de  \ardo{setup()} functie, welke de Arduino klaarmaakt. Niets nieuws dus.
\\
We bekijken hier hoe een shot gemaakt wordt. Hiervoor hebben we een functie nodig: bv. een willekeurige kleur. Deze functie heeft een specifiek functievoorschrift die al onze shots zullen moeten hebben:\newline
\textbf{ void random\_color(unsigned long framenr, int frame{$\lbrack$}3{$\rbrack$})}.\newline
Dus, een shot geeft geen waarde terug. Dit duiden we aan met  \ardo{void}. Het heeft wel twee parameters nodig:
het framenummer van het shot, en een lijst van 3 gehele getallen: {int frame{[}3{]}}. De functie dient deze lijst op te vullen met het frame dat getoond moet worden. Dat is het! Gezien onze kleuren lopen van 0 tot 64, gebruiken we \ardo{random(65)}. 

De volgende functie beschrijft onze film (\textit{movie} in het Engels). De functie definitie ziet er heel complex uit. In werkelijkheid duidt deze gewoon aan dat de \ardo{movie} functie een shot functie teruggeeft als waarde, zoals bevoorbeeld onze \ardo{random_color} functie van hierboven. Daarnaast krijgt de functie een variabele mee, \ardo{shotduration}, welke moet opgevuld worden met het aantal milliseconden van de duurtijd van je shot. De code zal dan telkens als een shot gedaan is, deze functie \ardo{movie} opnieuw oproepen om een volgend shot te bekomen en te tonen.

Onder deze twee functies komt dan de interne Arduino \ardo{loop} om een shot te tonen. Deze loop zal dus  \ardo{movie} oproepen om nieuwe shots te bekomen, en zal dan de shot oproepen om een frame nummer te bekomen. Het zal er dan voor zorgen dat deze frame getoond wordt voor de duur van een frame (40ms).
}

\engo{\begin{doE}
      \textbf{Preprogrammed colors}. To test that you can show all possible colors, change the random call in the function \ardo{random\_color} into the fixed value for only red, green or blue. 
     \end{doE}
}
\nedo{\begin{doN}
      \textbf{Voorgeprogrammeerde kleuren: een vaste kleur tonen}. 
Om te testen dat je alle kleuren kunt tonen, wijzig Code 7 zodat je een vaste kleur toont i.p.v. een random color, bv. altijd rood. \\
Om dit te doen moet je  de functie \ardo{random\_color} aanpassen zodat je een functie \ardo{fixed\_color} hebt. Test het dan met bv. enkel rood, enkel groen, of enkel blauw. 
     \end{doN}
}
\nedo{\begin{doN}
      \textbf{Twee shots tonen}. 
Pas nu Code 7 aan zodat je 1 seconde een vaste kleur toont en 2 sec een random kleur.   
     \end{doN}
}
\subsection{\engt{Smooth transitions} \nedt{Gladde overhangen}}

\eng{We now extend the previous code, and create a new shot, as an example of how to add shots. This shot is a smooth transition from a first color to a next color.

The code for the shot, and the \ardo{movie} function can be found in Code \ref{c:l2_d}.
So this replaces the shot and the movie part of the previous section. 

Some remarks on the code. We divide the entire duration in frames, and calculate which one is needed. When we do the transition, we use blending of the two colors: this is a number between 0 and 1, call it $b$. We then mix begin and end color as: 
$$(1-b)\times \mbox{begincolor} + b \times \mbox{endcolor}.$$
So, if we start with $b=0$, we have the begincolor, and at $b=1$ we have the endcolor. 

When you divide two integers, the result is an integer, so we use the \ardo{float} function to change an integer into a float. Like this we find the blend between 0 and 1 for a specific frame number. Finally, our frame consists of colors which we denote as an integer between 0 and 64, so we apply the \ardo{round} function to convert the float to the nearest integer. For example \ardo{round(1.3)=1} and \ardo{round(1.6)=2}.
}

\ned{We breiden nu de vorige code uit. We maken een nieuw shot en we zien zo hoe we shots kunnen toevoegen. Dit shot is een gladde overgang van een eerste kleur naar een andere kleur.

De code voor dit shot, en de \ardo{movie} functie die ze roept kun je vinden in  Code \ref{c:l2_d}. Dit vervangt het shot en movie deel van de vorige sectie.

Enkele opmerkingen. We verdelen de volledige duur in frames, en berekenen welke we nodig hebben. Als we een transitie doen blenden we de twee kleuren: dat is een nummer tussen 0 en 1, noem het $b$. We mixen dan begin en eindkleur als:
$$(1-b)\times \mbox{beginkleur} + b \times \mbox{eindkleur}.$$
Als we dus starten met $b=0$, hebben we de beginkleur, en voor $b=1$ de eindkleur.

Als je twee gehele getallen deelt, is het resultaat opnieuw een geheel getal. Daarom gebruiken we de \ardo{float} functie om een geheel getal (integer) in een re\"eel getal (float) te veranderen. Zo vinden we de blend tussen 0 en 1 voor een specifieke frame. Maar, ons frame bestaat wel uit kleuren die we aanduiden met een getal tussen 0 en 64, daarom passen we de functie \ardo{round} toe om de float te veranderen in de dichstbijgelegen integer. Bijvoorbeeld:  \ardo{round(1.3)=1} en \ardo{round(1.6)=2}.
}

\begin{code}\label{c:l2_d}
 \ \newline
\inputard{\string"../../sketches/old_versions/v01/Fe_cube_02_RGB_smooth_trans/Fe_cube_02_RGB_smooth_trans.ino\string"}{47}{112}
\end{code}

\engo{\begin{doE}
      \textbf{Your shot!}. Make your own shot now. For example, blink the LED always faster and faster.
      
      Tip: For example, if the shot is 60 seconds, and you start with a 2 second interval, you want to end with a 0.001 second interval. So, your interval could decrease linearly:
      $$y=2+\frac{0.001-2}{60} \mbox{time}$$

      Nicer: mix, this is blinking sequentially two different colors always faster. You should see them mix in front of you. Still nicer: mix red, green and blue amounts.
     \end{doE}
}
\nedo{\begin{doN}
      \textbf{Jouw shot}. Maak je eigen shot. Bevoorbeeld, knipper de LED altijd maar sneller en sneller.
      
      Tip: Bevoorbeeld, als je shot 60 seconden is, en je start van een 2 seconden interval, en je wil eindigen met een 0.001 seconden interval, dan moeten je intervallen lineair afnemen:
      $$y=2+\frac{0.001-2}{60} \mbox{tijd}$$

      Mooier: mengen, dit is twee kleuren afwisselend knipperen, en dit versnellen. Je zou de kleuren moeten zien vermengen. Nog mooier: rood, groen en blauw hoeveelheden mengen
     \end{doN}
}

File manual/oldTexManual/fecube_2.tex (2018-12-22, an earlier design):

\section{\engt{Lesson 3: LED Cube Construction} \nedt{Les 3: LED Cube constructie}}

\subsection{\engt{Layout breadboard}  \nedt{Opstelling schakelbord}}

\eng{We have all the necessary basis to start with making our Fe Cube. We start with putting all components on the breadboard. Then we test it with a program which is our previous RGB LED sketch adapted to the cube. Only when we have verified all works will we start the actual construction.

So, put following components in front of you:
\begin{enumerate}
 \item Your breadboard
 \item 9 RGB-LED (we assume common cathode in the following)
 \item 3 NPN (2N3904 normally)
 \item 9 220 $\Omega$ resistors
 \item many wires.
\end{enumerate}
First, put the RGB-LED on the board, connect the color pins with each other via wires, and connect the common cathode via a resistor to another line, see Fig.~\ref{f:lesson3_bb1}.

Connect then the resistors to pins 1 to 9. These are the pins that will feed the LED. So for a common cathode, these pins on \ardo{HIGH} will make the LED burn. Put the 3 NPN on the board. The color wire goes to the Emitter side (-) of the NPN for common cathode LED. The Colector side (+) goes to the Volt line of your breadboard. The Volt line of the breadboard goes to a 5V pin on the Arduino.

The Base leg of the NPN will control if the NPN junction is open or not. We will use pins 10, 11, 12 to control this. Your entire wiring should look like Fig.~\ref{f:lesson3_bb2}.
}

\ned{We hebben alles gezien om aan onze Fe Kubus te beginnen. We starten met alle componenten op het schakelbord te zetten. Dan testen we de schakeling met een programma die onze vorige RGB LED schets aanpast voor de kubus. Alleen als we zeker zijn dat alles werkt zullen we de effectieve constructie doen.

Plaats dus de volgende componenten voor jou:
\begin{enumerate}
 \item Jouw schakelbord
 \item 9 RGB-LED (we veronderstellen gemeenschappelijke kathode in wat volgt)
 \item 3 NPN (2N3904 normaal)
 \item 9 220 $\Omega$ weerstanden
 \item veel draden.
\end{enumerate}
Begin met de RGB-LED op je bord te zetten, verbindt de kleurpinnen met elkaar via draden, en connecteer de gemeenschappelijke kathode via een weerstand naar een andere lijn op je bord, zie Fig.~\ref{f:lesson3_bb1}.

Verbind nu de weerstanden met pinnen 1 tot 9. Deze pinnen zullen de LED van stroom voorzien. Dus, voor een gemeenschappelijke kathode zullen we deze pinnen op \ardo{HIGH} zetten om de LED te doen branden. Plaats dan de 3 NPN op het bord. De draden van een kleur gaan naar de Emitter zijde (-) van de NPN voor gemeenschappelijke kathode LEDs. De Collector zijde (+) gaat naar de Voltage lijn op je schakelbord. Deze Voltage lijn gaat dan naar een 5V pin op de Arduino.

Het Basis been van de NPN zal bepalen of de NPN junctie open is of niet. We zullen pinnen 10, 11, 12 gebruiken voor dit been. Je volledige schakeling zou er moeten uitzien als Fig.~\ref{f:lesson3_bb2}.
}

\begin{figure}
  \centering
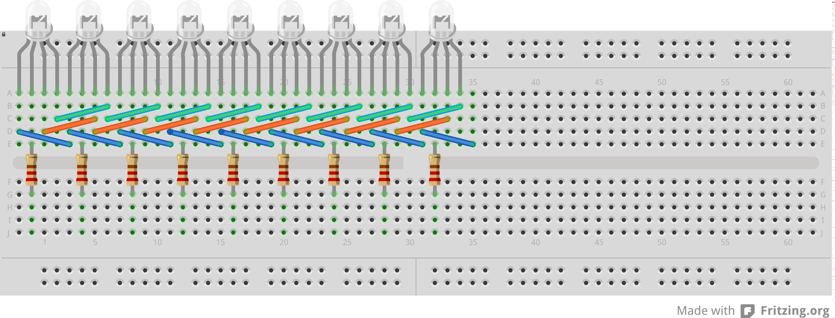
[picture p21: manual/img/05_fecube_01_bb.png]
   
\caption{\engt{Put the 9 LED on the board. Connect all equal colors to each other. The common cathode or anode goes with a 220 $\Omega$ resistor to a new line} \nedt{Plaats de 9 LED op het bord. Connecteer alle gelijke kleuren met elkaar. De gemeenschappelijke kathode of anode gaat met een 220 $\Omega$ weerstand naar een nieuwe lijn.}}
\label{f:lesson3_bb1}.
\end{figure}
%
\begin{figure}
  \centering
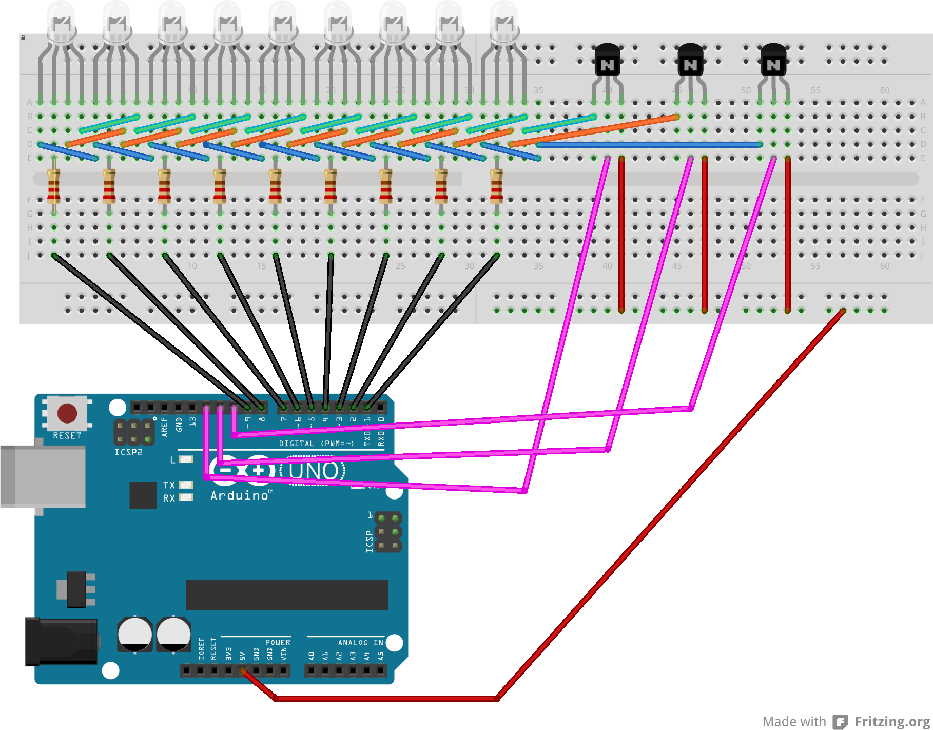
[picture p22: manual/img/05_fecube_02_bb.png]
   
\caption{\engt{Connect the resistors to pins 1 to 9. The colors go via an npn to the GND (cathode) or 5V (anode). Pins 10, 11, 12 go to the NPN to control the colors.} \nedt{Verbind de weerstanden met pinnen 1 tot 9. De kleuren gaan via een npn naar de GND (kathode) of 5V (anode). Pinnen 10, 11, 12 gaan naar de NPN om de kleuren te schakelen.}}
\label{f:lesson3_bb2}
\end{figure}

\subsection{\engt{Testing breadboard Fe Cube}  \nedt{Schakelbord Fe Cube uittesten}}

\eng{We will only verify we can make the breadboard Fe Cube work. For this we adapt our RGB sketches. We will make a movie showing  4 seconds red, then 4 seconds green, then 4 seconds blue, then 1 minute a random color, then smooth transitions for 1 minute.

This means we need all the shots we created for the RGB LED in the previous lesson, and need to create an adapted \ardo{movie} function to connect the shots as we want. We also need to change the start so that instead of only one led pin, we start up 9 led pins. 

In our previous script, we had ledR, ledG, ledB, which are easy to understand names. The LED was called led1, so we could use led1 to led9. This is not very helpfull if you want to program certain light effects. So, let's give them better names. We have a top layer (T), and a bottom (B) layer, and a single LED in the middle. Then we can divide the cube in a left (L) and right (R), and in a front (F) and an aft (A). So, let's call the LEDs:
\begin{enumerate}
\item ledTLF
\item ledTLA
\item ledTRF
\item ledTRA
\item ledBLF
\item ledBLA
\item ledBRF
\item ledBRA
\item ledMID
\end{enumerate}
Open Code \ref{c:l2_d}, and save it under a new name. The changes needed are first defining all the pins:
}

\ned{We zullen enkel controleren dat we deze schakelbord variant van de Fe kubus kunnen doen werken. Hiertoe passen we onze RGB schets aan. We zullen een film maken die eerst 4 seconden rood toont, dan 4s groen, dan 4s blauw, dan 1 minuut een willekeurige kleur, en uiteindelijk gladde overgangen voor een minuut.

Dit betekent dat we al de shots die we gemaakt hebben voor de RGB LED in de vorige lessen zullen gebruiken en aanpassen. De \ardo{movie} functie zullen we zo maken dat al deze shots elkaar opvolgen. In plaats van \'e\'en RGB led hebben we er nu 9, dus dienen we deze 9 nu samen aan of af schakelen. 

In de vorige schetsen hadden we ledR, ledG en ledB, welke gemakkelijk te verstaan zijn. De LED noemden we led1. We zouden nu led1 tot led9 kunnen gebruiken, maar dat is niet handig als we later lichteffecten maken. Laat ons ze dus betere namen geven. We hebben een top (T) en een bodem (B) laag, en een enkele LED in het midden. Dan kunnen we de kubus opdelen in een links (L) en een rechts (R), en in een frontaal (F) en een achter (A). Daarom noemen we de LEDs:\begin{enumerate}
\item ledTLF
\item ledTLA
\item ledTRF
\item ledTRA
\item ledBLF
\item ledBLA
\item ledBRF
\item ledBRA
\item ledMID
\end{enumerate}
Open Code \ref{c:l2_d}, en sla het op onder een andere naam. De eerste wijziging is alle pinnen defini\"eren:
}

\inputard{\string"../../sketches/old_versions/v01/Fe_cube_03_cube_test1/Fe_cube_03_cube_test1.ino\string"}{5}{11}

\eng{Next we need to define in \ardo{setup} that these are digital output pins, so:}

\ned{Vervolgens dienen we in \ardo{setup} deze pinnen als digitale output pinnen te initializeren:}

\inputard{\string"../../sketches/old_versions/v01/Fe_cube_03_cube_test1/Fe_cube_03_cube_test1.ino\string"}{15}{24}

\eng{We test the cube as a single LED, so all LED are on, or all LED are off. Hence, instead of setting only led1 on, we write a function to put all LED on, and put that in \ardo{show\_subframe\_color}}

\ned{We testen de kubus als een enkele LED, dus alle LED zijn aan, of allemaal af. Bijgevolg zullen we led1 aanzetten vervangen door een functie die alle LED aan zet, welke we plaatsen in de functie \ardo{show\_subframe\_color}
}

\inputard{\string"../../sketches/old_versions/v01/Fe_cube_03_cube_test1/Fe_cube_03_cube_test1.ino\string"}{217}{221}

\eng{This new function for setting the pins \textbf{on} sends a \ardo{LOW} signal to the pins, as we are connected to the LED cathode (-)}

\ned{Deze nieuwe functie om de pinnen \textbf{aan} te zetten stuurt \ardo{LOW} signalen naar de pinnen, gezien ze verbonden zijn aan de LED kathode (-)}

\inputard{\string"../../sketches/old_versions/v01/Fe_cube_03_cube_test1/Fe_cube_03_cube_test1.ino\string"}{245}{251}

\eng{Finally, we need to update the \ardo{movie} function so that it would do what we want. So this function needs to be}
\ned{Als laatste dienen we de \ardo{movie} functie aan te passen zodat het zou doen wat we willen. Deze functie dient te zijn}

\inputard{\string"../../sketches/old_versions/v01/Fe_cube_03_cube_test1/Fe_cube_03_cube_test1.ino\string"}{109}{148}

\eng{
In the function \ardo{movie} you see the appearance of the \ardo{switch} structure. This is a programming structure that works like a switch based on a variable. The syntax is:
}

\ned{In de functie \ardo{movie} zie je een \ardo{switch} structuur. Dit is een programmeerstructuur die werkt als een test van een variabele. De syntax is:
}

NIET BESCHIKBAAR 
%\inputard{\string"codefrag/switch.ino\string"}{1}{10}

\eng{In this switch structure, the commands for which the var is equal to one of the labels are executed from that point onwards, up to a \ardo{break;} command. It is nicer to read than a big \ardo{if} structure to test on a variable, but otherwise works just like an if structure.
}

\ned{In deze switch structuur worden de commando's voor dewelke de variabele gelijk is aan een label uitgevoerd vanaf dat label, en dit tot op het \ardo{break;} commando. Het is mooier om te lezen in code dan een grote \ardo{if} structuur om te testen op een variabele, maar werkt anders precies als een if structuur.
}

\engo{\begin{doE}
      \textbf{One LED}. To test that a single LED does indeed not shine brighter when it is alone, change the \ardo{all\_led\_on} code so that only one LED has power.
     \end{doE}
}
\nedo{\begin{doN}
      \textbf{\'E\'en LED}. Om te testen dat een LED alleen inderdaad niet helderder brandt, wijzig de \ardo{all\_led\_on} functie zodat maar \'e\'en LED aan is.
     \end{doN}
}

\subsection{\engt{Construction}  \nedt{Constructie}}
\eng{We verified all is working, time to construct the cube. For this we will take components of our breadboard, and solder the connections in a FE Cube form.
We call our cube the Fe Cube because it is organized as the Iron (Fe) metal lattice. Solid iron has a specific structure which is depicted in the \href{http://en.wikipedia.org/wiki/Atomium}{Atomium building} in Brussels, see Figure \ref{f:atomium}. 

We call this structure a \href{http://en.wikipedia.org/wiki/Cubic_crystal_system}{Body-centered cubic crystal system}, short \textbf{bcc}.  This is a cube with an extra node in the center. 
}

\ned{De schakeling werkt, tijd om de kubus te construeren. Om dit te doen zullen we de componenten van ons schakelbord een voor een nemen en solderen in de vorm van een Fe Cubus. 

We noemen onze kubus een Fe Cubus omdat het georganizeerd is zoals het Ijzer (Fe) metaal kristalrooster. Ijzermetaal heeft een specifieke structuur welke uitgebeeld wordt in het  \href{http://nl.wikipedia.org/wiki/Atomium}{Atomium gebouw} in Brussel, zie Figuur \ref{f:atomium}.

We noemen deze structuur een \href{http://en.wikipedia.org/wiki/Cubic_crystal_system}{Lichaams-gecentreerd kubisch kristalrooster}, in het kort \textbf{bcc}. 
}

\begin{figure}
  \centering
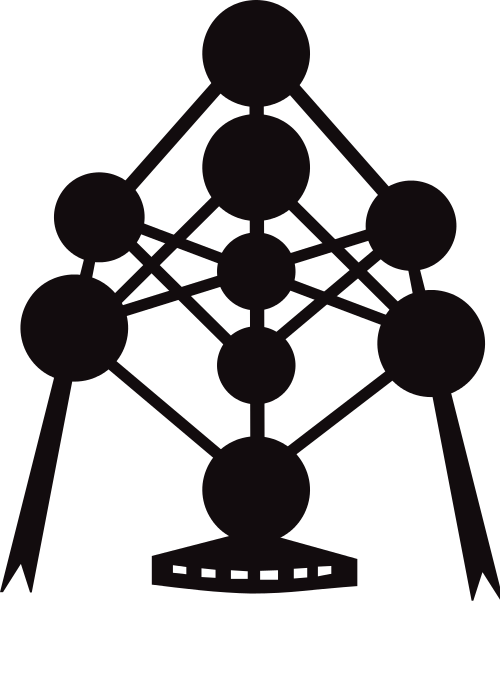
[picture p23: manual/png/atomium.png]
  
\caption{\engt{Road sign depicting the Atomium building} \nedt{Wegmarkering in Brussel voor het atomium gebouw.}}
\label{f:atomium}
\end{figure}

\section{\engt{Lesson 4: Fire up the LED Cube} \nedt{Les 4: De LED Cube gebruiken}}

\subsection{\engt{Testing the Fe Cube} \nedt{De Fe Cube testen}}
\eng{You finished now constructing the cube. We need to test if all lights are working. Start with the same sketch you used for the breadboard cube. If you connect everything correctly, it should just work. 

If things are not working, you have some extra soldering to do: replace a blown out LED, make connections stronger, ... . Don't give up now. These are the last construction problems of your LED cube.}

\ned{De constructie is af. We dienen nu te teseten of alle lichten correct werken. Start met dezelfde schets die je gebruikte voor de schakelbord kubus. Als je alles correct verbindt zou het moeten werken!

Als er dingen niet werken heb je extra soldeerwerk voor de boeg: vervang een gesprongen LED, maak verbindingen sterker, ... . Nu niet opgeven! Dit zijn de laatste constructieproblemen voor je LED kubus.}

\subsection{\engt{Generic patterns ... and a snake} \nedt{Algemene patronen ... en een slang}}

\eng{
We have a working cube now, but we can only show single colors with our current code. Let's change that. We want to be able to write some light effects, and show that on our cube. So let us create a \ardo{movie} function that can load patterns we create. Like that we can write down a pattern, and pass it to this function. The first pattern we want to make is the snake pattern: a single light that jumps from LED to LED in the three base colors.

We need to define the data structure of a pattern. What needs to be in a pattern?
\begin{enumerate}
 \item We need for 9 LED what color they must have. A color is a RGB value like (13,50,2), assuming we still use values between 0 and 64. That is, we need $3\times 9 = 27$ numbers to form a frame now.
 \item We need to know how long to hold a frame before moving to the next frame. So, we need an extra number for the milliseconds, for a total of 28 numbers.
\end{enumerate}
Therefore, a pattern will look like a list of numbers which indicate the different frames and how long they take. For a single frame this will be:\newline
$\{$R1,G1,B1, R2,G2,B2, R3,G3,B3, R4,G4,B4, R5,G5,B5, R6,G6,B6, R7,G7,B7, R8,G8,B8, R9,G9,B9, duration$\}$\newline

The order of the LEDS in the frame will be ledTLF, ledTLA, ledTRF, ledTRA, ledBLF, ledBLA, ledBRF, ledBRA, ledMID. If a shot consists of pattern with 20 fixed frames, we create a single large array with all the frames, one after the other. As Arduino code is not that clever, we need to know somehow what the last pattern is. We could count and pass this number of patterns, but that will quickly lead to an error. Easier is to finish the list with a fake pattern with duration 0. If we read this 0, we know the pattern is finished. 

In our code, our \ardo{movie} function will use a \ardo{moviepattern} function that will handle a pattern you give it. The function will divide the pattern in shots: one shot per fixed frame. The shot will take as long as the duration you have passed in the pattern. This shot is the analogue of the \ardo{fixed\_color} for the single RGB LED: \ardo{fixed\_pattern}, which is a shot that produces a single fixed image on the cube.

There is an extra complication though. The Arduino does not have a lot of memory to work with. There is the SRAM memory with which the Arduino works, and there is Flash memory where your program will be stored. All general variables in your code need to be available at all times, so they need to be stored in SRAM memory. Our patterns can be large though, and the memory would fill up, causing the Arduino to just not produce anything anymore. To avoid this, we will store the patterns in flash memory, and only obtain the frame of the pattern we need. Because of this, you will find in the code:}
\ned{We hebben een werkende LED kubus, maar we kunnen enkel maar vaste kleuren tonen met de huidige code. Laten we dat veranderen. We willen lichteffecten kunnen programmeren. Laat ons dus een \ardo{movie} functie maken die patronen kan laden. Op deze manier kunnen we een lichtpatroon opschrijven en dat door deze functie laten laden op de kubus. Het eerste patroon die we willen maken is een slangenparoon: een enkel lichtje dat springt van LED naar LED in de 3 basiskleuren.

We moeten een data structuur maken voor het patroon. Waaruit moet een patroon bestaan?
\begin{enumerate}
 \item We dienen voor de 9 LED te weten welke kleur ze moeten hebben. Een kleur is een RGB waarde zoals  (13,50,2), ervanuit gaande dat we nog steeds waarden tussen 0 en 64 gebruiken. We hebben nu dus $3\times 9 = 27$ nummers nodig om een frame van een shot te maken.
 \item We moeten dan ook nog weten hoe lang we een enkel frame moeten aanhouden vooraleer naar het volgende frame in het patroon te schakelen. We hebben dus nog een extra nummer nodig voor het aantal milliseconden dat een frame moet getoond worden, voo een totaal van 28 nummers.
\end{enumerate}
Een patroon zal dus lijken op een lijst van nummers welke aanduiden welk frame te tonen en voor hoe lang. Voor een enkele frame zal dit zijn:\newline
$\{$R1,G1,B1, R2,G2,B2, R3,G3,B3, R4,G4,B4, R5,G5,B5, R6,G6,B6, R7,G7,B7, R8,G8,B8, R9,G9,B9, duurtijd$\}$\newline

De orde van de LEDs in het frame zal ledTLF, ledTLA, ledTRF, ledTRA, ledBLF, ledBLA, ledBRF, ledBRA, ledMID zijn. Als een shot bestaat uit een patroon met 20 vaste frames, dan zullen we een enkele grote lijst maken met alle frames, de ene na de andere. Gezien Arduino code niet zo slim is moeten we op een of andere manier doorgeven welke het laatste frame is. We zouden dit zelf kunnen tellen en doorgeven, maar dat leidt vlug tot fouten. Gemakkelijker is om te eindigen met een vals patroon met duurtijd 0. Als we deze 0 lezen weten we dat het patroon gedaan is.

In onze code zal de  \ardo{movie} functie nu een \ardo{moviepattern} functie oproepen. Deze zal het patroon afspelen die je doorgeeft. De functie zal het patroon intern verdelen in een shot per gegeven frame. Dit shot zal dan zo lang duren als de duurtijd die je opgegeven hebt in het patroon. Dit shot is de tegenhanger van de functie \ardo{fixed\_color} bij de enkele RGB LED: \ardo{fixed\_pattern}, welke een shot is dat een enkel vast beeld op de kubus toont.

Er is evenwel nog een complicatie. De Arduino heeft niet veel geheugen om mee te werken. Er is SRAM geheugen welke de Arduino mee werkt, en Flash geheugen waar het programma opgeslagen wordt. Alle globale variabelen moeten altijd beschikbaar zijn en bevinden zich dus in SRAM. Onze patronen kunnen evenwel groot zijn, en het geheugen zal dat vol geraken, waarna de Arduino stopt met werken. Om dit te vermijden zullen we de patronen opslaan in flash geheugen, en enkel het frame dat we nodig hebben laden in SRAM geheugen. Daarom zul je het volgende terugvinden in de code:
}

NIET BESCHIKBAAR
%\inputard{\string"codefrag/defavr.ino\string"}{1}{3}

\eng{
This will define the functions we need to move data from flash memory to SRAM.
The \ardo{PROGMEM} part replaces a normal \ardo{array} construction and defines an array of integers. It indicates we want an array of integers, but we want it in \ardo{PROGMEM}, so in the memory that stores our program, the flash memory.

You call in the \ardo{movie} function the new \ardo{moviepattern} function if you want to send a pattern to the LED cube. We cannot pass a variable with the moviepattern we want to use because this is now in \ardo{PROGMEM}. You will need to edit \ardo{moviepattern} to load the correct pattern.

In the function \ardo{moviepattern} you see twice the appearance of the \ardo{switch} structure. 

In the first switch structure you need to add the start conditions of the patterns you want to show. In the second switch structure you need to copy the pattern you want into the \ardo{shotpattern} variable, as well set the \ardo{nextduration} variable to the duration of the \textit{next} shot. The function \ardo{pgm_read_word_near} is the function that will copy from the program memory (flash) to SRAM. The only thing needed to change there is the name of the pattern, or add a case with your pattern.

The start conditions for a pattern are:
\begin{enumerate}
 \item \textbf{patternscale\_start}: with what time scaling to start? This is multiplied with the duration of a frame.
 \item \textbf{patternscale\_speedup}: a value larger than 0 and less than 1. Every time the pattern is finished, you can make it go faster. This speedup is multiplied with the duration of the frames
 \item \textbf{patternscale\_min}: it has no use to go always faster, you need to stop some time. This indicates the minimum scale, after which we assume the pattern can be completely stopped.
 \item \textbf{patternrepeatmin}: as the fastest presentation at patternscale\_min will be so fast you can hardly see it, you can set with this variable how many times to repeat this fastest pattern before we really consider the pattern as finished. When the pattern is finished in this way, the label of the switch command, NRPATTERN in the sketch, is increased by one, causing a next pattern to be loaded if that is present.
 \item \textbf{totalpatterns}: we use the switch command to select the pattern. Give with this variable how many patterns in total you use. 
\end{enumerate}
To show the influence of changing these parameters, the code has an extra pattern called PatternCircle, which uses different starting values.

The rest of the extra code is to compute the correct speedup of the shots in the pattern, and to determine correctly when a pattern is finished and the next pattern can begin.
}

\ned{Dit definieert de functies die we nodig hebben om data te verplaatsen van flash naar SRAM.  Het  \ardo{PROGMEM} gedeelte vervangt een gewone lijst (\ardo{array}) constructie en maakt voor ons een lijst van integers (gehele getallen, ons patroon dus). Het duidt aan dat we een lijst integers willen, maar dat we die in \ardo{PROGMEM} willen, dus in flash.

In de functie \ardo{moviepattern} zie je twee keer een \ardo{switch} structuur. 

In de eerste switch structuur dien je de startcondities van je patroon te schrijven. In de tweede switch structuur dien je je patroon te copi\"eren in de \ardo{shotpattern} variabele, alsook de \ardo{nextduration} variabele opvullen met de duur van het \textit{volgende} shot. De functie \ardo{pgm_read_word_near}  is de functie die zal copi\"eren van programma geheugen (flash) naar SRAM. Het enige dat je hier normaal moet wijzigen is de naam van je patroon, of het toevoegen van een switch case voor jouw patroon.

De startcondities van een patroon zijn:
\begin{enumerate}
 \item \textbf{patternscale\_start}: met welke tijdsschaling wil je beginnen. deze schaal wordt vermenigvuldigd met de duur van een frame.
 \item \textbf{patternscale\_speedup}: een waarde tussen 0 en 1. Elke keer een patroon gedaan is kun je het hiermee vlugger doen gaan. Deze speeup wordt ook vermenigvuldigd met de duur van een frame.
 \item \textbf{patternscale\_min}: je kan niet altijd maar sneller gaan, je moet ook eens stoppen. Deze parameter bepaald de minimum tijdsschaling, na dewelke het patroon volledig kan stoppen.
 \item \textbf{patternrepeatmin}: gezien de snelste weergave met patternscale\_min vaak zo vlug gaat dat je het niet kunt zien, kun je hier opgeven hoe vaak deze snelste weergave moet herhaald worden. Daarna zullen we het patroon defenitief als gedaan beschouwen, en wordt NRPATTERN met 1 verhoogd. NRPATTERN is de variabele die in de switch structuren gebruikt wordt. Het verhogen met een zal dus zorgen dat een volgend patroon uitgevoerd wordt.
 \item \textbf{totalpatterns}: gebruik deze variabele om aan te duiden hoeveel patronen er in totaal zijn. 
\end{enumerate}
Om te tonen wat de invloed van deze parameters is bevat de code een extra patroon: PatternCircle. Deze heeft andere startwaarden en gedraagd zich dus anders.

De rest van de extra code is dan om de correcte versnelling van de shots in een patroon te berekenen, en om te bepalen of een patroon gedaan is en een nieuwe kan beginnen.
}

\eng{
The entire code is given in Code \url{https://github.com/ingegno/fecube/blob/master/sketches/old_versions/v01/Fe_cube_03_cube_pattern/Fe_cube_03_cube_pattern.ino} %\ref{c:ledcube_snake}.
}

\ned{
De vollige code kun je vinden op \url{https://github.com/ingegno/fecube/blob/master/sketches/old_versions/v01/Fe_cube_03_cube_pattern/Fe_cube_03_cube_pattern.ino} %\ref{c:ledcube_snake}.
}

% \begin{code}\label{c:ledcube_snake}
%  \ \newline
% \inputardfull{\string"../../sketches/old_versions/v01/Fe_cube_03_cube_pattern/Fe_cube_03_cube_pattern.ino\string"}
% \end{code}

\engo{\begin{doE}
      \textbf{Your pattern}. Time to make your own pattern. How about a rotating emergency vehicle light? Or christmass twinkle? Or ....
     \end{doE}
}
\nedo{\begin{doN}
      \textbf{Jouw patroon}. Tijd om je eigen patroon te maken. Wat denk je van een zwaailicht? Of kerstboom flikkering? Of ...
     \end{doN}
}

\subsection{\engt{Intelligent patterns ... and a beating heart} \nedt{Intelligente patronen ... en een kloppend hart}}

\eng{We can do patterns, which is nice, but patterns are a lot of work to create. This is no different in animation movies or with special effects. They take a lot of time to make. So, people use programming instead to do as much of the work as possible. 

For example, if you look at our snake pattern, we essentially repeat 3 times the same pattern but for a different color. It would be easier to write the pattern once, and then in the code shift the pattern one color. As another example, consider writing a pattern for a beating heart. We would go from no light, to always more red. When all if fully red, we would invert it. In essence, we would need to repeat the pattern in reverse order. Again, with software this would be easier and avoid us writing a long pattern. 

Before writing more software, it is important to design it somewhat. We now end a pattern with a dummy line which has duration 0. As a duration smaller than zero makes no sense, we can use a negative duration to indicate performing a specific operation on the pattern, for example reverse it as in the beating heart, or shift the colors as in the snake. Apart from this, we would need a counter also to indicate how often to extend the pattern once the end is reached. 

We will use following definitions: the variable \ardo{extend\_pattern} will contain how often the pattern must be extended when the end is reached. The final duration will indicate how the pattern must be repeated. We will consider as durations
\begin{itemize}
 \item[0]: the pattern does not change.
 \item[-1]: reverse the pattern in the next repeat
 \item[-11]: shift the colors one to the right: R$\rightarrow$G, G$\rightarrow$B, B$\rightarrow$R
 \item[-12]: shift the colors two to the right: R$\rightarrow$B, G$\rightarrow$R, B$\rightarrow$G
 \item[-90]: rotate the shot over -90 degrees. Ideal to create rotating animations.
 \item[-180]: flip the shot, so TLF becomes TRA
 \item[-270]: rotate the shot over 90 degrees
\end{itemize}

Doing all these changes will increase the amount of code. As our patterns are smaller however, we will be able to do more with less memory.
}

\ned{We kunnen nu patronen maken, maar dat is wel veel werk. Dit is niet verschillend van animatiefilms met speciale effecten. Veel tijd is nodig om die te maken. Om dit te versnellen zullen ontwikkelaars zoveel mogelijk programmeren, om zo manueel werk te besparen.

Bevoorbeeld, als we ons slangenparoon bekijken zien we in essentie hetzelfde patroon 3 keer herhaald, maar wel voor een andere kleur. Het zou makkelijker zijn het patroon \'e\'en keer schrijven, en dan met een programma het op een andere kleur toe te passen. Als een ander voorbeeld, stel dat je een kloppend hart patroon wil maken. Dan ga je van geen licht naar alle LED die rood worden. Zodra alles rood gaan we opnieuw naar geen licht, we moeten dus het patroon omdraaien. Als we dit omdraaien gewoon kunnen programmeren dan kunnen we vermijden een lang patroon te schrijven!

Vooraleer nieuwe code te schrijven is het belangrijk eerst over het ontwerp na te denken. We eindigen nu een patroon met een valse lijn met duur 0. Gezien een duur kleiner dan 0 geen zin heeft, kunnen we een negatieve duur gebruiken om een effect aan te duiden om het patroon voort te zetten. Bevoorbeeld, het patroon herhalen met een andere kleur. We zullen dan wel moeten bijhouden hoeveel keer we het patroon moeten uitbreiden met een effect, zodat we zouden weten wanneer het echte einde bereikt is. 

Laat ons volgende defenities invoeren: met de variabele \ardo{extend\_pattern} duiden we aan hoeveel keer we het patroon uitbreiden. De duurtijd van de valse eindlijn zal aanduiden hoe het patroon moet herhaald worden. We beschouwen als mogelijke duurtijden
\begin{itemize}
 \item[0]: Het patroon wijzigt niet.
 \item[-1]: keer het patroon om voor de volgende herhaling (dus van achter naar voor het patroon lezen)
 \item[-11]: wijzig de basiskleuren naar rechts, dus: R$\rightarrow$G, G$\rightarrow$B, B$\rightarrow$R
 \item[-12]: wijzig de basiskleuren naar links, dus : R$\rightarrow$B, G$\rightarrow$R, B$\rightarrow$G
 \item[-90]: roteer het shot over -90 degrees. Ideaal om roterende animaties te maken.
 \item[-180]: flip het shot, dus TLF wordt TRA
 \item[-270]: roteer het shot over 90 graden
\end{itemize}

Al deze wijzigingen zullen de hoeveelheid code doen toenemen. Onze patronen kunnen evenwel kleiner zijn, waardoor we minder geheugen moeten gebruiken.

}

\eng{So, the patterns can be shorter. Here are the two patterns we consider, our snake of before, and the beating heart.}

\ned{De patronen kunnen dus korter zijn. Hier zijn de twee patronen die we beschouwen, onze slang van eerder, en een kloppend hart.}

\inputard{\string"../../sketches/old_versions/v01/Fe_cube_03_cube_intpattern/Fe_cube_03_cube_intpattern.ino\string"}{18}{67}

%\begin{code}\label{c:ledcube_heart}
% \ \newline
%\inputardfull{\string"../../sketches/old_versions/v01/Fe_cube_03_cube_intpattern/Fe_cube_03_cube_intpattern.ino\string"}
%\end{code}

\eng{All the other changes are in our \ardo{moviepattern} function. We have two extra control variables: \ardo{extend\_pattern} indicating how many times a single pattern is extended by a copy with some effects on. So, for the original snake, we reduced the 3 loops to one loop in red, so we need to extend it twice to obtain the original length.

The other new variable is \ardo{starteffect}. That is, we need not wait for an extend to apply an effect, we can do it from the start. To show what is possible with effects, we manipulate the red snake pattern in 4 different ways, as well as adding a beating heart pattern. The full code is in \url{https://github.com/ingegno/fecube/blob/master/sketches/old_versions/v01/Fe_cube_03_cube_intpattern/Fe_cube_03_cube_intpattern.ino}. Only the start of the \ardo{moviepattern} function with the two switch statements is something you would want to change for your own patterns. See Code
\ref{c:int_pat} for this start.
}

\ned{Al de andere veranderingen zijn in onze \ardo{moviepattern} functie. We hebben twee nieuwe controle variabelen: \ardo{extend\_pattern} duidt aan hoe vaak we het patroon uitbreiden met een copie met effecten toegepast. Dus, voor de originele slang reduceren we de 3 gekleurde slangen door een enkele rode, en breiden we het twee keer uit.

De andere nieuwe variabele is \ardo{starteffect}. Dit is het effect die we vanaf de start toepassen. Om te tonen wat mogelijk is met de effecten manipuleren we de rode slang op 4 verschillende manier, en voegen we het kloppend hart shot toe. De volledige code is in \url{https://github.com/ingegno/fecube/blob/master/sketches/old_versions/v01/Fe_cube_03_cube_intpattern/Fe_cube_03_cube_intpattern.ino}.
Enkel de start van de \ardo{moviepattern} functie met de twee \ardo{switch} structuren zou je moeten wijzigen om je eigen patronen te gebruiken. Zie Code \ref{c:int_pat} voor deze start.
}

\begin{code}\label{c:int_pat}
 \ \newline
\inputard{\string"../../sketches/old_versions/v01/Fe_cube_03_cube_intpattern/Fe_cube_03_cube_intpattern.ino\string"}{211}{293}
\end{code}

\engo{\begin{doE}
      \textbf{More patterns}. The effects are working? Add another effect, eg a color change. Or just write a new pattern using some of the effects.
     \end{doE}
}
\nedo{\begin{doN}
      \textbf{Meer patronen}. De effecten werken op je Fe Kubus? Voeg een nieuw effect toe, bevoorbeeld een kleurverandering. Of schrijf gewoon een nieuw patroon dat van enkele effecten gebruik maakt.
     \end{doN}
}

\newpage
\section{\engt{Lesson 5: Interaction with a push button} \nedt{Les 5: Interactie met een drukknop}}

\eng{You can do wonderful things with your cube. But it would be nice if it was a bit more user friendly. Would it not be super if we could interact with the cube? For example, change effect when we push a button? Or change your cube into a dice that you roll when you push on a button.
}
\ned{Je kan prachtige dingen doen met je kubus. Maar we kunnen het nog wat gebruiksvriendelijker maken. Ware het niet super als je kon interageren met je kubus? Bevoorbeeld van effect veranderen als je een knop drukt? Of je kubus omtoveren in een dobbelsteen die je rolt als je op de knop drukt...}

\subsection{\engt{How does a push button work?} \nedt{Hoe werkt een drukknop?}}

\eng{Take the push button. You see 4 pins, and a button you can push down, but which jumps back to the start position when you release it. There are two pins on one side, and two on the opposite side. Put the button with one side with pins towards you, and one away. 
Normally the pins on the left are connected, and the pins on the right also. Then, when you press the button, the left and the right will be connected.

Why 4 pins and not 2? Well, this makes it easier to solder. Normally you will need to connect more than two wires to the button, and having a different pin to solder to is easier. 

To verify you understand what pin is what, we make a little circuit with a LED, a 330$\Omega$ resistor, and the push button. Use the push button to interrupt the power to the LED, and use your 5V and GND pins on the Arduino to provide current. No code is needed, you could also use a 3V coin button battery for this exercise.

The wiring is given in Figure \ref{f:lesson5_pbtn1}. If you push the button the light should switch on.
}

\ned{Neem een drukknop. Je ziet 4 pinnen en een knop die je kan indrukken, maar welke terugkeert naar de beginpositie zodra je loslaat. Er zijn twee pinnen aan een zijde, en twee aan de overstaande zijde. Leg de knop zo dat een zijde met pinnen naar je toe, en de andere van je weg. Normaal gezien zijn de pinnen links verbonden met elkaar, alsook die rechts. Als je de knop indrukt worden ook links en rechts met elkaar verbonden.

Waarom 4 pinnen en niet 2? Dit is omdat het makkelijker solderen is zo. Je zal vaak meer dan 2 draden aan een knop moeten bevestigen, en dus zijn twee extra pinnen handig.

Om te zien of je goed begrijpt welke pin wat doet maken we een klein circuit met een LED, een 330$\Omega$ weerstand en een drukknop. Gebruik de drukknop om de stroom naar de LED te onderbreken, en gebruik de 5V en GND pinnen van de Arduino om stroom te leveren. Je hebt geen code nodig, en je zou ook een 3V knoopbatterij kunnen gebruiken voor deze oefening.

Het schema is gegeven in Figuur \ref{f:lesson5_pbtn1}. Als je de knop indrukt zou het licht aan moeten gaan.
}
\begin{figure}
  \centering
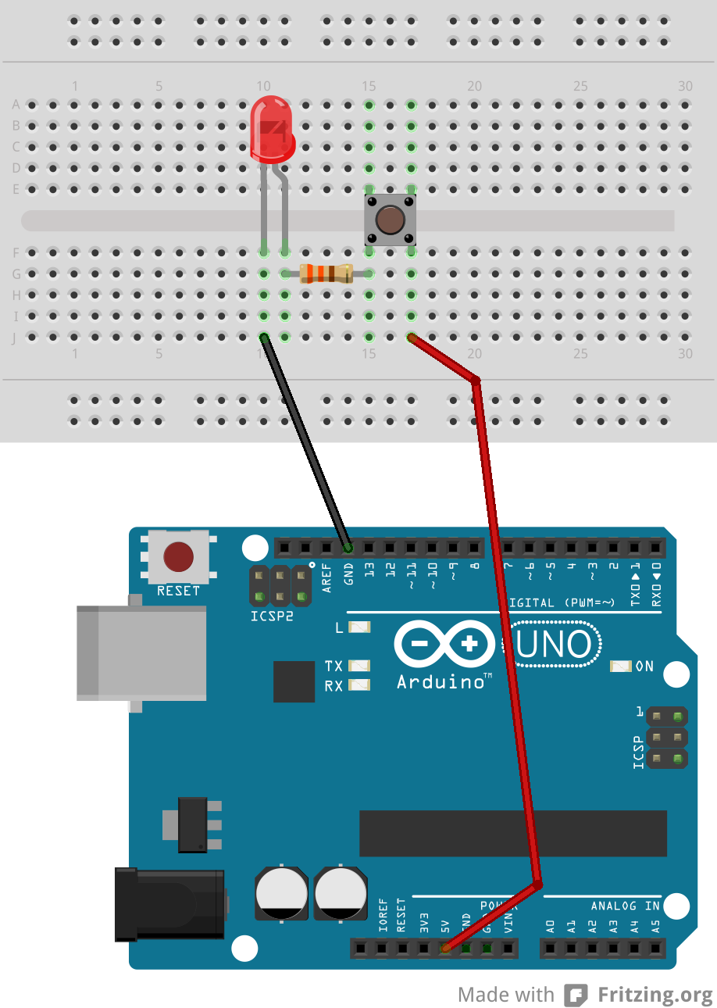
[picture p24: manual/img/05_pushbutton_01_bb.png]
   \ \ 
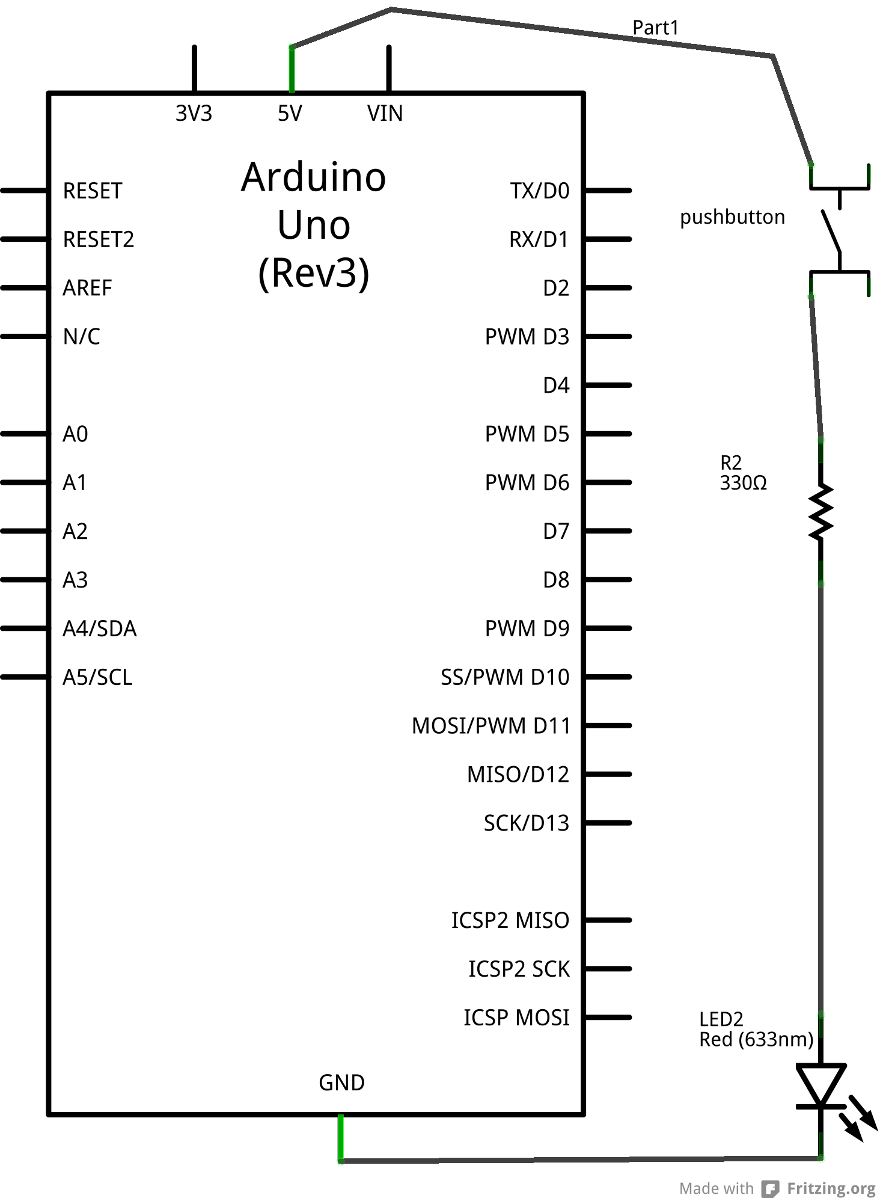
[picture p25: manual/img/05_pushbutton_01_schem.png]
  
\caption{\engt{Power, a pushbutton and a LED, and you can control the LED. No Arduino code needed!}
\nedt{Stroom, een drukknop en een LED, en je can de LED sturen. Geen Arduino code nodig!}}
\label{f:lesson5_pbtn1}       % Give a unique label
\end{figure}

\subsection{\engt{Reading pushbutton state} \nedt{Drukknop status lezen}}

\eng{In the previous exercise we have learnt that we can use a push button to interrupt the current. That can be useful in some circumstances, but not for our Fe Cube. Instead, we want to use the button to receive input from the user. In other words, we want to know if the user pressed the button or not, and then react to that with Arduino code.

The Arduino has a special function to read input from a digital pin: \ardo{digitalRead(pin)}. To use this method, a pin must be defined as \ardo{INPUT} in the \ardo{setup} function: \ardo{pinMode(pin, INPUT);}. 

The function will read \ardo{HIGH} if the pin is on 5V, and \ardo{LOW} when on GND. So the trick is to create a circuit that is \ardo{LOW} when the button is not pressed, and \ardo{HIGH} when the button is pressed. Such a circuit is given in Figure \ref{f:lesson5_pbtn2}.
}
\ned{In de vorige oefening hebben we geleerd dat een drukknop de stroom kan onderbreken. Dit kan nuttig zijn in sommige omstandigheden, maar niet voor onze Fe Kubus. In de plaats willen we een knop waardoor we input kunnen krijgen van de gebruiker. In andere woorden, we willen weten als de gebruiker de knop drukt of niet, en we willen daarop reageren via Arduino code.

De Arduino heeft een speciale functie om input te lezen van een digitale pin:\ardo{digitalRead(pin)}. Om deze methode te gebruiken moeten we een pin defini\"eren als \ardo{INPUT} in de \ardo{setup} function: \ardo{pinMode(pin, INPUT);}. 

De functie zal \ardo{HIGH} lezen als de pin op 5V staat en \ardo{LOW} als ze op GND is. De truck is dus om een circuit te maken die  \ardo{LOW} is als de knop niet ingedrukt is en \ardo{HIGH} als de knop ingedrukt is. Zo'n circuit is gegeven in Figuur \ref{f:lesson5_pbtn2}.
}

\begin{figure}
  \centering
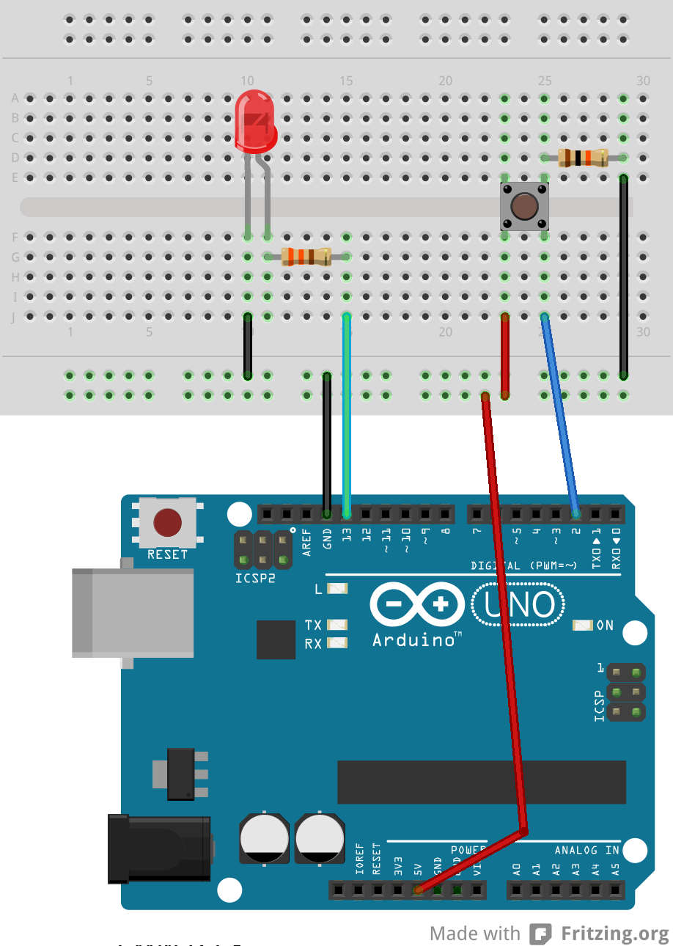
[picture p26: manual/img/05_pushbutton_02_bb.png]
   \ \ 
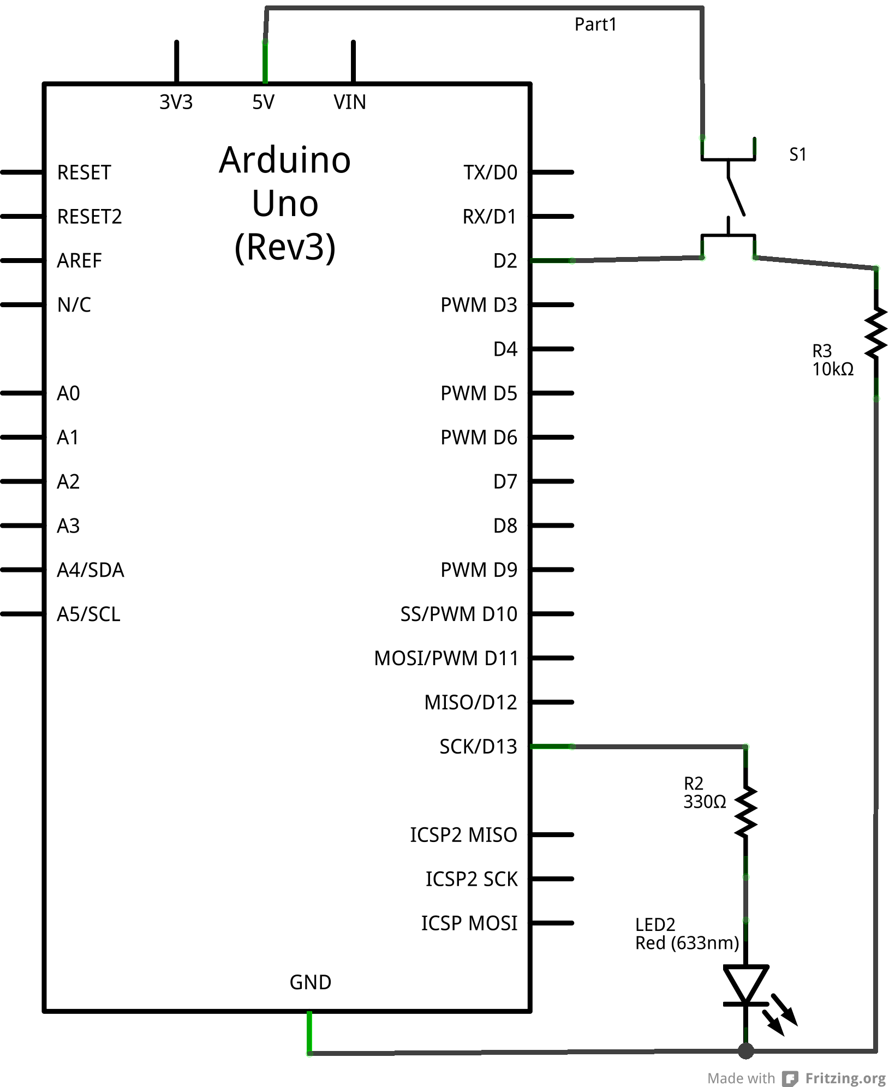
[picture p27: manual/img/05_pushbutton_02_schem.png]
  
\caption{\engt{Reading the state of a pushbutton to control a LEDs state.}
\nedt{De status van een drukknop lezen om de staat van een LED te beheren.}}
\label{f:lesson5_pbtn2}       % Give a unique label
\end{figure}

\eng{Let's analyse this circuit. The pin to read the state of the button is pin 2. When the button is not pressed we see that the pin is connected via black to the GND. So it will be in state GND or \ardo{LOW}. You can see there is a resistor, but this seems to have no function.

Now consider the button pressed. There is a connection now from left to right in the pushbutton. So black (GND) is connected to red which goes so 5V on the Arduino. If there would be no resistor we would have a short-circuit: current running freely from 5V to GND. So, we \textbf{need} a resistor to avoid a short-circuit! What resistor do we need? Well, we want to have at pin 2, 5V when the button is pushed down, \textbf{and} we don't want to spend a lot of current to achieve this state. Hence, we want a large resistor! A large resistor will make sure the resistance from the wires from the pushbutton to the 5V pin is neglectable compared to the large resistor, so pin 2 will be on 5V. At the same time, a large resistor will make sure very little current will actually flow over the pushbutton, so our circuit will be very efficient. So, take for this resistor 10000$\Omega$ which we write as 10K$\Omega$ or 10k$\Omega$. We call such a resistor used in this way a pull-down or pull-up resistor.

We can now write Arduino code that reads the state of pin 2, and let's the LED shine based on this. To achieve this, our LED circuit of the previous excercise must be changed to draw current from a pin, eg pin 13. Like that, setting pin 13 HIGH or LOW will control the LED. Note that most Arduino boards have a tiny LED connected to pin 13 on the board, so you could use that instead of a real LED. The code is given in Code
\ref{c:pbtn}.

Note that our circuit works exactly as the one in the previous excercise: the LED shines when the button is pressed. How we achieve this is completely different though.
}
\ned{Laat ons dit circuit analyseren. De pin om de status van de knop te lezen is pin 2. Als deze knop niet is ingedrukt zien we dat de pin verbonden is via zwart met de GND. Het zal dus in de GND staat of \ardo{LOW} zijn. Je ziet dat er een weerstand is, maar deze lijkt geen functie te hebben.

Beschouw nu het geval dat de knop ingedrukt is. Er is nu een connectie van links naar rechts in de drukknop. Zwart (GND) is dus verbonden met rood die naar de 5V op de Arduino gaat. Moest er geen weerstand zijn dan zouden we een kortsluiting krijgen: stroom die vrij stroomt van 5V naar GND. Aldus \textbf{moeten} we een weerstand hebben om kortsluiting te voorkomen. Welke weerstand hebben we nodig? Wel, we willen dat pin 2 op 5V staat als de knop ingedrukt is, \textbf{\'en} we willen niet veel stroom gebruiken om dit te verkrijgen. Bijgevolg willen we een grote weerstand! 
Een grote weerstand zal zorgen dat de weerstand in de draden van de drukknop naar de 5V pin verwaarloosbaar is ten opzichte van de grote weerstand, en dus zal pin 2 op 5V staan. Terzelfdertijd zal een grote weerstand ervoor zorgen dat er maar heel weinig stroom zal vloeien over de drukknop, en ons circuit zal dus heel efficient zijn. Neem daarom als weerstand eentje van 10000$\Omega$, welke we ook schrijven als 10K$\Omega$ of 10k$\Omega$. We noemen zo'n weerstand op deze manier gebruikt een \textit{pull-down} (naar GND) of \textit{pull-up} (naar 5V) weerstand.

We kunnen nu Arduino code schrijven die de status van pin 2 leest, en de LED laten schijnen op basis van die status. Om dit te doen dient ons LED circuit van de vorige oefening aangepast te worden om stroom te trekken van een pin, bv pin 13. Zo kunnen we pin 13 HIGH of LOW zetten om de LED te beheren. Merk op dat de meeste Arduino borden een kleine LED op het bord hebben die verbonden is met pin 13, je zou dus dat kunnen gebruiken ipv een echte LED. De code is gegeven in Code \ref{c:pbtn}. 
}

\begin{code}\label{c:pbtn}
 \ \newline
\inputardfull{\string"../../sketches/old_versions/v01/Fe_cube_05_pbtn/Fe_cube_05_pbtn.ino\string"}
\end{code}

\subsection{\engt{Only one button?} \nedt{Maar \'e\'en knop?}}

\eng{What can we do with only one button? More than you think! Consider a touch pad on a tablet. What can you do with one finger? Consider a mouse. What can you do with one button?

Yes, the answer is: a lot! You can have a normal press, a long press, a double press. And you could even react differently to input in certain patterns (gestures). 
Reacting differently to different presses is a matter of software. The better you program, the better you can react to things happening. So, we need to think a bit on a method to program reacting to different presses.

Let's define some concepts:
\begin{itemize}
 \item \textbf{Input sampling}. We don't want to spend too much time observing what happens to the button. Testing the state of the button every 40 ms (the time of a frame in our Fe Cube) should be sufficient. It might be a good idea to not block the normal code running on our Arduino, so to let that code indicate when we are allowed to sample the input, in our case the button.
 \item An \textbf{event} is something happening to the button. There are only two events: \textit{buttonpress} and \textit{buttonrelease}. As we have seen from the previous excercise, we can recognize these events by a change in state. The first is LOW to HIGH, and the second is HIGH to LOW
 \item Next we have \textbf{event handling}. Event handling is converting events in a \textit{button press type}. To do event handling, we need to know the time since a previous event, as well as the type of a previous press type. We can distinguish like this:
\begin{enumerate}
 \item \textbf{short press}: a press and a release within 2 seconds
 \item \textbf{long press}: a press and a release taking more than 2 seconds
 \item \textbf{double press}: a short press within 0.5 seconds after a previous short press
 \item \textbf{extreme long press}: a press longer than 4 seconds. No need to wait for the release to set a press type.
\end{enumerate}
 \item An \textit{INTERRUPT}. We will have code running on our Arduino, and a button being pressed. We need to be able to interrupt the code that runs to start something else. So, our code will observe the button press type and based on that interrupt the running code to react to the press.
\end{itemize}
}

\ned{Wat kunnen we doen met maar \'e\'en knop? Meer dan je denkt! Denk aan een aanraakscherm op een tablet. Wat kun je doen met \'e\'en vinger? Denk aan de computermuis. Wat kun je doen met \'e\'en knop?

Ja, het antwoord is: veel! Je kan een normale druk hebben, een lange druk, een dubbele druk ... . Je zou zelf kunnen reageren op basis van bepaalde patronen (bv SOS in morse).
Het verschillend reageren op verschillende drukken is een kwestie van software. Hoe beter je programmeert hoe beter je kan reageren op dingen die gebeuren. We moeten dus een beetje nadenken over de methode om met een programma te reageren op een knop.

Laat ons enkele concepten defini\"eren:
\begin{itemize}
 \item \textbf{Input sampling} of \textbf{Invoertesten}. We willen niet teveel tijd besteden met het observeren wat er gebeurt met de knop. De status van de knop elke 40 ms testen (de tijd van een frame in onze Fe Cubus) zou voldoende moeten zijn. Het is misschien een goed idee om de gewone code die loopt op de Arduino niet te blokkeren, en we zouden dus die code kunnen laten aangeven wanneer we de invoer mogen testen, in ons geval de knop.
 \item Een \textbf{event} of \textbf{gebeurtenis} is iets dat gebeurt met de knop. Er zijn maar twee mogelijke events : \textit{buttonpress} and \textit{buttonrelease}, in het Nederlands: Knop indrukken en Knop loslaten. Zoals we in de vorige oefening gezien hebben kunnen we deze herkennen door een verandering in de status van de knop. De eerste is LOW naar HIGH en de tweede HIGH naar LOW.
 \item Vervolgens hebben we \textbf{event handling}. Event handling is het omzetten van events naar \textit{button press type}. Om event handling te doen moeten we de tijd weten sinds een vorig event alsook het type van de vorige druk. Op deze manier kunnen we onderscheiden:
\begin{enumerate}
 \item \textbf{short press} of \textbf{korte druk}: een druk en loslaten binnen de 2 seconden
 \item \textbf{long press} of \textbf{lange druk}: een druk en loslaten die langer dan 2 seconden duurt
 \item \textbf{double press} of \textbf{dubbele druk}: a korte druk binnen de 0.5 seconden na een vorige korte druk
 \item \textbf{extreme long press} of \textbf{extreem lange druk}: een druk die langer dan 4 seconden duurt. Het is dan niet nodig te wachten op een loslaten om het druk type vast te leggen.
\end{enumerate}
 \item Een \textit{INTERRUPT}. Dit is het Engels voor \textit{Onderbreking}. We zullen code hebben lopen op de Arduino, en een knop die gedrukt wordt. We dienen in staat te zijn de code te onderbreken om iets anders te doen. Onze code moet dus het butten press type observeren en op basis daarvan de code kunnen onderbreken om te reageren op de druk.
\end{itemize}
}

\eng{
These are a lot of concepts to include in our code. Let's create code that does different things to the LED, to see how we can do this in practice, see Code \ref{c:pbtn_event}.

This code contains in the first part a function to do inputsampling, called \ardo{inputsampling()}. This happens if the variable \ardo{allowInput} allos it. The input is then handled in the function  \ardo{eventhandling}. This function first determines the \ardo{event}, and then determiens the press type, which is saved in the variable \ardo{presstype}.

The second part of the code is the program that controls our LED. We can switch the LED on or off via a long press. A short press dims the LED a small fraction. After 15 short presses the LED will be at it's minimum brightness, with the next press going back to full brightness. We use PWM to dim the light, so we use for example pin 11. A double press will be translated in a flickering LED: half a second on, then half a second off.

This code will observe the variable \ardo{presstype}, and if it is different from \ardo{NOPRESS} do the desired action. After handling the press type, we put  \ardo{presstype=NOPRESS}, so that we again wait for the next input.

You have written your first program that allows you to control how the Arduino works!
}

\ned{Dit zijn veel concepten om op te nemen in onze code. Laat ons nu code maken die verschillende dingen doet met de LED, om te zien hoe we dit in de praktijk kunnen doen, zie Code \ref{c:pbtn_event}. 

In deze code bevat het eerste gedeelte een functie die invoertesten doet, \ardo{inputsampling()} als dit toegelaten is door de variabele \ardo{allowInput}. De invoer wordt dan verwerkt met de functie \ardo{eventhandling}. Deze functie bepaalt eerst het \ardo{event}, en daarna het type druk, welke opgeslagen wordt in de variabele \ardo{presstype}. 

Het tweede deel van de code is dan ons programma die een LED doet branden. We kunnen via een lange druk de LED aan of af doen. Een korte druk dimt de LED een kleine fractie. Na 15 keer een korte druk zal de LED maximaal gedimd zijn, om daarna weer op volle sterkte te branden. We gebruiken PWM om te dimmen, dus gebruiken we bv pin 11 voor de LED. Een dubbele druk zullen we vertalen in het flikkeren van de LED: een halve seconde aan, een halve uit. 

Deze code zal dus de variabele \ardo{presstype} observeren, en als deze verschillend is van \ardo{NOPRESS} de geweste actie ondernemen. Na het behandelen van een druktype zetten we \ardo{presstype=NOPRESS}, zodat we weer wachten op de volgende input.

Je hebt je eerste programma nu af die je toelaat te sturen hoe je Arduino werkt!
}

\begin{code}\label{c:pbtn_event}
 \ \newline
\inputardfull{\string"../../sketches/old_versions/v01/Fe_cube_05_pbtn_events/Fe_cube_05_pbtn_events.ino\string"}
\end{code}

\subsection{\engt{Fe Cube + pushbutton = control} \nedt{Fe Cube + Drukknop = sturing}}

\eng{We have our Fe Cube, and we have the circuit for pushbutton input. So it's only a matter of combining the two, and then adapting our Cube program to react to specific press input. The combined wiring is shown in Figure \ref{f:lesson5_pbtn3} for the breadboard setup. Integrate it in your Fe Cube.
}

\ned{We hebben onze Fe Kubus, en we hebben een circuit om de drukknop te gebruiken. Het is dus enkel een kwestie van beiden te combineren, en om dan ons Kubus programma aan te passen om te reageren op specifieke druk input. De gezamelijke bekabeling is te zien in  Figuur \ref{f:lesson5_pbtn3} voor het schakelbord. Integreer ze in je Fe Kubus.
}

\begin{figure}
  \centering
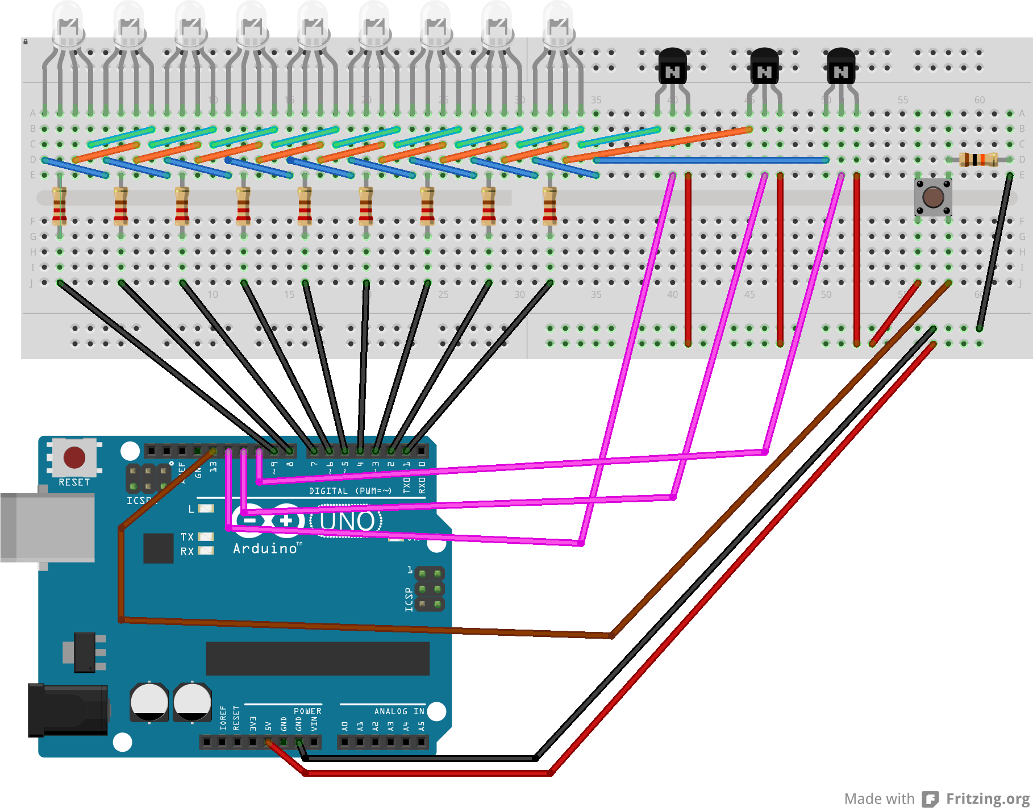
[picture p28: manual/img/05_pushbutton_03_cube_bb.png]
   \ \ 
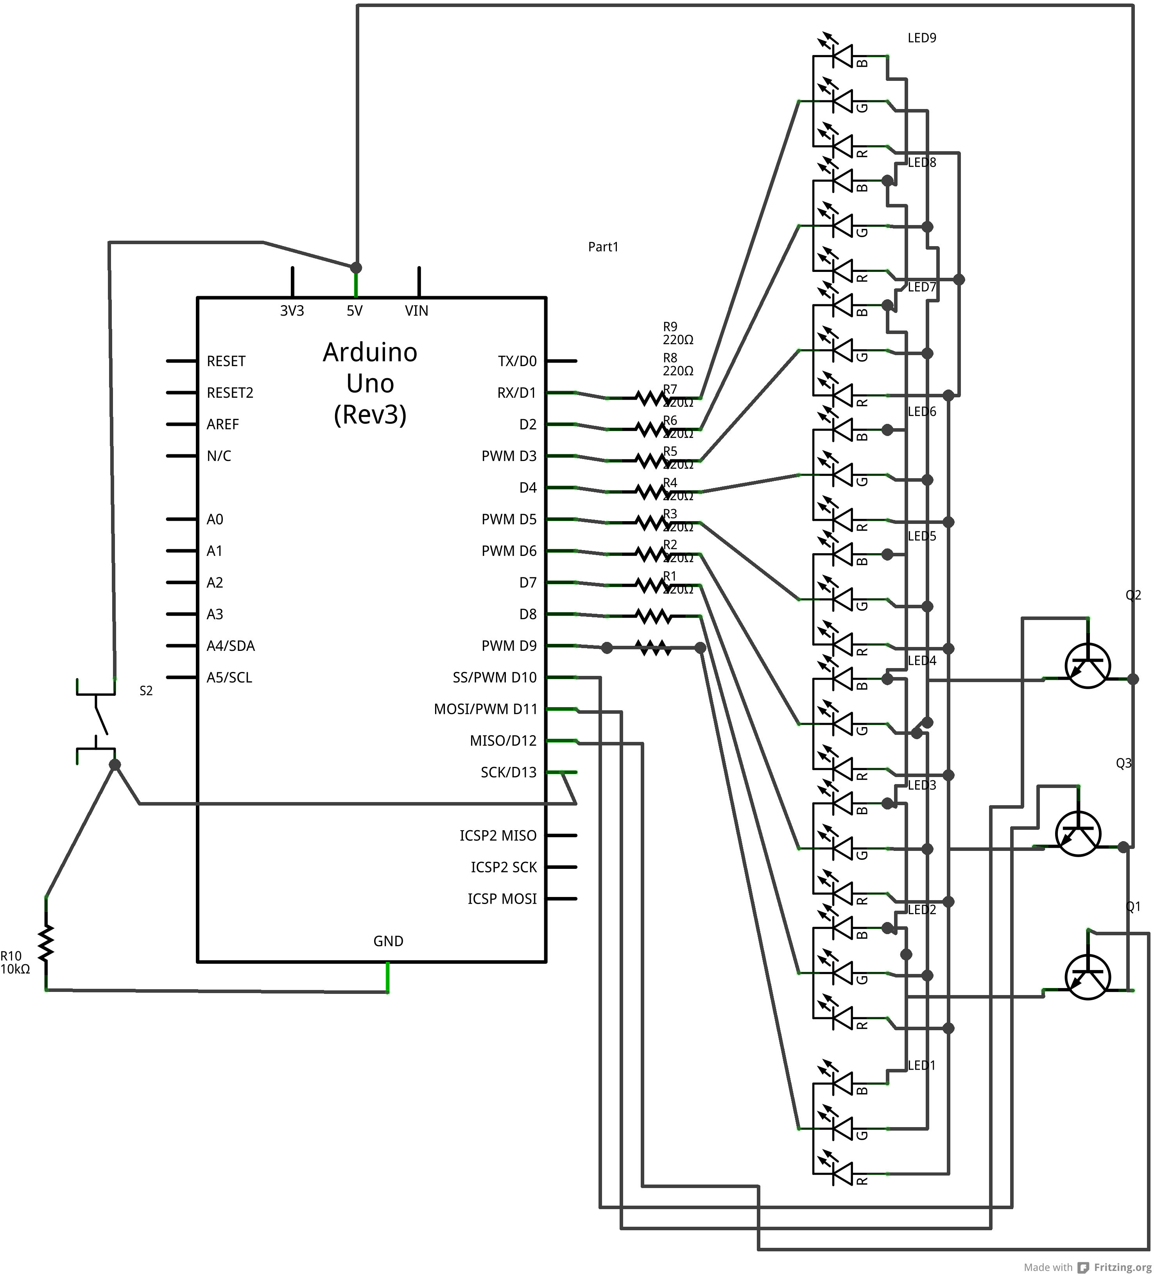
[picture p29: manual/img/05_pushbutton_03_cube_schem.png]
  
\caption{\engt{The same pushbutton wiring can be used with the Fe Cube as we still have
a digital pin free}
\nedt{Dezelfde drukknop bekabeling kan gebruikt worden met de Fe Kubus gezien we nog een vrije digitale pin hebben}}
\label{f:lesson5_pbtn3}
\end{figure}

\eng{For the code, we need to combine our Cube code, with the pushbutton code. The entire button handling code can be copied verbatim. In the Cube code we need to do the following changes:
\begin{itemize}
 \item We no longer update the \ardo{NRPATTERN} variable when a pattern is finished. The user will need to press the button to change the pattern.
 \item In the \ardo{loop()} function we start with the inputsampling. Next the presstype is checked. If the button press type is \ardo{NOPRESS} and the shot is not finished, no new shot will be started. In all other cases we handle the press type. We will do the following: if a shortpress, we increase \ardo{NRPATTERN}, so as to move to the next pattern. If \ardo{EXTREMEPRESS} we will switch the cube off or on. If \ardo{DOUBLEPRESS} we will show a new effect: rolling 3 dices.
 \item We write new shots: one to switch off the cube, and one for dice rolling
 \item We update the \ardo{movie} function: if we need to show the dice effect or switch off the LED, we return those shots. Otherwise we do as before: return the correct pattern.
\end{itemize}
The full code is in \url{https://github.com/ingegno/fecube/blob/master/sketches/old_versions/v01/Fe_cube_05_cube_pbtn/Fe_cube_05_cube_pbtn.ino}.
}

\ned{In de code dienen we de kubus code te combineren met de drukknop code. De volledige drukknop logica kan letterlijk overgenomen worden. In de oorspronkelijke kubus code moeten we wel nog volgende wijzigingen doen:
\begin{itemize}
 \item We passen de variabele \ardo{NRPATTERN} niet langer aan als het patroon af is. De gebruiker zal moeten de knop drukken om een ander effect te zien.
 \item In de \ardo{loop()} functie beginnen we met invoerlezing via de \ardo{inputsampling} functie. Vervolgens controleren we het presstype. Als de drukknop type \ardo{NOPRESS} is en het shot niet gedaan, zal er geen nieuw shot started. In alle andere gevallen moeten we het drukknop type behandelen. We zullen het volgende doen: bij een korte druk zullen we \ardo{NRPATTERN} verhogen, opdat een nieuw patroon zou getoond worden.  Indien het type \ardo{EXTREMEPRESS} is zullen we de kubus af- of aanzetten. Bij \ardo{DOUBLEPRESS} zullen we een nieuw effect tonen: 3 dobbelstenen gooien.
 \item We schrijven nieuwe shots: een om te kubus af te zetten, en een om de dobbelsteen te tonen
 \item We passen de \ardo{movie} functie aan: Als we de dobbelsteen moeten tonen of de LED moeten uitzetten, geven we die shots terug. Anders doen we zoals vroeger: het juiste patroon teruggeven.
\end{itemize}
De volledige code kun je vinden op 
\url{https://github.com/ingegno/fecube/blob/master/sketches/old_versions/v01/Fe_cube_05_cube_pbtn/Fe_cube_05_cube_pbtn.ino}.
}

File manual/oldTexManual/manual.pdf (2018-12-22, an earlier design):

## Fe Cube: Maak het! Versta het!

Ingegno Team: M.C. Ciocci, B. Malengier

December 22, 2018

## 1 Introductie

In dit boekje zullen we je leren hoe je de Fe Cube kunt maken. Je zal leren over LEDs, de Arduino, multiplexing, solderen, kleurentheorie, en meer! Je kan een kit kopen met alle onderdelen van Ingegno.be, of je kan je eigen stukken gebruiken.
De code van deze handleiding kan gevonden worden op de Ingegno github pagina. (https://github.com/ingegno/linefollower1)

### 1.1 De componenten

We zullen volgende componenten gebruiken:

1. Een schakelbord (Breadboard)
2. 9 RGB-LED + 3 extra (we veronderstellen gemeenschappelijke kathode voor de kubus)
3. 1 grote RGB-LED (we veronderstellen gemeenschappelijke anode)
4. 3 NPN + 1 extra (2N3904 of gelijkaardig)
5. 1 drukknop
6. 9 220 Ω weerstanden + 3 extra
7. 1 10k-20kΩ oftewel 10000-20000Ω weerstand
8. veel draden
9. lasercut basis voor de kubus
10. ijzerdraad pilaren voor de kubus
11. soldering plaat voor vaste componenten + connectiestukken

Je zal ook een soldeerijzer nodig hebben, en optioneel kun je een afdekking maken voor de kubus, bv via 3D printen of in plexi met de lasercutter.
Voor een overzicht van de betekenis van de componenten, zie het overzicht die je apart gekregen hebt.

### 1.2 Arduino

We zullen intensief gebruik maken van Arduino, dus moet je de Arduino software (http://Arduino.cc) installeren op je laptop. Eenmaal geinstalleerd kun je nu je Arduino bord koppelen aan je computer via de usb poort. In de programmeeromgeving van Arduino kun je programma’s schrijven en die opladen naar de Arduino, waar ze dan uitgevoerd worden zolang er stroom is.

1

### 1.3 Programmeren met Arduino

Een programmeertaal moet verstaan worden door een computer. Spijtig genoeg zijn computers nog altijd een beetje dom, dus mag je geen enkele fout maken! Het is zoals een dictee waar je altijd 10/10 moet halen. Neem dus de tijd om de structuur en taal van de Arduino te leren. Zie de blaadjes ’Programmeren met Arduino’ die je bij deze gids kan downloaden.

## 2 Les 1: E´en LED circuit ´

We maken een circuit met ´e´en enkele LED, welke we zullen programmeren om te pinken. De Arduino levert 5 Volt, terwijl de LED gemaakt is voor 3 Volt. We moeten dus een weerstand gebruiken om het voltage over de LED te verminderen. Je kan de weerstand die je nodig hebt berekenen met http://led.linear1.org/1led.wiz.

### 2.1 E´en pin ´

Maak het circuit zoals gegeven in Fig. ??. Gebruik je schakelbord en draden om de connecties te maken. Dus hier, een draad van pin 2 naar rij 10 op je schakelbord. Dan de resistor met weerstand R=330 Ω van rij 10 naar rij 6, de LED anode van rij 6 naar rij 5, en uiteindelijk een draad van rij 5 naar de GND pin op de Arduino.

Nu moeten we een programma schrijven dat de stroom naar pin 2 aan en af zet elke seconde, zodat de LED pinkt. Je vindt de code in Code ??.

Code 1

1 | /*
2 | Controlling a simple led via anode current interrupt
3
4 | Schematic : | GND to LED kathode ( -) , LED anode to resistor R1 ,
5 | R1 to pin led1
6 | Use correct R1 , Arduino at 5V and led of 3V will require typically R1
=220 - 500 Ohm
7 */
8
9 | // led anode (+) is connected to 2,
10 | // led kathode is connected to GND
11 | int led1 =2 ;
12
13 | // we can control the led in one way:
14 | // | 1. we can interrupt the current coming from the anode via pin led1
15
16 | void setup () | {
17 | pinMode ( led1 , OUTPUT ) ;
18 | }

2

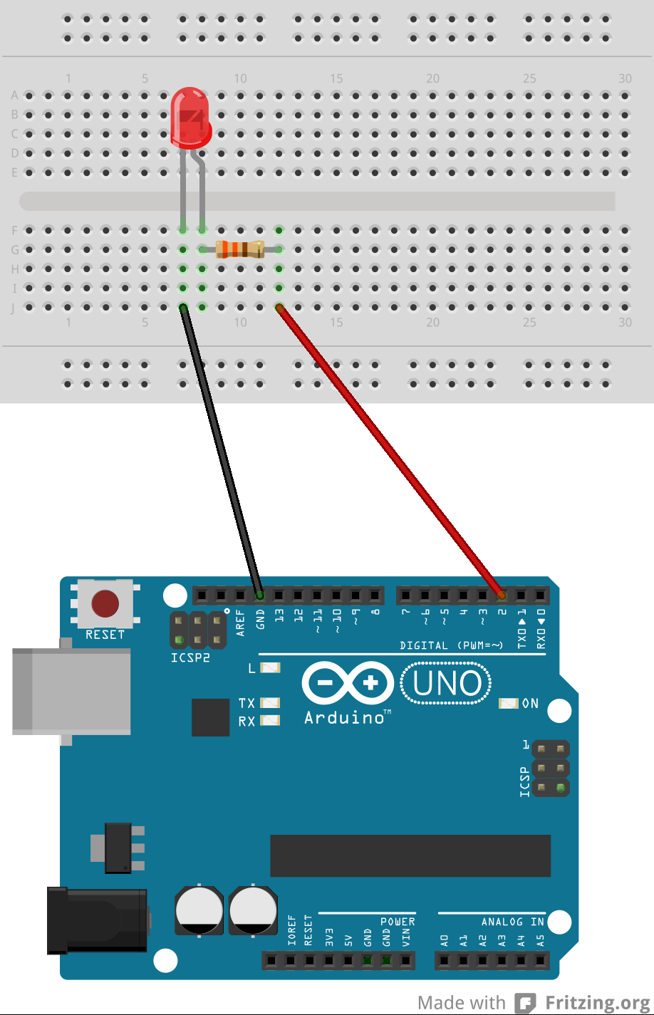
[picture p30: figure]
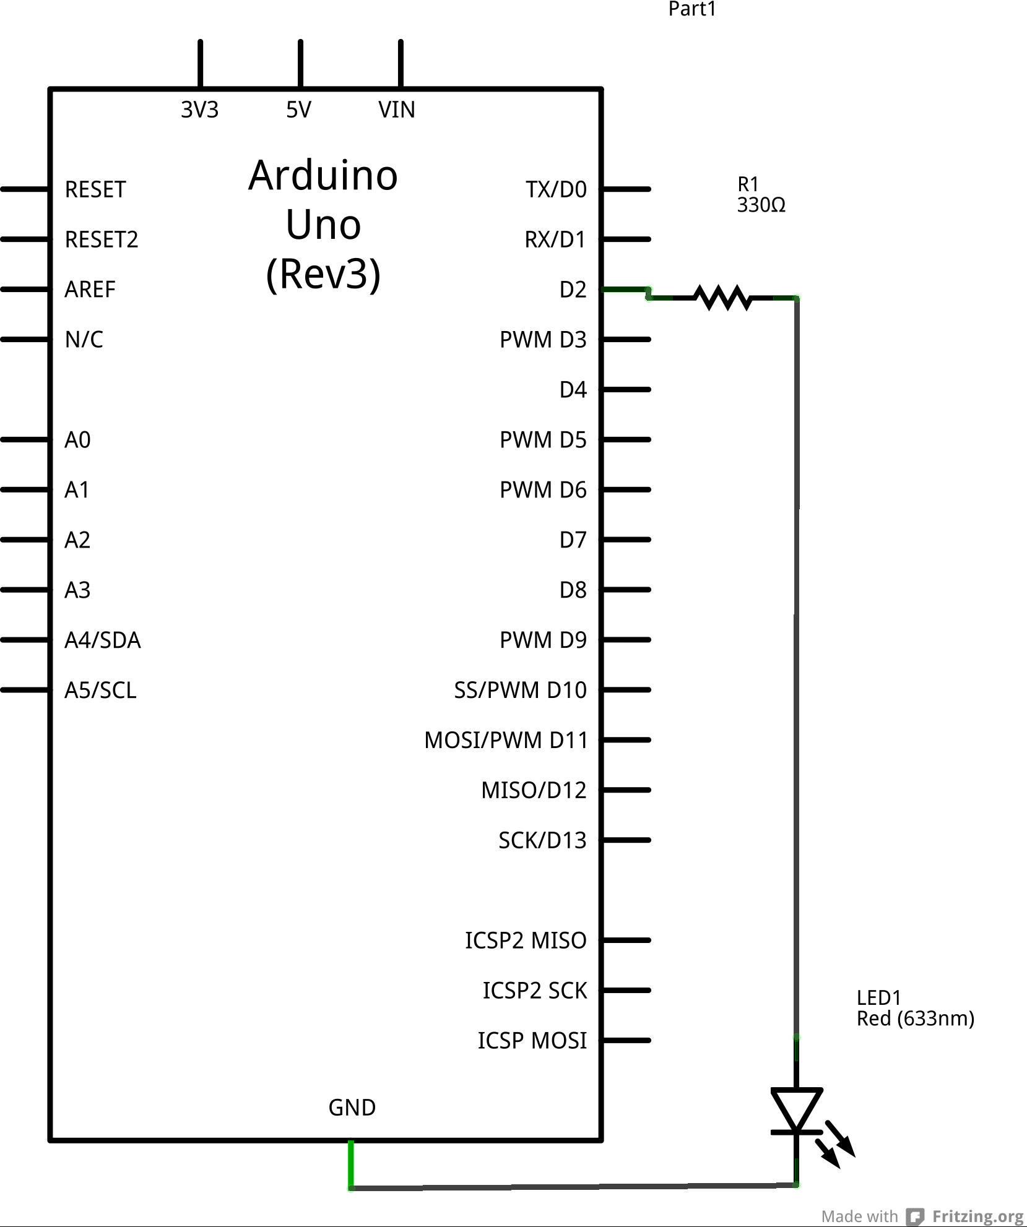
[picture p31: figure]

Figure 1: Met een pin en de grond kunnen we een LED doen branden. Links met breadboard, rechts als schema.

19
20 | void loop (){
21 | digitalWrite ( led1 , HIGH ) ; // current on
22 | delay ( 1000 ) ; | // 1 sec = 1000 millisec delay
23
24 | digitalWrite ( led1 , LOW) ; | // current off
25 | delay ( 1000 ) ;
26 | }
Proficiat, je hebt je eerste programmeer- | bare LED gemaakt.
Opdracht 1 | 1. Verander nu je programma (Code 1) zodat de LED elke 3 seconden pinkt,
met 1 seconde af.
Vervolgens, wat gebeurt er als je elke 40 milliseconden pinkt en als het elke 10 milliseconden pinkt?
2. Wat moet je doen als je twee LED’s wilt doen pinken? of afwisselend pinken? Probeer het eens.

3

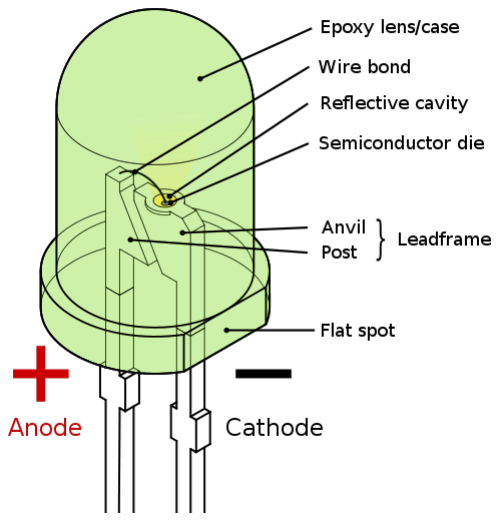
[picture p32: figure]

Figure 2: Een LED in het groot

Hoe werkt ons circuit? Wel, de pinnen van 1 tot 13 kunnen een HIGH staat en een LOW staat hebben. HIGH betekent dat de pin 5V krachtbron heeft, terwijl LOW betekent dat de pin zich in de grond staat bevindt. We zeggen dat stroom sroomt van de positieve voltage van 5V (de + zijde) naar de GND (de - zijde). dat is een beetje vervelend gezien de echte kwantumdeeltjes die hier gebruikt worden, electronen genoemd, eigenlijk de andere kant op stromen, dus van de min naar de plus. Dit omdat elektronen zelf negatief zijn, en dus afgestoten worden door de negatieve lading van de GND. Theoretisch zou je evenwel andere kwantumdeeltjes kunnen gebruiken! Hoe dan ook, de richting van de stroom, van + naar -, is gewoon een afspraak tussen wetenschappers om geen verwarring te doen ontstaan.
De krachtbron is hier 5 Volt (5V), wat een indicatie is van hoeveel werk je kan doen. Veel kracht betekent dat je veel werk kan doen! Om een LED te doen branden hebben we evenwel niet veel kracht nodig, dus beperken we die door een resistor toe te voegen die de kracht over de LED zal beperken.

Dit verhoogt de levensduur van de LED. De resistor of weerstand doet wat de
naam zegt: | het resisteert of weerstaat
de stroom. | Bijgevolg verliezen de kwan-
tumdeeltjes een deel van hun kracht als ze door een weerstand stromen. Niet alleen zullen de deeltjes minder kracht hebben erna, er zullen ook minder deeltjes passeren elke seconde. De stroom is dus verminderd. Een weerstand of resistor zal dus de stroom verminderen en na het passeren zal er ook nog eens minder kracht over zijn om door de rest van het circuit te stromen.
Daarna komt de LED voor de stroom. Alle overblijvende kracht zal gebruikt worden om door de LED te gaan en licht te genereren. Een LED maakt alleen licht als de anode (lange been, +) is geconnecteerd naar het voltage (de positieve zijde), en de kathode (korte been, -) naar de GND zijde. Als je de LED ronddraait (probeer het!) zal er geen licht schijnen. Er zal ook maar heel weinig stroom vloeien dan, gezien de LED niet enkel geen licht maakt dan maar ook de stroom sterk zal weerstaan. Een LED in het groot zie je in Figuur ??.

4

Opdracht 2 Bestudeer het schema aan de rechterkant van Figuur ??. Een schema is vaak duidelijker om mee te werken dan de draden die je aan de linkerkant ziet. Elke component heeft zijn eigen symbool. Een LED is een driehoek die eindigt op een korte vertikale lijn, en twee kleine pijlen die het licht voorstellen die de LED uitzendt. De driehoek in dit symbool kun je interpreteren als een grote pijl die de richting van de stroom aanduidt: van + naar -. Het licht verlaat de LED in dezelfde richting in het symbool.
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

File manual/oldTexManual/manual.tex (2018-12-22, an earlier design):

\documentclass[11pt,a4paper]{article}
\usepackage{a4wide}
%\usepackage[utf8]{inputenc}

%\usepackage[english,dutch]{babel}
% better color management than parallel:
\usepackage{pdfcolparallel}

\setlength{\columnsep}{0.5cm}

%\usepackage{parallel}
\usepackage{color}
\usepackage{amsmath}
\usepackage{graphicx}

\usepackage{inconsolata} %a different monofont, texlive-fonts-extra needed!

\usepackage{arduinohighlight}

\usepackage{xcolor} 
\usepackage{framed}
\colorlet{shadecolor}{gray!50}

\usepackage[
      %dvipdfm,    %put here the correct(!) driver you are using
      pdftex,
      unicode,
      colorlinks=true,    %no frame around URL
      urlcolor=blue,    %blue color
      menucolor=black,    %no colors
      linkcolor=blue,    %blue color
      bookmarks=true,    %tree-like TOC
      bookmarksopen=true,    %expanded when starting
      hyperfootnotes=false,    %no referencing of footnotes, does not compile
      pdfpagemode=UseOutlines,    %show the bookmarks when starting the pdf viewer
      pdfauthor={Ingegno.be},
      pdftitle={Fe Cube - Ingegno.be},
]{hyperref}

\newtheorem{opdrE}{Task} 
\newenvironment{doE}
  {\begin{shaded}\begin{opdrE}}
  {\end{opdrE}\end{shaded}}

\newtheorem{opdrN}{Opdracht} 
\newenvironment{doN}
  {\begin{shaded}\begin{opdrN}}
  {\end{opdrN}\end{shaded}}
\newtheorem{code}{Code} 

%% First to \eng, then \ned, closes automatically with a paragraph
% \newcommand{\eng}[1]{\selectlanguage{english} \ParallelLText{#1}}
% \newcommand{\ned}[1]{\selectlanguage{dutch} \ParallelRText{#1} \ParallelPar}
% \newcommand{\engt}[1]{{#1} - }
% \newcommand{\nedt}[1]{{#1}}
% \newcommand{\engo}[1]{\eng {#1}}
% \newcommand{\nedo}[1]{\ned {#1}}

%% Use following for book in English language
% \usepackage{multicol}
% %\newcommand{\eng}[1]{\selectlanguage{english} {#1}}
% \newcommand{\eng}[1]{\begin{multicols}{2}{\selectlanguage{english} {#1}}\end{multicols} \hrule}
% \newcommand{\ned}[1]{ }
% \newcommand{\engt}[1]{{#1}}
% \newcommand{\nedt}[1]{ }
% \newcommand{\nedo}[1]{ }
% \newcommand{\engo}[1]{\selectlanguage{english} {#1}}

%% Use following for book in Dutch language
\usepackage{multicol}
%\newcommand{\ned}[1]{\selectlanguage{dutch} {#1}}
%\newcommand{\ned}[1]{\begin{multicols}{2}{\selectlanguage{dutch} {#1}}\end{multicols} \hrule}
\newcommand{\ned}[1]{\begin{multicols}{2}{ {#1}}\end{multicols} \hrule}
\newcommand{\eng}[1]{ }
\newcommand{\nedt}[1]{{#1}}
\newcommand{\engt}[1]{ }
\newcommand{\engo}[1]{ }
%\newcommand{\nedo}[1]{\selectlanguage{dutch} {#1}}
\newcommand{\nedo}[1]{ {#1}}
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

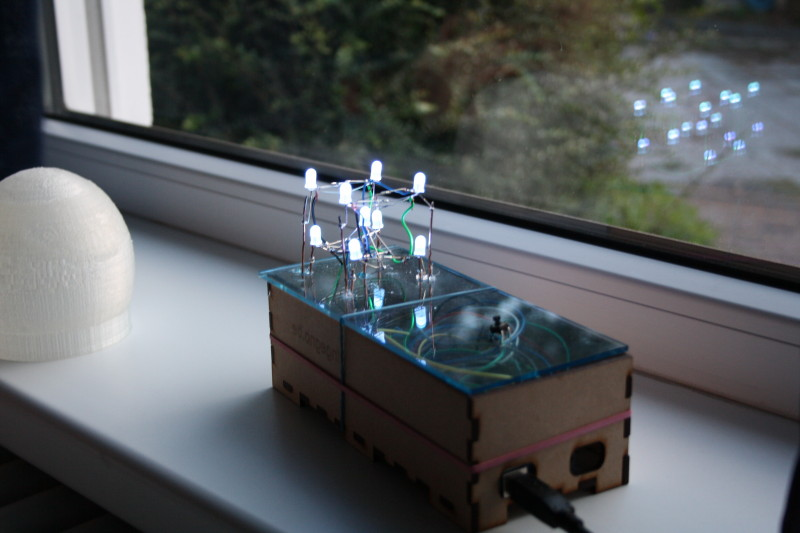
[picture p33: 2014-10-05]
manual/pic/prototype03_c.png

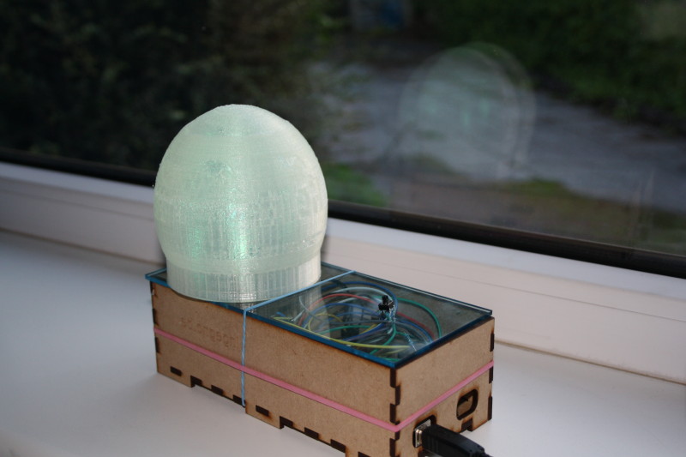
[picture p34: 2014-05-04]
manual/pic/prototype03_a.JPG

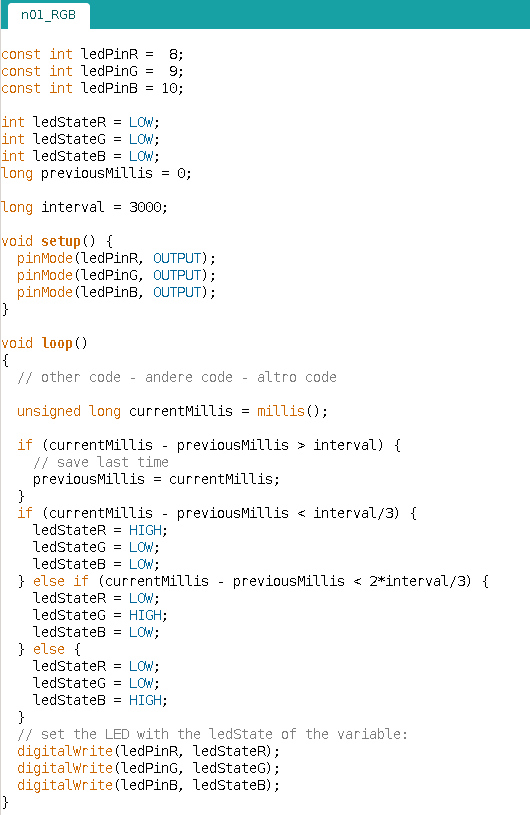
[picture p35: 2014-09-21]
manual/img/code_01.png

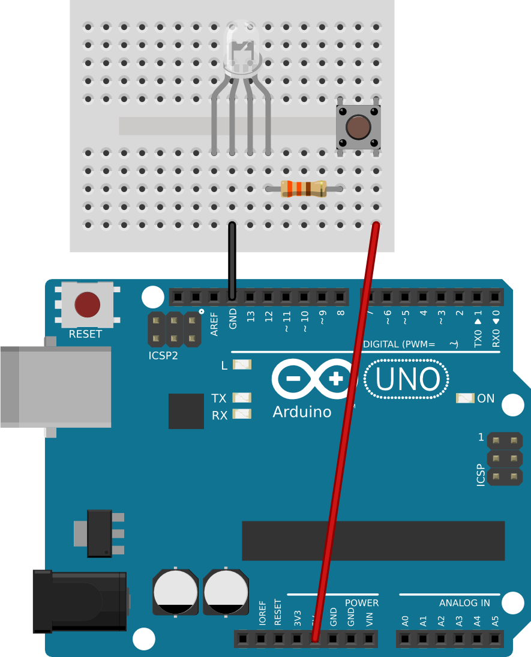
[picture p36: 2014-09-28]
manual/img/n06_pushbuttontest_bb.png

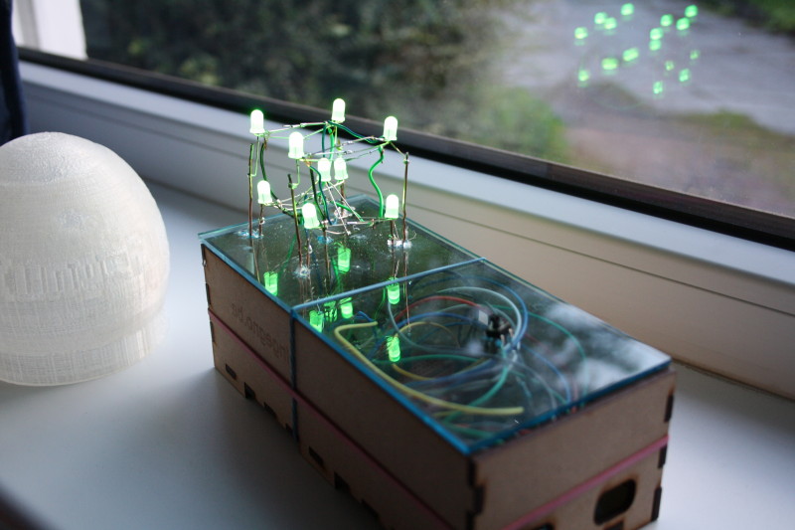
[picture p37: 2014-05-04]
manual/pic/prototype03_b.JPG

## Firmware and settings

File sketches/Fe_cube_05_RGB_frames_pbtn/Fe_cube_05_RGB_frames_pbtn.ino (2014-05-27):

/*
Controlling an RGB led via an npn switch and digital switching
using a frame abstraction
*/

// pins used
int ledR=11;
int ledG=10;
int ledB=9;
int led1=2;

#define btnpin  3  //de pin die pushbutton leest

bool test = false;  //use serial monitor for testing.

int NRSHOT = 0;    //shot number to start with
int PREVSHOT = 0;
int MAXSHOT = 3;   //maximum shot number

/*************************************************/
/*       variables for input sampling            */
/*************************************************/
bool allowInput  = true;
int btnStatePrev = LOW;
int btnState     = LOW;

// events
#define BTNFIXED     0    //no change
#define BTNPRESS     1
#define BTNRELEASE   2
unsigned long timepressed  = 0;
unsigned long timereleased = 0;
// button press types
#define NOPRESS      0
#define SHORTPRESS   1
#define LONGPRESS    2
#define DOUBLEPRESS  3
#define EXTREMEPRESS 4

int presstypePrev = NOPRESS;
int presstype     = NOPRESS;
unsigned long prevpresstime = 0;

//sensitivity constants
#define SHORTPRESSMAXDURATION 2000UL
#define LONGPRESSMAXDURATION  4000UL   // 4 seconds
#define DOUBLEPRESSWAIT       500UL    //half a second!

/*************************************************/
/*       Setup code                              */
/*************************************************/
void setup() {
  if (test) {
    Serial.begin(9600);
  }
  randomSeed(analogRead(0));
  // define the pins we use for the RGB led
  pinMode(ledR,OUTPUT); pinMode(ledG,OUTPUT);
  pinMode(ledB,OUTPUT); pinMode(led1,OUTPUT);
  // initialize the pushbutton pin as an input:
  pinMode(btnpin, INPUT);
}


/*************************************************/
/*       Input sampling code                     */
/*************************************************/

void inputsampling(){
  //read the pushbutton if allowed
  if (allowInput) {
    if (presstype == NOPRESS) {
      btnStatePrev = btnState;
      btnState = digitalRead(btnpin);
      // handle the events if needed
      eventhandling();
    } else {
      // problem, the previous press type has not been handled yet!
      // note: in our design a SHORTPRESS will be handled even it 
      //       later we change this into a DOUBLEPRESS !
      //if 5 seconds a press is not handled, we remove it
      if (millis()-prevpresstime > LONGPRESSMAXDURATION){
        presstype = NOPRESS;
        presstypePrev  = NOPRESS;
      }
    }
    allowInput = false;
  }
}

void  eventhandling(){
  // process the events to set button press types
  unsigned long currt = millis();
  unsigned long prevtimereleased;
  int event = BTNFIXED;
  if (btnStatePrev != btnState) {
    // an event happened, handle it
    if (btnState == HIGH){
      event = BTNPRESS;
      timepressed = currt;
    } else {
      event = BTNRELEASE;
      prevtimereleased = timereleased;
      timereleased = currt;
    }
  }
  switch (event) {
    case BTNFIXED:
      // if no event, we can have a long press or certain short press
      if (timereleased > 0 && timepressed > timereleased
          && currt - timepressed > LONGPRESSMAXDURATION){
        presstype = EXTREMEPRESS;
        presstypePrev = NOPRESS;
        //avoid double handling of same events
        timepressed = timereleased;
      } else if (timereleased > 0 && presstypePrev == SHORTPRESS 
                  && currt - timereleased > DOUBLEPRESSWAIT){
        presstype = SHORTPRESS;
        presstypePrev = NOPRESS;
      } 
      break;
    case BTNPRESS:
      // button is pressed in, we don't sent a press type for this
      break;
    case BTNRELEASE:
      // button is released, set press type
      if (timereleased - timepressed <= SHORTPRESSMAXDURATION){
        //a short press
        if (presstypePrev == SHORTPRESS 
            && (timepressed - prevtimereleased) < DOUBLEPRESSWAIT) {
          //a double press
          presstype = DOUBLEPRESS;
          presstypePrev = NOPRESS;
        } else {
          //a normal short press, store, will be handled if no double press
          presstype = NOPRESS;
          //remember it in case it will be double press:
          presstypePrev = SHORTPRESS;
        }
      } else if (timereleased - timepressed <= LONGPRESSMAXDURATION){
        // a long press
        presstype = LONGPRESS;
      } // no need for extremelong test, BTNFIXED handles it
  }
  if (test){// && event != BTNFIXED){
    Serial.print(presstype);Serial.print(" ");
    Serial.println(timepressed - prevtimereleased);
    delay(100);
  }
  // presstype has been set. The app should process it and set it to NOPRESS
}

/***************************************************************************
We consider the effect (a random color for 1 second) to be a shot or action.
A shot consists of frames which are shown 40ms. We determe in the loop if
a new frame must be drawn.

General outline animation architecture 

1. A movie is a sequence of shots.
2. A shot has a duration expressed in ms. The action will be split up in 
   frames to give the illusion of smooth change. 
2. A frame is a fixed pattern that repeats for 1/25 of a second. The human
   eye can only see 24 images per second, so one frame every 1/25 seconds
   can give the illusion of smooth movement/change
   Frames themself are drawn from subframes
3. To create a frame, multiplexing will be needed. This is the act of
   combining individual light outputs to create a single frame.
   Eg, an RGB led cannot show R, G and B at the same time, so these must be
   shown in serie. For the same reason, a led cube might not have to power
   output to drive a complete cube in one subframe. So a subframe is one 
   output of a loop in arduino.  A cycle of subrames creates a frame. 
   The cycle is repeated for the duration of the frame.
***************************************************************************/
unsigned long movietime = 0UL;
//our first shot: a random color for a specific duration
long random_colorR = 0;
long random_colorG = 0;
long random_colorB = 0; // global variables

void random_color(unsigned long framenr, int frame[3]){
  //update the frame for the time shown
  if (framenr == 0) {
    //determine the random color we will use
   random_colorR = int(random(65));
   random_colorG = int(random(65));
   random_colorB = int(random(65));
   if (test) {
     Serial.print("New random color:");
     Serial.print(random_colorR * 4);Serial.print(" ");
     Serial.print(random_colorG * 4);Serial.print(" ");
     Serial.print(random_colorB * 4);Serial.print(" at time ");
     Serial.println(millis()/1000.);
   }
  }
  //store the random color in the frame
  frame[0] = random_colorR;
  frame[1] = random_colorG;
  frame[2] = random_colorB;
  //to test: hard code colors here:
  //frame[0] = 0; frame[1] = 0; frame[2] = 64;
}


void blink_color(unsigned long framenr, int frame[3]){
  //update the frame for the time shown
  if (framenr <25 ) {
    frame[0] = 64;
    frame[1] = 0;
    frame[2] = 64;
  } else {
    frame[0] = 0;
    frame[1] = 0;
    frame[2] = 0;
  }
}

//convert framenr to milliseconds
unsigned long framenr2ms(unsigned long framenr){
  return framenr  * 40;  //40ms per frame
}

int rainbowsinglecolorduration = 20;  //in milliseconds!
unsigned long rainbowshotduration = 255*rainbowsinglecolorduration;
void rainbow(unsigned long framenr, int frame[3]){
  //we show a rainbow effect, every color one second, 255 colors! 
  
  //determine color number that corresponds with the framenr, so which second?
  int color = framenr2ms(framenr) / rainbowsinglecolorduration;
  //in case color is too large, use modulo to put it in interval (0,255)
  color = color % 256;
  
  //we determine a color in the color wheel, number in (0,255) rescaled to (0,64) via /4
  if(color < 85) {
    frame[0] = int(color*3/4); 
    frame[1] = int((255-color*3)/4); 
    frame[2] = 0;
  } else if(color < 170) {
    color -= 85;
    frame[2] = int(color*3/4); 
    frame[0] = int((255-color*3)/4); 
    frame[1] = 0;
  } else {
    color -= 170;
    frame[1] = int(color*3/4); 
    frame[2] = int((255-color*3)/4); 
    frame[0] = 0;
  }
}

void switch_off(unsigned long framenr, int frame[3]){
  //shot: switch off, allow inputsampling to continue
  frame[0] = 0;
  frame[1] = 0;
  frame[2] = 0;
  // too avoid too much cycling we switch off, and delay somewhat
  delay(35);
}

void (*movie(unsigned long *shotduration))(unsigned long, int[3]){
  // when a shot is finished, movie() is called to obtain the next shot.
  
  //first check for possible special shots
  switch (NRSHOT) {
    case 9999:
      //switch off
      *shotduration=1000;
      return switch_off;
      break;
  }
  
  //handle the normal shots:
  if (NRSHOT >= MAXSHOT) {NRSHOT = 0;}
  switch (NRSHOT) {
    case 0:
      // Here we have a single random color, and a fixed duration of 1000 ms.
      *shotduration = 1000UL;
      return random_color;
      break;
    case 1:
      //blink is 2 seconds for one cycle of the shot
      *shotduration = 2000UL;
      return blink_color;
      break;
    case 2:
      //rainbow effect
      *shotduration = rainbowshotduration;
      return rainbow;
    default:
      //we should not get here, if we are here, we switch off
      return switch_off;
  }
  // Here we have a single random color, and a fixed duration of 1000 ms.
  *shotduration = 1000;
  return random_color;
}


/***************************************************************************
           THAT WAS IT! SHORT NO?
           
       THE REST IS THE GENERAL FRAMEWORK TO SHOW FRAMES ACCORDING TO
            WHAT YOU WANTED

***************************************************************************/
//global variables needed
unsigned long startTime = 0UL;
unsigned long currentTime;
unsigned long shotduration = 0UL;
//shotptr       curshot;
void (*curshot)(long unsigned int, int*);
int           curframe[3];
unsigned long framenr = 0UL;
unsigned long curframenr = 1UL;
boolean       newframe = true;
unsigned long starttimeframe = 0UL;
int           subframecolor;
unsigned long subframecycle, cursubframecycle;
unsigned long subframestarttime;
unsigned long curmicrotime;

void loop(){
  //do input sampling 
  inputsampling();
  //first we determine if a new shot must start or not
  currentTime = millis();
  bool newshot = true;
  switch (presstype) {
    case NOPRESS:
      //verder doen met huidige shot, of het herstarten als einde bereikt
      if (currentTime - startTime < shotduration) {
        //no new shot yet
        newshot = false;
        }
      break;
    case SHORTPRESS:
      //increase the pattern number to show new pattern
      NRSHOT += 1;
      break;
    case EXTREMEPRESS:
      //switch on or off
      if (NRSHOT == 9999) {
        NRSHOT = PREVSHOT;  //back on
        if (NRSHOT == 9999){NRSHOT = 0;}
      } else {
        PREVSHOT = NRSHOT;
        NRSHOT = 9999; //off
      }
      break;
    case DOUBLEPRESS:
      //no function for this
      newshot = false;
      break;
    default:
      newshot = false;
  }
  //consider presstype handled:
  presstype = NOPRESS;
  if (newshot) {
    //a new shot
    startTime = millis();
    curshot = movie(&shotduration);
    currentTime = startTime;
    curframenr = 1000UL; //dummy value
  }
  //we obtain the framenumber we should show, one frame=40ms
  unsigned long framenr = (currentTime - startTime)/40UL;
  if (curframenr != framenr){
    //a new frame to show, obtain it
    curshot(framenr, curframe);
    newframe = true;
    starttimeframe = micros();
    curframenr = framenr;
  } else {
    newframe = false;
  }
  // we continue showing a cycle of subframes as needed for the current frame
  curmicrotime = micros();
  if (newframe) {
    //allow input on next sampling
    allowInput = true;
    //reinit the subframes
    subframecolor = 0;
    subframestarttime = curmicrotime;
    subframecycle = 0UL;;
    cursubframecycle = 0UL;
  } else {
    // determine if a new subframecolor is needed
    cursubframecycle = (curmicrotime - starttimeframe) / 960UL; //960=3*5*64
    if (cursubframecycle != subframecycle){
      //new subframecycle
      subframecycle = cursubframecycle;
      subframestarttime = curmicrotime;
      subframecolor = 0;
    } else {
      subframecolor = subframecolor + 1;
      subframecolor = subframecolor % 3;
    }
  }
  //we know the frame, the color, and how far in the subframe we are
  show_subframe_color(subframecolor, curmicrotime - subframestarttime);
}

void show_subframe_color(int color, long microtime){
  // all off
  digitalWrite(led1, HIGH);
  digitalWrite(ledR, LOW);
  digitalWrite(ledG, LOW);
  digitalWrite(ledB, LOW);
  if (color == 0) {
    if (microtime < 15 * curframe[0]) {
      digitalWrite(ledR, HIGH);
    }
  } else if (color == 1) {
    if (microtime < 15 * curframe[1]) {
      digitalWrite(ledG, HIGH);
    }
  } else {
    if (microtime < 15 * curframe[2]) {
      digitalWrite(ledB, HIGH);
    }
  }
}
 

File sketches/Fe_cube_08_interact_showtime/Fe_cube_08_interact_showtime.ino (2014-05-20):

/*
Controlling a FE Cube - intelligent patterns
*/
#define __PROG_TYPES_COMPAT__   // define needed for older arduino avr !
#include <avr/pgmspace.h> // allows use of PROGMEM to store patterns in flash

// pins used, avoid use of memory to store it:
#define ledR 10
#define ledG 11
#define ledB 12
// led anodes are connected to pins via a resistor
// Bottom/Top - Left/Right - Aft/Front
#define ledBLA 1
#define ledTLA 4
#define ledBLF 3
#define ledTLF 2
#define ledMID 5
#define ledTRF 8
#define ledBRA 7
#define ledTRA 6
#define ledBRF 9
// pushbutton pin
#define btnpin 13
//distance sensor Trig and Echo
#define trigPin A0
#define echoPin A1

const int ledorder[] = {ledTLF,   ledTLA,   ledTRF,   ledTRA,   ledBLF,   ledBLA,   ledBRF,   ledBRA,   ledMID};
const int colorder[] = {ledR, ledG, ledB};

//time state of the loop
unsigned long currentTime_mus = 0UL;
unsigned long currentTime;

/*************************************************/
/*       Pattern for Fe Cube                     */
/*************************************************/

const PROGMEM prog_int16_t PatternSnake[] = {
//a color based snake order led: color + brightness as points
//ledTLF,   ledTLA,   ledTRF,   ledTRA,   ledBLF,   ledBLA,   ledBRF,   ledBRA,   ledMID,  duration
//snake with color 1 then 2
 0, 0,  0, 0,  0, 0,  0, 0,  0, 0,  1,10,  0, 0,  0, 0,  0, 0,  1000,
 0, 0,  0, 0,  0, 0,  0, 0,  0, 0,  0, 0,  0, 0,  1,10,  0, 0,  1000,
 0, 0,  0, 0,  0, 0,  0, 0,  0, 0,  0, 0,  1,10,  0, 0,  0, 0,  1000,
 0, 0,  0, 0,  0, 0,  0, 0,  1,10,  0, 0,  0, 0,  0, 0,  0, 0,  1000,
 0, 0,  0, 0,  0, 0,  0, 0,  0, 0,  0, 0,  0, 0,  0, 0,  1,10,  1000,
 0, 0,  1,10,  0, 0,  0, 0,  0, 0,  0, 0,  0, 0,  0, 0,  0, 0,  1000,
 0, 0,  0, 0,  0, 0,  1,10,  0, 0,  0, 0,  0, 0,  0, 0,  0, 0,  1000,
 0, 0,  0, 0,  1,10,  0, 0,  0, 0,  0, 0,  0, 0,  0, 0,  0, 0,  1000,
 1,10,  0, 0,  0, 0,  0, 0,  0, 0,  0, 0,  0, 0,  0, 0,  0, 0,  1000,
 0, 0,  0, 0,  0, 0,  0, 0,  0, 0,  0, 0,  0, 0,  0, 0,  1,10,  1000,
 //now color 2
 0, 0,  0, 0,  0, 0,  0, 0,  0, 0,  2,10,  0, 0,  0, 0,  0, 0,  1000,
 0, 0,  0, 0,  0, 0,  0, 0,  0, 0,  0, 0,  0, 0,  2,10,  0, 0,  1000,
 0, 0,  0, 0,  0, 0,  0, 0,  0, 0,  0, 0,  2,10,  0, 0,  0, 0,  1000,
 0, 0,  0, 0,  0, 0,  0, 0,  2,10,  0, 0,  0, 0,  0, 0,  0, 0,  1000,
 0, 0,  0, 0,  0, 0,  0, 0,  0, 0,  0, 0,  0, 0,  0, 0,  2,10,  1000,
 0, 0,  2,10,  0, 0,  0, 0,  0, 0,  0, 0,  0, 0,  0, 0,  0, 0,  1000,
 0, 0,  0, 0,  0, 0,  2,10,  0, 0,  0, 0,  0, 0,  0, 0,  0, 0,  1000,
 0, 0,  0, 0,  2,10,  0, 0,  0, 0,  0, 0,  0, 0,  0, 0,  0, 0,  1000,
 2,10,  0, 0,  0, 0,  0, 0,  0, 0,  0, 0,  0, 0,  0, 0,  0, 0,  1000,
 0, 0,  0, 0,  0, 0,  0, 0,  0, 0,  0, 0,  0, 0,  0, 0,  2,10,  1000,
// dummy to end the pattern, with duration the effect for the next repeat, see effect
 0, 0,  0, 0,  0, 0,  0, 0,  0, 0,  0, 0,  0, 0,  0, 0,  0, 0,  -11
};


const PROGMEM prog_int16_t PatternSnakeRGB[] = {
//order led:
//ledTLF,   ledTLA,   ledTRF,   ledTRA,   ledBLF,   ledBLA,   ledBRF,   ledBRA,   ledMID,  duration
//snake red
 0, 0, 0,  0, 0, 0,  0, 0, 0,  0, 0, 0,  0, 0, 0, 64, 0, 0,  0, 0, 0,  0, 0, 0,  0, 0, 0,  1000,
 0, 0, 0,  0, 0, 0,  0, 0, 0,  0, 0, 0,  0, 0, 0,  0, 0, 0,  0, 0, 0, 64, 0, 0,  0, 0, 0,  1000,
 0, 0, 0,  0, 0, 0,  0, 0, 0,  0, 0, 0,  0, 0, 0,  0, 0, 0, 64, 0, 0,  0, 0, 0,  0, 0, 0,  1000,
 0, 0, 0,  0, 0, 0,  0, 0, 0,  0, 0, 0, 64, 0, 0,  0, 0, 0,  0, 0, 0,  0, 0, 0,  0, 0, 0,  1000,
 0, 0, 0,  0, 0, 0,  0, 0, 0,  0, 0, 0,  0, 0, 0,  0, 0, 0,  0, 0, 0,  0, 0, 0, 64, 0, 0,  1000,
 0, 0, 0, 64, 0, 0,  0, 0, 0,  0, 0, 0,  0, 0, 0,  0, 0, 0,  0, 0, 0,  0, 0, 0,  0, 0, 0,  1000,
 0, 0, 0,  0, 0, 0,  0, 0, 0, 64, 0, 0,  0, 0, 0,  0, 0, 0,  0, 0, 0,  0, 0, 0,  0, 0, 0,  1000,
 0, 0, 0,  0, 0, 0, 64, 0, 0,  0, 0, 0,  0, 0, 0,  0, 0, 0,  0, 0, 0,  0, 0, 0,  0, 0, 0,  1000,
64, 0, 0,  0, 0, 0,  0, 0, 0,  0, 0, 0,  0, 0, 0,  0, 0, 0,  0, 0, 0,  0, 0, 0,  0, 0, 0,  1000,
 0, 0, 0,  0, 0, 0,  0, 0, 0,  0, 0, 0,  0, 0, 0,  0, 0, 0,  0, 0, 0,  0, 0, 0, 64, 0, 0,  1000,
// dummy to end the pattern, with duration the effect for the next repeat, see effect
 0, 0, 0,  0, 0, 0,  0, 0, 0,  0, 0, 0,  0, 0, 0,  0, 0, 0,  0, 0, 0,  0, 0, 0,  0, 0, 0,  -11
};


const PROGMEM prog_int16_t PatternHeart[] = {
//order led:
//ledTLF,   ledTLA,   ledTRF,   ledTRA,   ledBLF,   ledBLA,   ledBRF,   ledBRA,   ledMID,  duration
 0, 0, 0,  0, 0, 0,  0, 0, 0,  0, 0, 0,  0, 0, 0,  0, 0, 0,  0, 0, 0,  0, 0, 0,  0, 0, 0,  1000,
 0, 0, 0,  0, 0, 0,  0, 0, 0,  0, 0, 0,  0, 0, 0,  0, 0, 0,  0, 0, 0,  0, 0, 0,  1, 0, 0,  1000,
 0, 0, 0,  0, 0, 0,  0, 0, 0,  0, 0, 0,  0, 0, 0,  0, 0, 0,  0, 0, 0,  0, 0, 0,  5, 0, 0,  1000,
 0, 0, 0,  0, 0, 0,  0, 0, 0,  0, 0, 0,  0, 0, 0,  0, 0, 0,  0, 0, 0,  0, 0, 0, 15, 0, 0,  1000,
 0, 0, 0,  0, 0, 0,  0, 0, 0,  0, 0, 0,  0, 0, 0,  0, 0, 0,  0, 0, 0,  0, 0, 0, 20, 0, 0,  1000,
 0, 0, 0,  0, 0, 0,  0, 0, 0,  0, 0, 0,  0, 0, 0,  0, 0, 0,  0, 0, 0,  0, 0, 0, 25, 0, 0,  1000,
 0, 0, 0,  0, 0, 0,  0, 0, 0,  0, 0, 0,  0, 0, 0,  0, 0, 0,  0, 0, 0,  0, 0, 0, 35, 0, 0,  1000,
 1, 0, 0,  1, 0, 0,  1, 0, 0,  1, 0, 0,  1, 0, 0,  1, 0, 0,  1, 0, 0,  1, 0, 0, 45, 0, 0,  1000,
 5, 0, 0,  5, 0, 0,  5, 0, 0,  5, 0, 0,  5, 0, 0,  5, 0, 0,  5, 0, 0,  5, 0, 0, 45, 0, 0,  1000,
15, 0, 0, 15, 0, 0, 15, 0, 0, 15, 0, 0, 15, 0, 0, 15, 0, 0, 15, 0, 0, 15, 0, 0, 55, 0, 0,  1000,
25, 0, 0, 25, 0, 0, 25, 0, 0, 25, 0, 0, 25, 0, 0, 25, 0, 0, 25, 0, 0, 25, 0, 0, 64, 0, 0,  1000,
35, 0, 0, 35, 0, 0, 35, 0, 0, 35, 0, 0, 35, 0, 0, 35, 0, 0, 35, 0, 0, 35, 0, 0, 64, 0, 0,  1000,
45, 0, 0, 45, 0, 0, 45, 0, 0, 45, 0, 0, 45, 0, 0, 45, 0, 0, 45, 0, 0, 45, 0, 0, 64, 0, 0,  1000,
55, 0, 0, 55, 0, 0, 55, 0, 0, 55, 0, 0, 55, 0, 0, 55, 0, 0, 55, 0, 0, 55, 0, 0, 64, 0, 0,  1000,
64, 0, 0, 64, 0, 0, 64, 0, 0, 64, 0, 0, 64, 0, 0, 64, 0, 0, 64, 0, 0, 64, 0, 0, 64, 0, 0,  1000,
64, 0, 0, 64, 0, 0, 64, 0, 0, 64, 0, 0, 64, 0, 0, 64, 0, 0, 64, 0, 0, 64, 0, 0, 64, 0, 0,  1000,
// dummy to end the pattern, with duration the effect for the next repeat, see effect
 0, 0, 0,  0, 0, 0,  0, 0, 0,  0, 0, 0,  0, 0, 0,  0, 0, 0,  0, 0, 0,  0, 0, 0,  0, 0, 0,  -1
};


const PROGMEM prog_int16_t PatternSiren[] = {
//order led:
//ledTLF,   ledTLA,   ledTRF,   ledTRA,   ledBLF,   ledBLA,   ledBRF,   ledBRA,   ledMID,  duration
 0, 0, 7,  0, 0, 0,  0, 0,64,  0, 0, 0,  0, 0, 7,  0, 0, 0,  0, 0,64,  0, 0, 0,  0, 0, 0,   100,
// dummy to end the pattern, with duration the effect for the next repeat, see effect
 0, 0, 0,  0, 0, 0,  0, 0, 0,  0, 0, 0,  0, 0, 0,  0, 0, 0,  0, 0, 0,  0, 0, 0,  0, 0, 0,  -90
};

#define test false //use serial monitor for testing (slows down update rate!)

/*************************************************/
/*       variables for input sampling            */
/*************************************************/
bool allowInput  = true;
int btnStatePrev = LOW;
int btnState     = LOW;
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

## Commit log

2014-01-25 Initial version of the manual for Fe Cube and the arduino sketches that accompany it
    [01_onepin_oneled.fzz, 02_twopin_oneled_npn.fzz, 03_twopin_oneled_npnreversed.fzz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]
2014-01-26 frames based RGB control
2014-01-26 Improved version based on frames
2014-01-26 improve arduino listing
2014-01-26 remove the need for frames.h
2014-01-28 Nicer monospace font Start with cube construction on breadboard
    [05_fecube_01.fzz, 05_fecube_02.fzz]
2014-01-29 Extended manual, going towards the real cube
    [05_fecube_02.fzz]
2014-01-29 pictures of first prototype
2014-01-29 Some fixes, working cube code
    [Fe_cube_03_cube_pattern.ino, Fe_cube_03_cube_test1.ino]
2014-02-01 Use flash memory for the patterns to avoid SRAM filling up
    [Fe_cube_03_cube_pattern.ino]
2014-02-01 fix bug in duration read
    [Fe_cube_03_cube_pattern.ino]
2014-02-02 Bug fixes, smoother working
    [Fe_cube_03_cube_intpattern.ino, Fe_cube_03_cube_pattern.ino, Fe_cube_03_cube_test1.ino]
2014-02-03 updating manual with Dutch updating with start for lesson on pushbutton control
    [05_pushbutton_01.fzz, 05_pushbutton_02.fzz, 05_pushbutton_03_cube.fzz]
2014-02-03 apply changes for cube control also to RGB led control
2014-02-05 Add event function to reaction to a button press
2014-02-08 The cube with pushbutton control to switch effect, switch off and do 3D6 dice roll
2014-02-08 small fix, update manual
    [Fe_cube_05_cube_pbtn.ino]
2014-05-04 * add pictures of current version * add a final script to show off basic version
2014-05-10 Towards interactive version with a dist sensor General framework for dist sensor in a short script here
    [Fe_cube_07_dist_sensor.ino]
2014-05-11 * Use speed of sound and max dist to calculate cutoff time needed to avoid flicker * Refractor code to a brightness function
    [Fe_cube_07_dist_sensor.ino]
2014-05-11 Start of an interactive cube version via a distance sensor
2014-05-11 Better comments on distance sensor Spec says 20uS wait needed, so reduce 1000 to 100uS in our case.
2014-05-13 A second distance sensor control scheme to change colors
2014-05-13 * Integrate second distance control scheme in full cube code * A reduced shotpattern form consisting of color and brightness per led. This allows control of these colors via the distance sensor
2014-05-19 tweaks correction on how speed of sound works
    [Fe_cube_07_dist_sensor.ino, Fe_cube_08_interact_showtime.ino]
2014-05-20 dist sensor, version with no delay by removing PulseIn function
2014-05-20 *introduce a scale without brightness *better control on hold: have a clear off *bug fix: add break on R2, R3
    [Fe_cube_08_interact_showtime.ino]
2014-05-27 The RGB led with pushbutton and a new effect: rainbow
2014-09-21 updates to the manual and arduino code 2
    [n01_rgbledtest.fzz, n02_rgbledsturing.fzz, n03_rgblednpn.fzz]
2014-09-22 figure and scheme for 4th schematic
    [n04_rgbledmultiplex.fzz]
2014-09-25 pictures for the manual
    [n05_fecube.fzz]
2014-09-28 reorganization img and new circuits of manual
    [n06_pushbuttontest.fzz, n07_pushbutton_status.fzz, n08_fecube_pushbtn.fzz]
2014-10-01 Add frame objects
    [ledcube_cover_v06.scad]
2014-10-05 Updates pictures of manual
    [n05_fecube.fzz, n08_fecube_pushbtn.fzz]
2014-10-05 avoid clashes in names
    [Fe_cube_07_dist_sensor_nodelay.ino, Fe_cube_08_interact_showtime.ino]
2014-10-05 Add distance sensor to cube and some effects for it

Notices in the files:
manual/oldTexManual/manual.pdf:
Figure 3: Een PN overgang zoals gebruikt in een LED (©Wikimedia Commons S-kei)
